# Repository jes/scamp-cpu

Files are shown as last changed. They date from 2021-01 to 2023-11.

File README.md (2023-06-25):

# SCAMP CPU

SCAMP is my homebrew 16-bit CPU. It stands for something like "Simple Computing and Arithmetic Microcoded Processor".

The CPU is very primitive. It doesn't support interrupts, and has no MMU, and no concept of privilege levels. It currently runs
at 1 MHz, above that the CompactFlash interface falls over. It runs a homebrew operating system, with a homebrew
programming language and compiler, and can self-host the kernel and all of the system utilities.
The environment tastes a bit like an early Unix, but works like CP/M. I used the computer to complete
almost all of [Advent of Code 2021](https://adventofcode.com/2021/).

My Advent of Code solutions are here: https://github.com/jes/aoc2021

I have some blog posts here: https://incoherency.co.uk/blog/tags/cpu.html and a web-based emulator available here: https://incoherency.co.uk/scamp/

Here are some pictures:

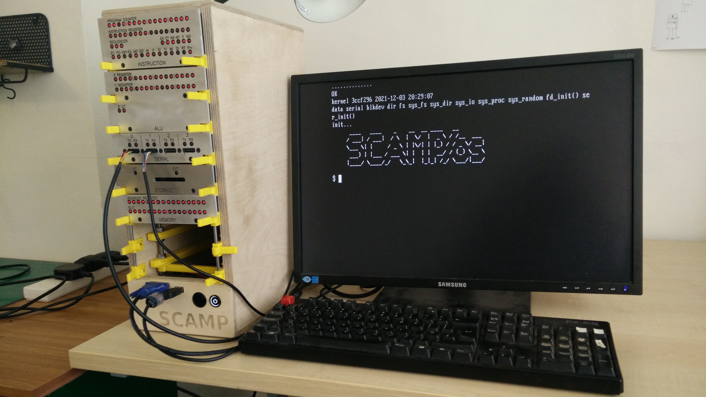
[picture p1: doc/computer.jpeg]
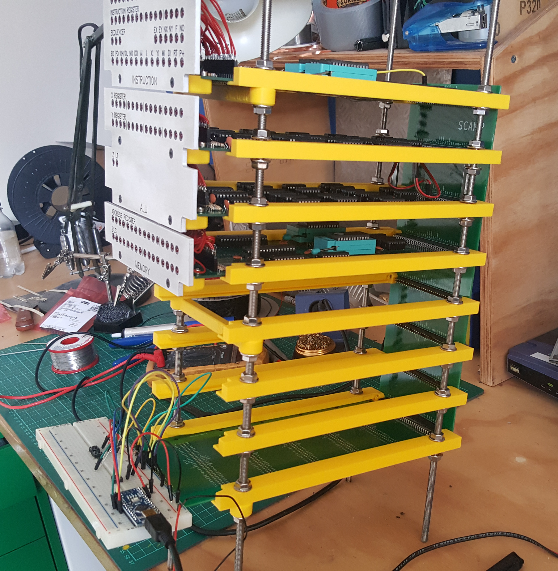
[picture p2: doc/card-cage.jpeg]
 

And here's a video with some explanation and an example session on real hardware:

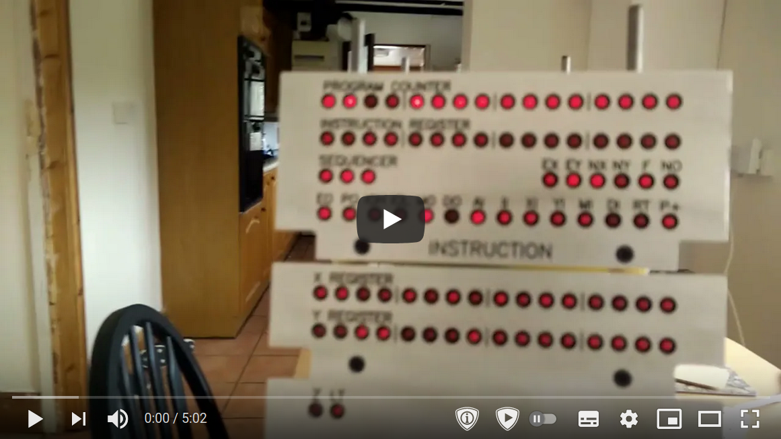
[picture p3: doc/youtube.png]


## Architecture

It is a 16-bit CPU. The bus is 16-bit, registers are 16-bit, addresses are 16-bit, and memory contents are
16-bit. The upper 8 bits of an instruction select the opcode, and the lower 8 bits are available
for small immediate values. There is no support for: cache, interrupts, virtual memory, DMA, privilege rings,
floating point, and ~anything else that is not strictly necessary.

Here is a diagram of the architecture:

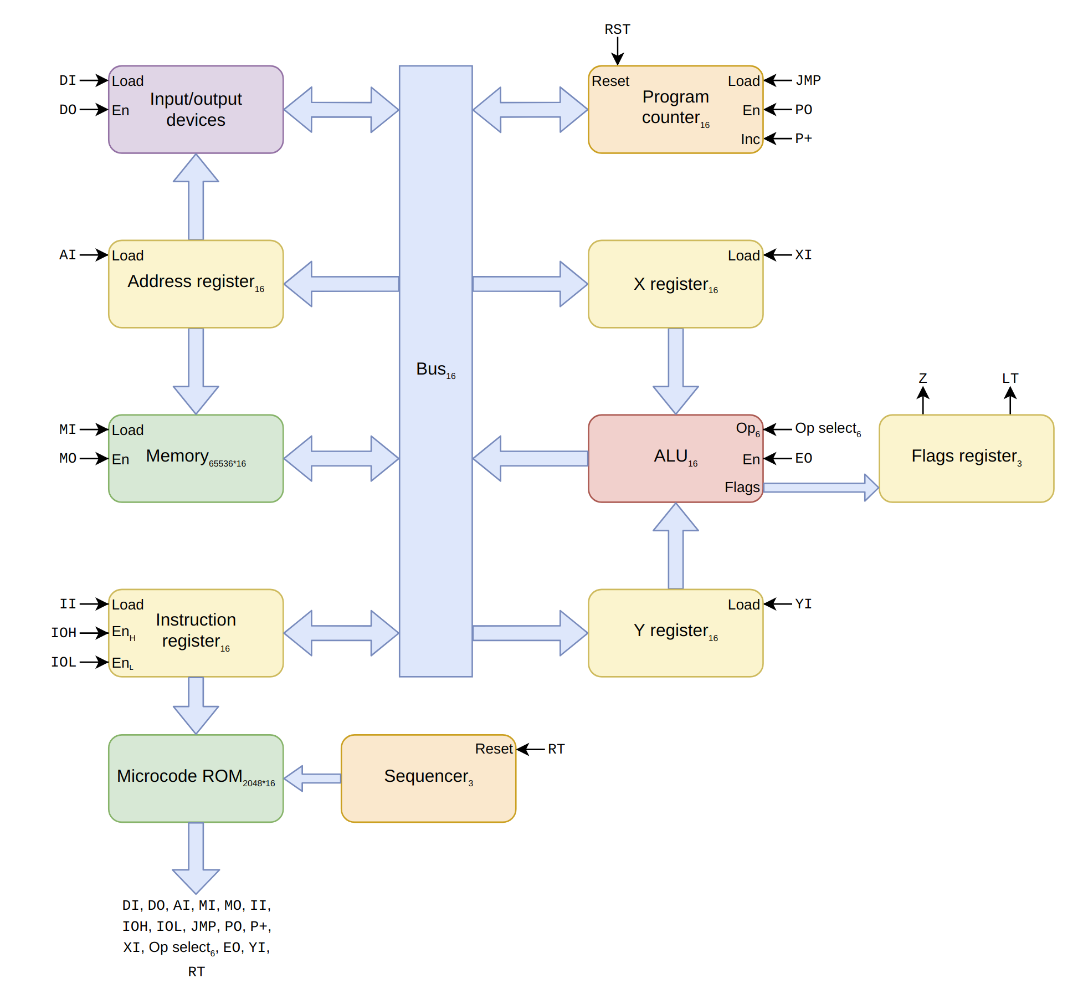
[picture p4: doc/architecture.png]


For more information, see [doc/UCODE.md](doc/UCODE.md) and [doc/ISA.md](doc/ISA.md).

## Try it out

The easiest way to try it out is to use the web-based emulator at https://incoherency.co.uk/scamp/

If you want to run it locally, first you'll need to build everything. Try `make -j` in the root directory of this
repository. It probably won't work on the first attempt because it works with multiple different Makefiles that have
annoying dependencies. Just run `make -j` twice or three times. If that doesn't do the trick, run `make` in `sys/` first, and then run
it in `.`. Once you get to the point that it is only complaining about `emcc`, you're done, unless you also
want to build the web-based emulator.

Having built everything, you can go into `kernel/` and start it in the emulator with `./run`:

    ~/scamp-cpu/kernel $ ./run
    make: 'os.disk' is up to date.
    SCAMP boot...
    .......................................................OK
    starting kernel...
    loading init...
          ____   ____    _    __  __ ____   __
         / ___| / ___|  / \  |  \/  |  _ \ / /__  ___
         \___ \| |     / _ \ | |\/| | |_) / / _ \/ __|
          ___) | |___ / ___ \| |  | |  __/ / (_) \__ \
         |____/ \____/_/   \_\_|  |_|_| /_/ \___/|___/

    $

If you know how to use Unix you'll probably understand how to use it. If you know how to use CP/M you'll probably
understand how it works.

If you want, you can write SLANG programs using `kilo` and compile them with `slc`. You've probably never written
SLANG before. You can learn how to use it by reading programs under `/src` (or `sys/` in the repo). It's mostly
like C but with fewer features and less safety.

## How it's made

I did these tasks, but working on several steps at a time (i.e. I didn't wait until after I had built the entire
computer before thinking about microcode or the operating system):

1. Create the CPU in Verilog, with a testbench for each part.
2. Replace the raw Verilog with Verilog that only uses 74xx-compatible primitives
   (e.g. https://github.com/TimRudy/ice-chips-verilog), but still passes the testbenches.
3. Convert the 74xx-Verilog into KiCad schematics (by hand).
4. Order the PCBs and components, solder up the PCBs, build a card cage, build a wooden case.
5. Settle on the instruction set and write the microcode (see [doc/table.html](doc/table.html), available online at https://incoherency.co.uk/interest/table.html).
5. Write a bootloader, kernel, shell, text editor, compiler, and various system utilities.

## Next steps

I suspect the computer will never be "finished", but some things I still want to work on are:

#### Hardware

 - [ ] build a hardware multiplication card (and maybe division?)
 - [ ] build a hardware RNG

#### Low-level software

 - [ ] make library blob self-hosting (compile within SCAMP/os)
 - [ ] write an strace-like debugging tool
 - [ ] write a DDT-like debugging tool
 - [ ] better facility for memory profiling (mainly to stop kilo and asm from running out of memory on large inputs)
 - [ ] atexit()
 - [ ] static initialisation of globals from constants (e.g. `var x = 5` at global scope should not take any code to initialise)
 - [ ] "const" variables (e.g. `const x = 5` should lead to `x` being replaced with the constant value `5` where possible)

#### Other software

 - [ ] write a big-fixed-point arithmetic library
 - [ ] fixed-point mathematics: pow,tan,asin,acos,atan,atan2
 - [ ] write a FORTH implementation (should it run on bare metal or under SCAMP/os?)
 - [ ] write a Z-machine interpreter and port some text adventures
 - [ ] write some games (pong? breakout? tetris?)

If you happen to want to work on any of the above, I'd be happy to help you!

## Resources

I thoroughly recommend the Nand2Tetris course. https://nand2tetris.org/

If you want to do the exercises from Nand2Tetris without learning what a hardware-description language
is, and without going through all the lectures, you can play https://nandgame.com/

Ben Eater's [videos on 8-bit CPU design](https://www.youtube.com/watch?v=HyznrdDSSGM&list=PLowKtXNTBypGqImE405J2565dvjafglHU) are excellent and heavily influenced
the design of my CPU.

I found the [YouTube playlist](https://www.youtube.com/playlist?list=PLOech0kWpH8-njQpmSNGSiQBPUvl8v3IM) for Nicolas Laurent's [compiler class](https://norswap.com/compilers/) quite helpful
in writing the parser for the compiler.

The [Build Your Own Text Editor](https://viewsourcecode.org/snaptoken/kilo/) is a fantastic tutorial that walks you through implementing
[antirez](https://github.com/antirez)'s [kilo](https://github.com/antirez/kilo) editor.

[Balazs Markus](https://github.com/bazsimarkus)'s [8250 UART example](https://github.com/bazsimarkus/Simple-8250-UART-System-with-Arduino) is helpful.

Daniel Tufvesson has a post that is a good starting point for understanding the [8-bit CompactFlash interface](http://www.waveguide.se/?article=8-bit-compact-flash-interface).

[PickledDog](https://github.com/PickledDog) has a description of an [improvement to the RC2014 CompactFlash card](https://github.com/PickledDog/rc-cfcard) that might be helpful. Also [Bill Shen's comment on the RC2014 mailing list](https://groups.google.com/g/rc2014-z80/c/LmvGa6PZNhQ/m/H8jrbp86AQAJ).

Michał Cierniak has a good blog post about [CompactFlash + 8255 interface card](https://ciernioo.wordpress.com/2015/02/10/compact-flash-8255-interface-card/) with lots
of detail on how his CompactFlash interface works.

[James Sharman](https://www.youtube.com/c/weirdboyjim) is building an interesting 8-bit pipelined CPU, and has good videos with lots of explanation on how it works.

SCAMP is featured on the [Homebrew CPU ring](https://www.homebrewcpuring.org/) which also features many other interesting homebrew CPU designs.

## Contact

You can email me on [james@incoherency.co.uk](mailto:james@incoherency.co.uk)
or read my blog: [https://incoherency.co.uk/].

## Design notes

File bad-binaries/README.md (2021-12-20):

This directory contains samples of bad binaries to try and help me debug
the "bad binary" problem, which is that sometimes the compiler outputs
a binary that behaves incorrectly, and then when recompiled the exact
same source code produces a binary that works fine.

My best guess is that there is a hardware problem, but currently I'm just
collecting samples in case any patterns become clear.

I had a first look at it here: https://www.youtube.com/watch?v=BiFeisFLKhY

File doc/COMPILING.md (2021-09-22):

# Compiling

This document is about compiling software within **SCAMP/os**. For more general
thoughts on the compiler, see COMPILER.md instead.

## Basic usage

    $ kilo foo.sl
    $ slc < foo.sl > foo
    $ ./foo

## Linking

To keep the library blob small, the bigint and fixed-point code is not included
by default. Ideally we'd be able to link against arbitrary combinations of
libraries, but for now the compiler only supports a single library blob, which
means if we want to support different options then we need to have a
pre-compiled blob for each possible combination.

If you need to use either the `fixed` or `bigint` libraries, then you need to
tell `slc` to select the appropriate library blob by passing it a blob name in
`-l`. Example:

    $ slc -lfixed < foo.sl > foo

Available blobs are:

             - normal library
    fixed    - normal library, plus `fixed.sl`
    bigint   - normal library, plus `bigint.sl`
    bigfix   - normal library, plus both of `fixed.sl` and `bigint.sl`

For more explanation of how linking works, see LINKING.md.

## Workings

`slc` is the compiler driver. It delegates to `slangc` to turn source code into
assembly language, and `asm` to turn assembly language into machine code. It also
brings in pre-packaged assembly language source for the "head" and "foot" of
the program, from `/lib/head.s` and `/lib/foot.s`, and library definitions
from `/lib/lib.s` (or `/lib/libfoo.s` in the case of `-lfoo`).

`head.s` is responsible for setting the start address of the program code
to 0x100, initialising the stack pointer, allocating space to store the `TOP`
variable, and defining constants for system call vectors.

`foot.s` is responsible for calling `exit(0)` after the program finishes,
and defining a constant for the initial value of `TOP`.

`lib.s` is responsible for including the library blob from `/lib/lib.o`, and
defining the addresses of the symbols exposed by the library.

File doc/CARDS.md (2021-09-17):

# Cards

## Physical dimensions

Cards are 237.49 mm long, 102.87 mm wide.

The backplane connector is at the back of the card, on the top side, in the centre. The rearmost holes
for the backplane connector pins are set forward 2.54 mm from the rear edge of the card.

Mounting holes for the front panel are set back 5.08 mm from the front edge of the card and set in 7.62 mm
from the side edge of the card. The holes are 3.2 mm in diameter, intended to take an M3 screw.

Leave a good few mm clear of components at each side of the card to slide in the guide rails.

For designing front panels, start with e.g. `front-panels/memory-panel.FCStd` and move the holes to suit
the card, then use e.g. `front-panels/memory-panel.svg` in Inkscape to lay out the text. Then engrave the
text in aluminium plate using the CNC machine (use gcodetools "path to gcode" in Inkscape) and then cut
the part out using a 4mm end mill.

Vertical spacing between cards in the backplane is 40 mm.

## ALU

The ALU is comprised of 2 identical PCBs, populated differently.

The lower card stores the low byte of the X and Y register,
and computes the low byte of the ALU output, and has the bus connection solder-jumpers connected to the low byte of the bus.

The upper card stores the high byte of the X and Y register, stores the flags register, computes the high byte of the ALU output,
and has the bus connection solder-jumpers connected to the high byte of the bus.

All parts not explicitly mentioned below must be populated on both cards (including LED connection headers and the backplane connector).

### Lower card

Do not populate U4 (flags register) or U6 (computes the Z flag). Do not populate the corresponding capacitors, C10 and C23.

Using either a male pin header or a wire, connect "carry" to "GND" on J6 (the "in" jumper). "nz"
on J6 can be left disconnected.

Install a male pin header on J7 (the "out" jumper).

Do not populate J5 (flags register LED header). Do not populate the corresponding resistors, R28 and R29.

### Upper card

Install a male pin header on J6 on the *bottom* of the card.

Do not populate J7.

### Assembly

Use 2 jumper wires to connect "nz" and "carry" from J7 of the lower card to J6 of the upper card.

Use standoffs and M3 screws to connect the two cards together using the mounting holes at the back.

Plug in the LED wires from the aluminium front panel to the appropriate headers.

Use standoffs, M3 screws, and the front panel to connect the two cards together using the
mounting holes at the front.

Hopefully the card can now slide into the chassis and connect to the backplane.

## Instruction

The EO, PO, IOH, IOL, ... header for LEDs has polarity reversed. The last pin has VCC instead of
ground, and the signals are active-low.

Unused microcode decodings can be exposed on the backplane via jumpers. The available decodings are:

| Label | Microcode | Backplane pin | Notes |
| :---- | :--- | :--- | :---- |
| i7 | bus_in==7 | 27 | |
| u8 | bit 8 | 37 | pin used for `DO` |
| o7 | bus_out==7 | 36 | |
| o5 | bus_out==5 | 35 | pin used for serial console |
| o4 | bus_out==4 | 34 | pin used for serial console |
| u1 | bit 1 | 33 | pin used for `RT` |

Microcode bit 0 is exposed on backplane pin 32 without a jumper, and the pin is now used for `DI`.

### Errata

ZIF socket holes are too small. My solution was to solder some clipped-off LED legs onto the ZIF socket
pins and then solder these to the PCB.

U8 and U9 (bus_in/out decode) should have pins 4 and 5 (chip enable) tied to VCC instead of GND.

U9 (bus_in decode) should have pin 6 (chip enable) tied to VCC instead of EO_bar.

U17 should have pin 3 output inverted:

 * pop pin 3 out of socket
 * connect pin 3 of IC to pins 9+10
 * connect pin 8 of IC to pin 3 of socket

`RT` needs to come directly from a microcode bit rather than being decoded, because it acts immediately and can "glitch".
To match current generated microcode:

 * pop pins 4+5 of U5 out of socket
 * connect pins 4+5 of U5 to the "u1" pin of "spare decodings"

We have the same problem with `DO`/`DI`, when device I/O can cause side effects. The solution is:

 * on the bottom of the card, solder a link between backplane connector pins for `DI` and `U0`
 * on the top of the card, stick a jumper on the "spare decodings" pin labelled "u8" and solder it on to the backplane
   connector pin for `DO`

## Memory

### Errata

ZIF socket holes are too small. Initially I just forced them into the holes, but this bent the legs of the
"high byte" ROM socket, and I had to replace it. Better solution is to solder clipped-off LED legs onto the
socket pins and then solder these to the PCB.

## Backplane

### Errata

Spare pin assignments:

 * 27: "spare_i7": **free**
 * 32: "U0": used for `DI`
 * 33: "spare_U1": used for `RT`
 * 34: "spare_o4": serial console
 * 35: "spare_o5": serial console
 * 36: "spare_o7": **free**
 * 37: "spare_U8": used for `DO`
 * 38: "unused": used for `WR` signal generated by serial card

## Serial

Initially, only populate the oscillator circuit on UART 0.

    Crystal: 1.8432 MHz
    Caps: 30 nF
    Resistor: 100 Ohm

Ideally, the 4 solder jumpers in the middle can be bridged, to share the 1.8432 MHz oscillator between
all of the UARTs. If that is not possible, then un-solder them and populate the other oscillators as well.

The 2x5 pin connector is for jumpers to allow easy disconnection of signals from the connector. The 1x6 connector
should go up with wires to the connector on the front panel.

Each UART has 8 addresses, consecutive starting from a base address. A7 (0x80) needs to be high to select the
UARTs, and then there's 1 bit (A3,A4,A5,A6) of address to select each UART.

Addresses:

    UART 0: A3+A7: base address = 136
    UART 1: A4+A7: base address = 144
    UART 2: A5+A7: base address = 160
    UART 3: A6+A7: base address = 192

It would probably work to initialise all of the UARTs by setting all 5 address bits high, which is base address = 248.

I plan to only install UART 0 at first, and then populate the rest of the slots as and when I want to use them.

### Errata

Use bodge wire to connect `WR` pin to backplane pin 38, marked "unused" on backplane.

Use bodge wire to connect `TX` pin of UART 0 to pin 34, marked "spare_o4" on backplane.

Use bodge wire to connect `RX` pin of UART 0 to pin 35, marked "spare_o5" on backplane.

LEDs need to be wired with signal on cathode and VCC on anode.

## Storage

1 card is internal, the other card is removable through the front panel.

Each card has 2 CS pins. A8 (0x100) needs to be high to select the CompactFlash, and then there's 1 bit
(A3,A4,A5,A6) of address to select each CS pin.

Addresses:

    Card 1, CS0: A3+A8: base address = 264
    Card 1, CS1: A4+A8: base address = 272
    Card 2, CS0: A5+A8: base address = 288
    Card 2, CS1: A6+A8: base address = 320

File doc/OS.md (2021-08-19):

# Operating System notes

We have a very short boot ROM permanently mapped into memory at address 0, 256 words long.
When the machine is reset the PC is reset to 0 which causes the boot ROM to execute.
The boot ROM's only job is to liaise with the CompactFlash card and load the kernel
from the first N KBytes from the storage into RAM and then jump to it. See [BOOT.md](BOOT.md).

The kernel contains implementations of the system calls, and space for system buffers, etc.

At startup, the kernel just executes `/bin/init`.

The intention is to support a workflow that is kind of in between CP/M and FUZIX. The filesystem
supports directories instead of CP/M's silly drive letter and user number system. The OS provides a `system()`-like call
by swapping the existing program out to disk, making a note of where to reload it from and what address to jump to, and then loading the called program.
Calling another program works a lot like calling a function, in the sense that you completely lose control until
the callee is done, and then when it's done you get returned to. We have a process *stack* instead of a process *tree*.

## Filesystem

`SCAMP/os` has a pretty Unix-like filesystem, but without annoying features like device nodes, symlinks, permissions, or
reference counting.

Example:

    /bin
        asm
        cat
        cmp
        cp
        grep
        init
        ls
        mkdir
        peepopt
        rm
        sh
        slangc
        slc
        vi
    /etc
        motd
        [other configuration?]
    /home
        [user files]
    /src
        [source code of kernel and all programs]
    /proc
        [contents of swapped-out processes]

## Programs

### init

Probably just system("cat /etc/motd") and exec("sh")

### sh

Since the shell is just a program, and programs can call other programs via the swapping-to-disk system,
the shell could quite easily support pipes and IO redirection. Currently it supports IO redirection but
not "pipes".

For the command:
    $ cat foo.txt | grep bar

The shell would first open a temporary file for writing. It would set stdout to point to that file.
It would system("cat", "foo.txt").

The kernel would then swap the shell out to disk and execute cat, whose stdout goes to the temporary
file. Once cat calls exit(), the kernel
would swap the shell back into memory and jump to the return address for the system() call.
From the shell's perspective, the system() call would return.

At this point the shell would set stdout to point back to whatever it was originally set to, and then
set stdin to point to the temporary file. It would then system("grep", "bar").

The kernel would then swap the shell out once again, and this time execute grep, whose stdin
comes from the temporary file. Once grep calls exit(), the kernel would swap the shell back in
and the second system() call would return.

This method doesn't allow for example `cat foo.txt | head` to bail out of the cat early (i.e. you don't
get a SIGPIPE when `head` is finished reading, because `head` doesn't start until `cat` is finished),
but it still provides a lot of the useful properties of program composition, without needing to support actual multitasking.

### asm/slangc/slc/peepopt

These form a complete self-hosting build environment.

    asm: assembler
    slangc: compiler
    slc: compiler driver (slangc foo.sl | peepopt > foo.s; cat head.s foo.s foot.s | asm > foo)
    peepopt: peephole optimiser (not yet implemented)

### vi

I definitely want a text editor that works like vi. It doesn't need to do everything that vim does, I'll be happy as long
as my "finger macros" mostly function correctly. I read that nobody uses more than 20% of vim's features, but the
problem is everyone uses a different 20%. Well as long as it supports the 20% that I use, I'll be happy.

Currently the editor is `kilo`, which is not very vi-like. It's more nano-like. It's adequate for now. It seems
unlikely that I'll ever make it vi-like, it seems good enough.

## IO

The kinds of places that a program might want to read or write include:

 - files on disk
 - serial devices (I want at least 2, might not be too hard to support more, and the hardware has provision for 4)

Currently serial devices are implemented with fixed file descriptors. Fd 3 is always the
serial console. It might be worth making a new file type for "device files" so that the
console can be found by opening `/dev/console` instead of assuming it's always at fd 3.
The "fixed fd" system is *OK* for now, but would not scale very well, especially given that
the fd table only has 16 slots.

I'm not sure whether interacting with a second CompactFlash card would be done via a userspace
program, or whether it would be "mounted" somewhere in the main filesystem. Currently the hardware
has 2 slots for CompactFlash cards, but there is a serious problem with the second one which means
the computer does not work if the second CF card is installed. Need to debug this.

## Process state

When a process is swapped out, in addition to storing the contents
of the Transient Program Area (0x100 up to `TOP`) in `/proc/$n.user`,
we need to store some state about the process in `/proc/$n.kernel` (see
`kernel/sys_proc.sl`):

 - current stack pointer
 - return address from `system()` call
 - current working directory
 - contents of fd table
 - command line arguments

## Conventions

"Executables" work exactly like COM files in CP/M: just load them into 0x100 and jump to the start.

Command line arguments are stored by the kernel. A pointer to the
array of string pointers is retrieved with the `cmdargs()` syscall.

There is no such thing as environment variables.

Shebangs work.

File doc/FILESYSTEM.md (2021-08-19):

# Filesystem

The filesystem consists of 512-byte blocks.

The first 64 blocks (32K) on the device are ignored. They're used to store the kernel.

The next 16 blocks (8K) are a bitmap saying which of the rest of the blocks are already in use.

The next up-to-65536 blocks (32M) are the filesystem contents.

Where the device is smaller than 32M, the bitmaps should mark the unavailable blocks as "in use".

The first 4 bytes of each block are decoded as follows:

    |    type       |  length       |       next block pointer      |
    |. . . . . . . .|. . . . . . . .|. . . . . . . .|. . . . . . . .|

(Although 8 bits are currently allocated for "type", only types 0 (directory) and
1 (file) are assigned; the upper 7 bits are currently unused).

"length" is 8 bits, indicating how many words of the current block is to be used for
this node, not including the header.

"next block pointer" contains the number of the next block that forms part of this
file or directory, or 0 if this is the last block.

See below for examples.

Block 0 is the root directory of the filesystem.

## Type 0 (directory)

After the 4 byte header, the remaining 508 bytes consist of up to 15 directory entries.

The length field is ignored. The "next" block (if nonzero) contains more files for
the same directory.

Each directory entry has a filename (up to 30 bytes) and a block pointer (2 bytes). Filenames
are nul-terminated strings. The empty filename indicates a directory entry is not in use.

## Type 1 (file)

After the 4 byte header, the remainder of the block (up to the amount set in the "length"
field) are file contents. Where blocks are chained together, the current block's contents
come first, and then the next block.

A block containing a file that just contains the character "A" would look like:

    |    type       |  length       |       next block pointer      | ... data ...  |
    |0 0 0 0 0 0 0 1|0 0 0 0 0 0 0 1|0 0 0 0 0 0 0 0 0 0 0 0 0 0 0 0|0 1 0 0 0 0 0 1|

    type = 1 (file)
    length = 1
    next = 0
    data = 'A'

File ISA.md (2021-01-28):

# Instruction Set Architecture

Each word is 16 bits wide.

The high 8 bits of the opcode select the actual opcode. The low 8 bits are available
for an immediate small-valued constant. XXX: We could change this to 9/7 or 10/6 if
we need more opcode space.

## Addressing modes

There are kind of 2 orthogonal questions here: 1 is where the address comes from, and the other
is how many levels of indirection it takes.

Numbers can come from:
 * the low bits of the instruction word (IOH)
 * the low bits of the instruction word (IOL)
 * an operand word
 * the X register
 * the Y register

Levels of indirection:
 * immediate value
 * 1 trip through RAM
 * 2 trips through RAM
 * 3 trips through RAM
 * 1 trip through RAM with pre-/post- increment/decrement
 * 2 trip through RAM with pre-/post- increment/decrement of pointer
 * 2 trip through RAM with pre-/post- increment/decrement of value

We could consider "hiding" the Y register, so that it can always be clobbered without needing
an excuse. And then the opcode space saved by removing instructions that store to Y can for
example be used for instructions that instead fetch indirect values into Y. It would probably
be worth writing some simple-ish programs in the instruction set as defined here and seeing if
there are any obvious candidates for creating instructions that do the job of 2 at once.

Even if we don't hide "Y", it should be a point of philosophy that instructions will clobber the
Y register in preference to the X register where there is a free choice.

Apart from instructions that do specifically require an imm8h, we should flesh out the instruction
set with all immediate values as imm16, and then add optimised versions later for common
operations.

We could consider the imm8h addresses to be "registers", and make a "r0" .. "r255" syntax for
addressing them. So then instead of "add x, (0xff00)", you'd be able to write "add x, r0" and
it all becomes much easier to read. It also clarifies the difference between the (imm16) and (imm8h)
addressing modes, and we could potentially make the assembler warn if you use a (imm16) that is in
the top page.

## Instruction table

I'd like to produce a table like the one on https://clrhome.org/table/

It's a grid indexed by opcode, with each cell in the grid indicating the instruction
with that opcode. Destinations are the first argument, e.g. "ld a, b" means load the contents
of b into a. Indirection is given with parentheses, e.g. "ld (hl), a" means load the contents
of a into memory at the address stored in hl.

Hovering over an instruction pops up a box with more information. Information I would want to
show includes:

 * opcode in hex
 * instruction length in words
 * clock cycles to execute it (including 2 for fetch)
 * whether it clobbers or not for each of X, Y, flags, and memory (do we
    make a distinction between "writes to" and "clobbers"? e.g. "ld x, *" writes to X, so
    you lose what was already in X, but it's not exactly "clobbered"), and the nature of
    the clobber (e.g. if the new value might be useful)
 * a short description of what it does
 * the microcode implementing it, source and hex

Ideally this would all be auto-generated from information in the microcode source.

It would also be cool if the assembler could use the microcode source to define the available
opcodes, with as little hardcoding as possible.

## Instructions

The registers are called "x" and "y". Immediate values
are called "imm8l" if produced with "IOL" (0 to 255), "imm8h" if produced with "IOH" (0xff00 to
0xffff), or "imm16" if produced with an extra word operand, in which case the operands
should appear in the machine code in the same order as they appear in the mnemonic.
"r" means one of the pseudo-registers r0 to r255, which is equivalent to an "(imm8h)" argument.
"sp" means r255, i.e. "(0xffff)".

The assembly language should be as orthogonal as possible, with the assembler responsible for
deciding which opcode to use, e.g. "ld x, 5" can be accomplished with both "ld x, imm8l" and
"ld x, imm16".

The instructions listed below are currently aspirational. The list might have to be cut down if
the opcode space is not large enough, and some opcodes might not be implementable without
exceeding 6 T-states. We also might be able to add more if there is opcode space left over.

Where instructions clobber an address in memory (e.g. xor), there should probably be a
default that is normally used, and also some syntax to choose an alternative.

We should make sure that where 2 opcodes can perform an equivalent operation (e.g. "ld x, imm8h"
and "ld x, imm16") that the shorter/faster/better one has the lower opcode, so that the assembler
can know to always choose the smallest opcode that can fulfill an instruction.

In total we currently have 165 opcodes.

### Load/store

42 opcodes:

    ld x, y
    ld y, x
    ld x, imm16
    ld y, imm16
    ld x, (imm16)
    ld y, (imm16)
    ld x, ((imm16))
    ld y, ((imm16))
    ld (x), x
    ld (x), y
    ld (y), x
    ld (y), y
    ld (imm16), x
    ld (imm16), y
    ld ((imm16)), x
    ld ((imm16)), y
    ld x, pc
    ld y, pc
    ld x, (imm16+x)
    ld y, (imm16+x)
    ld x, (imm16+y)
    ld y, (imm16+y)
    ld x, ((imm16)+x)
    ld y, ((imm16)+x)
    ld x, ((imm16)+y)
    ld y, ((imm16)+y)
    ld x, (imm16)++
    ld x, (imm16)--
    ld y, (imm16)++
    ld y, (imm16)--
    ld x, r
    ld y, r
    ld r, x
    ld r, y

### Jump

34 opcodes:

    jmp imm16
    jz  imm16
    jnz imm16
    jgt imm16
    jlt imm16
    jge imm16
    jle imm16
    jc  imm16
    jmp (imm16)
    jz  (imm16)
    jnz (imm16)
    jgt (imm16)
    jlt (imm16)
    jge (imm16)
    jle (imm16)
    jc  (imm16)
    jmp (x)
    jz (x)
    jnz (x)
    jgt (x)
    jlt (x)
    jge (x)
    jle (x)
    jc (x)
    jmp (y)
    jz (y)
    jnz (y)
    jgt (y)
    jlt (y)
    jge (y)
    jle (y)
    jc (y)
    jr imm8l # imm8l is a positive offset
    jr imm8l # imm8l is a negative offset

### Arithmetic

20 opcodes:

    inc x
    inc y
    dec x
    dec y
    inc (x)
    inc (y)
    dec (x)
    dec (y)
    inc (imm16)
    dec (imm16)
    add x, x
    add x, y
    add x, imm16
    add x, (imm16)
    add x, (imm16)++
    add x, (imm16)--
    sub x, y
    sub x, (imm16)
    sub x, (imm16)++
    sub x, (imm16)--

So far this mostly includes register and immediate-mode arguments. If opcode space
allows, we could add some memory operands for either source or destination, as well
as opcodes for the more elaborate ALU operations like "X+Y+1", "-X-Y-2".

The assembler could also provide "sub r, imm16" as "add r, -imm16" and
"sub r, r" as "ld x, 0".

### Logic

42 opcodes:

    and x, y
    and y, x
    and x, imm16
    and y, imm16
    or x, y
    or y, x
    or x, imm16
    or y, imm16
    not x
    not y
    nand x, y
    nand y, x
    nand x, imm16
    nand y, imm16
    nor x, y
    nor y, x
    nor x, imm16
    nor y, imm16
    xor x, y
    xor y, x
    xor x, imm16
    xor y, imm16

Again we could add some memory operands if opcode space allows.

### I/O

10 opcodes:

    in x, imm16
    in x, y
    in y, imm16
    in y, x
    out x, y
    out y, x
    out imm16, x
    out imm16, y
    out imm16, imm16
    out imm16, imm16

Device numbers and data are both 16 bits wide.

The first argument refers to the place that receives the data, so "out" takes the device number
first and "in" takes it second. We could look at the kinds of I/O that are likely to be common
and see if adding any memory operands would be helpful. In particular, the large block copy
of the TPA to disk should be optimised.

### Stack

11 opcodes:

    push x
    push y
    push r
    push (x)
    push (y)
    push (r)
    push imm16
    push (imm16)
    pop x
    pop y
    pop r
    pop (x)
    pop (y)
    pop (r)
    pop (imm16)
    ret

The stack pointer is always r255.

"push" post-decrements sp, and "pop" pre-increments it. "ret" is basically just "pop pc".

### Misc

1 opcode:

    nop

## Special instructions

5 opcodes:

    djnz x, imm16
    djnz y, imm16
    djnz (imm16), imm16
    tbsz r, imm16
    sb r254, imm8l

Decrement and jump if not zero. Test bits and skip if zero. Set bits in M[0xfffe].

Also consider making single instructions that do things like:

    ld (imm16), x
    inc (imm16)

or
    ld x, (imm16)
    inc (imm16)

## ALU & Load

We could easily make instructions like:

    ld (imm16), x+y
    ld (imm16), x-y
    ld (imm16), x-1
    ld (imm16), x+1
    ld (imm16), y-1
    ld (imm16), y+1
    ...
    ld x, (imm16)+y
    ld x, (imm16)-y
    ld y, (imm16)+x
    ld y, (imm16)-x
    ld x, (imm16)-1
    ld x, (imm16)+1
    ...

For all of the sensible ALU operations. Just a case of working out which ones are useful

## Calling convention

The microcode is a bit too restricted to make an instruction that would push PC+2 and jump to an
argument, so the general method of calling would be to have the assembler generate the hardcoded
return address, and push it, and then jump to the callee.

In general, calling is:

    0: push (SP), 4 # push (SP), imm16
    2: jmp imm16
    4: ...

In the event that position-independent code is required, use something like:

    0: ld x, pc
    1: add x, 4      # with the "add x, imm8l" opcode (1 word)
    2: push (SP), x
    3: jmp imm16
    5: ...

The "ret" instruction can be used to return to the caller. It pops the return address
from the stack and jumps to it.

    0: ret

### Shift-right

These 2 instructions are kind of a bodge to support shift-right:

tbsz (test bits and skip if zero), sb (set bits)

tbsz takes the address of the value from IOH, and a bitmask as an argument, and skips the program
counter over the next 1-word instruction if none of the bits set in the value are also set in
the bitmask (i.e. if "val & mask == 0").

sb is a 1-word instruction that computes "M[0xfffe] |= IOL", i.e. OR's some of the lower
8 bits set in IOL into the value in M[0xfffe].

Use it by repeatedly tbsz of some value in the upper 8 bits, followed by sb of the
same value in the lower 8 bits:

    tbsz(0xff) 0x8000 # skip next if !(M[0xffff] & 0x8000)
    sb(0x80)          # M[0xfffe] |= 0x80
    tbsz(0xff) 0x4000 # skip next if !(M[0xffff] & 0x4000)
    sb(0x40)          # M[0xfffe] |= 0x40
    ...

so the >>8 operation takes up to 8*(8+6) = 112 cycles, plus setup time

### CISC

The microcode potentially gives us a lot of freedom to do more complicated things:

djnz of X: (Decrement and jump if not zero)

    [opcode] [jump target]

    1. ALU=X-1 EO XI    load X-1 into X
    2. PO AI            load address from PC (jump target)
    3. MO JGT JLZ P+    jump to address from RAM if X-1 != 0, else inc PC

Could we do something like ldir from Z80 (i.e. copy a block of data using 1 instruction that
keeps jumping to itself until the block is done)? My sense is no, because there aren't enough
registers or T-states. But it might be possible. Also might be possible to make a pair of
special-purpose instructions, like tbsz and sb, that make block copies faster than the simple way.

## Assembly language

Each line is 1 instruction or 1 assembler directive. Each line optionally begins
with 1 or more labels. The label will refer to the address at which the assembly code
for that point will be loaded into memory.

A "#" character begins a comment that runs to the end of the line.

## Directives

### .def WORD TEXT

Preprocessor macro. All subsequent occurrences of "WORD", at word boundaries, will be
replaced verbatim with the TEXT, with excess spaces stripped.

Example:

    .def SP 0xff00     # stack pointer at 0xff00
    .def SP_x (SP), x

Would transform:

    push (SP), x
    push SP_x

into:

    push (0xff00), x
    push (0xff00), x

### .org VALUE

Set the address at which the first word of the generated output will be loaded into memory.

Example:

    .org 0x100

### .at VALUE

Set the address at which the next word should be loaded into memory. Use in combination with
.org to make sure everything is where you expect.

Example:

    .org 0x100
    ld x, (ptr)
    out 0x80, (x)
    ...
    ptr: .word 0x200
    .at 0x200
    .str "Hello, world!"

Padding words with value 0x0000 will be generated between the location of "ptr" and the
"Hello, world!" string, such that the string will be located at address 0x200 if the generated
output is loaded at 0x100 (i.e. the string will be 0x100 words into the generated output).

### .gap VALUE

Leave a gap of N unused words

Example:

    .at 0x200
    buffer: .gap 256

Creates a 256-byte buffer at address 0x200, with the label "buffer".

### .str "TEXT"

Generate the given string, with 1 character per word (i.e. the upper 8 bits of each value is
always zeroes).

Example:

    msg: .str "Hello, world!\n"

### .pstr "TEXT"

Generates a "packed string", with 2 characters per word, with the first character of the string in
the upper 8 bits of the first word (i.e. big endian).

Example:

    msg: .pstr "Hello, world!\n";

### .word VALUE

Generate a literal word.

Example:

    value: .word 0x1010

Will generate a word containing 0x1010, whose address will be available in the "value" label.

## Labels

Labels and macro names must match

    /^a-zA-Z_[a-zA-Z_0-9]*$/

i.e. begin with uppercase, lowercase, or underscore, and then contain only uppercase, lowercase, underscore, and numeric.

## Values

Values are decimal by default.

Hex values are written starting with "0x", and binary values starting with "0b".

All numeric values are 16 bits long, but in special cases the assembler may put them in an imm8l
or imm8h where possible.

Inside strings, the following escape sequences are available:

* "\\" - literal backslash
* "\r" - 0x0d value
* "\n" - 0x0a value
* "\t" - 0x09 value
* "\[" - 0x1b value
* "\x.." - literal hexadecimal 8-bit value
* "\w...." - literal hexadecimal 16-bit value (not allowed in packed strings)
* "\0" - literal 0, same as "\x00"

Example values:

    .word 100
    .word 0x123
    .word 0b1010111100000101
    .str "ABC\wffffDEFG\r\n\0"
    .pstr "ABCD\x1b\n\0"

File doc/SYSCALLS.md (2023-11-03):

# System calls reference

System calls are made by pushing arguments onto the stack, in the order specified
in the reference, and calling the function pointed to at the system call address.

Example:

    # write(1, "foo", 3);
    .def sys_write 0xfefb
    push 1
    ld x, foo_s
    push x
    push 3
    call (sys_write)
    # ...
    foo_s: .str "foo\0"

Note that stack contents will be in TPA, so system calls that overwrite the TPA
probably need to copy the arguments first.

System calls must act like normal SLANG functions: `r255` (`sp`) must consume the passed
arguments. `r254` must be left alone. Other pseudoregs can be trashed at will.

## System calls

### 0xfeff: exit(rc)

    Return: n/a
    Implemented: yes
    Errors: n/a

Exit the current process and return `rc` to the parent. Negative values of `rc` are discouraged
as they are indistinguishable from an error value returned by `system()`.

### 0xfefe: exec([cmd, args])

    Return: -ERR on error
    Implemented: yes
    Errors: NOTFOUND

Replace the current process with a new one.

`cmd` should be a filename. `args` should be terminated with a 0.

### 0xfefd: system(TOP, [cmd, args])

    Return: rc of child process, or -ERR on error
    Implemented: yes
    Errors: NOTFOUND

Suspend the current process, start a child. When the child calls `exit(rc)`, resume the
current process and return `rc`.

`cmd` should be a filename. `args` should be terminated with a 0.

### 0xfefc: getcwd(buf, sz)

    Return: 0, or -ERR on error
    Implemented: yes
    Errors: TOOLONG

Work out the current working directory and store it in `buf`. Behaviour is undefined
if the current working directory or one of its parents has been deleted. Return `TOOLONG`
if the path is too long to fit in `buf` with a trailing 0.

### 0xfefb: write(fd, buf, sz)

    Return: 0, or -ERR on error
    Implemented: yes
    Errors: BADFD

Write multiple characters to the given file descriptor.

Avoid writes larger than 2^15-1 because the return value will be indistinguishable
from an error value.

### 0xfefa: setbuf(fd, buf)

    Return: 0, or -ERR on error
    Implemented: yes
    Errors: BADFD

Set the buffer to use for the given `fd`. If `buf` is 0, the `fd` will be unbuffered, and all
writes and reads will go directly to disk. If `buf` is nonzero, it should point to a buffer of
at least **257** words.

### 0xfef9: read(fd, buf, sz)

    Return: number of characters read, or -ERR on error
    Implemented: yes, but serial needs cooked mode
    Errors: BADFD

Read multiple characters from the given file descriptor.

If `sz` is 0, returns a number of characters that can be read immediately. For a serial port,
this means you can read this many characters without blocking. For a file, it means there are at
least this many characters left in the file.

Avoid reads larger than 2^15-1 because the return value will be indistinguishable
from an error value.

### 0xfef8: open(name, mode)

    Return: new file descriptor, or -ERR on error
    Implemented: mostly
    Errors: NOTFOUND

Open the file at the given path with the given mode.

Mode flags are:

    0x01: O_READ    - support read()
    0x02: O_WRITE   - support write()
    0x04: O_CREAT   - create the file if it doesn't exist
    0x08: O_NOTRUNC - with O_WRITE: don't truncate the file if it already exists

### 0xfef7: close(fd)

    Return: 0, or -ERR on error
    Implemented: yes
    Errors: BADFD

Close the given file descriptor.

### 0xfef6: sync(fd)

    Return: 0, or -ERR on error
    Implemented: yes
    Errors: BADFD

Sync the buffer for the given `fd`. If `fd` is -1, sync all `fd`s.

### 0xfef5: rename(oldname, newname)

    Return: 0, or -ERR on error
    Implemented: yes
    Errors: BADFD, NOTFOUND, NOTDIR, EXISTS

Rename the file from `oldname` to `newname`, moving it to a different directory
if required. In the event that we ever support mounting filesystems from multiple
devices, this call will not permit moving the file across devices.

### 0xfef4: chdir(path)

    Return: 0, or -ERR on error
    Implemented: yes
    Errors: NOTFOUND, NOTDIR

Change the current working directory.

### 0xfef3: mkdir(path)

    Return: 0, or -ERR on error
    Implemented: yes
    Errors: NOTFOUND, NOTDIR, EXISTS

Create a directory at the given path.

### 0xfef2: opendir(path)

    Return: new file descriptor, or -ERR on error
    Implemented: yes
    Errors: NOTFOUND, NOTDIR

Open the directory at the given path for reading.

### 0xfef1: readdir(fd, buf, sz)

    Return: number of entries read, or -ERR on error
    Implemented: yes
    Errors: BADFD

Read entries from the given directory fd into buf. Each directory entry is a nul-terminated
string containing the filename. `buf` will contain N concatenated nul-terminated strings.

To read the entire directory, call `readdir()` repeatedly until 0 directory entries are returned.

It is not sound to add or remove files to the directory while the directory is open.

### 0xfef0: stat(path, buf)

    Return: 0, or -ERR on error
    Implemented: yes
    Errors: NOTFOUND

Fill in `buf` with information about the file at the given path.

Fields are:

    0: file type (0 = dir, 1 = file)
    1: length of file in words
    2: length of file in blocks
    3: block number of start of file

### 0xfeef: unlink(path)

    Return: 0, or -ERR on error
    Implemented: yes
    Errors: NOTFOUND, EXISTS

Remove the file at the given path. Return `EXISTS` if the path is a non-empty directory.

### 0xfeee: copyfd(destfd, srcfd)

    Return: the new fd, or -ERR on error
    Implemented: yes, but dubious
    Errors: BADFD

Make `destfd` go to/from the same place as `srcfd`. If the passed `destfd` is negative, then
a new fd will be allocated.

By convention programs should take input from fd *0*, output to fd *1*, and send error messages
to fd *2*. Fds *3..n* should be permanently mapped to serial ports, with fd *3* being the
console.

Example: To make stdin and stderr go to the console, but stdout go to a file, and then
restore it later

    var logfd = open("log", O_WRITE|O_CREAT);
    var old_stdin  = copyfd(0, 3);
    var old_stdout = copyfd(1, logfd);
    var old_stderr = copyfd(2, 3);
    # ...
    # now stdin/err are console, and stdout is the file 
    # ...
    copyfd(0, old_stdin);
    copyfd(1, old_stdout);
    copyfd(2, old_stderr);
    close(logfd);
    # now the original configuration is restored

### 0xfeed: osbase()

    Return: the first address above the TPA
    Implemented: yes
    Errors: n/a

Return the first address of the OS, i.e. the lowest address that the user heap is not allowed
to grow into.

### 0xfeec: cmdargs()

    Return: pointer to argument list
    Implemented: yes
    Errors: n/a

Return a pointer to the argument list, including the command name, exactly as passed to `exec()`/`system()`.

Example:

    system(["/bin/ls", "-l", "/home", 0]);

    cmdargs() returns ["/bin/ls", "-l", "/home", 0]

### 0xfeeb: serflags(fd, flags)

    Return: previous `flags`, or -ERR on error
    Implemented: yes
    Errors: BADFD

If `fd` refers to a serial port, set the flags to `flags`. `flags` is a bitmask of:

    SER_COOKED  = 1; # enable cooked mode
    SER_DISABLE = 2; # disable serial device in kernel (e.g. for direct I/O)
    SER_LONGREAD = 4; # make read() calls block and fill the buffer before returning

To find out what `flags` is set to without changing it, just set it to 0 and then back
to the previous value:

    var flags = serflags(fd, 0);
    serflags(fd, flags);

### 0xfeea: random()

    Return: random integer in range 0 .. 0xffff
    Implemented: yes
    Errors: n/a

Return a random integer. Input on serial ports permutes the state of the RNG, so if
you try to use the RNG before any input is observed, it won't be very random.

### 0xfee9: blkread(blknum)

    Return: pointer to block content
    Implemented: yes
    Errors: n/a

Read a block (256 words) from disk and return a pointer to its contents.
Blocks 0-63 are reserved for storing the kernel.
Blocks 64-79 are the free space bitmap.
Blocks 80+ are disk contents.

### 0xfee8: blkwrite(blknum, data)

    Return: 0
    Implemented: yes
    Errors: n/a

Write a block (256 words) to disk. Use carefully.
Blocks 0-63 are reserved for storing the kernel.
Blocks 64-79 are the free space bitmap.
Blocks 80+ are disk contents.

### 0xfee7: trap(func)

    Return: 0
    Implemented: yes
    Errors: n/a

Set the trap function. This is a function that will be called, with no
arguments, when ^C is typed at the console. Set `func` to 0 to revert
to the default behaviour of exiting. The trap function need not return,
but should make sure to set the stack pointer to something sensible if
it doesn't.

### 0xfee6: savetpa(filename, TOP)

    Return: 0, or ERR on error
    Implemented: yes
    Errors: NOTFOUND? NOTDIR? TOOLONG?

Save the TPA to the given filename.

### 0xfee5: getpid()

    Return: pid
    Implemented: yes
    Errors: n/a

Return the PID of the current process.

## Errors

Errors are generally returned from system calls as `-ERR`, with the following meanings:

### -1: EOF

Reached end-of-file.

### -2: NOTFOUND

File with given name does not exist.

### -3: NOTFILE

The given path exists but is not a file (e.g. it's a directory).

### -4: NOTDIR

The given path exists but is not a directory (e.g. it's a file).

### -5: BADFD

File descriptor not allocated, or requested operation not available on this fd.

### -6: TOOLONG

A path component was too long.

### -7: EXISTS

Path already exists.

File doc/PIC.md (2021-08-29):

# Position-independent code

I think I want to implement `strace`, by having it rewrite all the system call
vectors so that they point to `strace`'s shims that output the arguments
to the console and then call the real system call.

So `strace ls` would:

1. copy the shims into the top of memory so that they don't get overwritten by
the child process
2. overwrite system call vectors so that they point to the shims
3. `system("ls")`
4. when `ls` makes any system calls, the shims will output them to the console
5. when `ls` exits, undo the shims and set `osbase()` back to what it was before

Step 1 is the tricky one: if we copy the shims right below the start
of the kernel, then all the addresses in the code depend on where the kernel starts.
One solution is to hardcode the start address of the shims, but this means they
need to be recompiled every time the kernel gets larger.

Another solution is to make the shims position-independent. I think that's totally
feasible so I want to do it.

## Working out where you are

Just call any system call and look in `r254` after it returns:

    call (0xfeed) # call osbase()
    # r254 now contains the address of the next instruction

Even in the absence of the kernel, you can work out where your code is by creating a
`ret` instruction, calling it, and then looking in `r254` after control is returned:

    ld (0xff00), 0xf400 # create a "ret" instruction into r0
    call 0xff00         # call the "ret" instruction
    # r254 now contains the address of the next instruction

This is mildly unpleasant because it requires hard-coding the opcode for `ret`,
and that occasionally changes if I rearrange the instruction table, but it'll
do for now. Maybe we could have some support in the assembler so we can refer to it
as `RET_OPCODE` or something.

## Relative address accesses

Working out where you are in memory is one thing, but after that all memory accesses
need to be relative to this base address, which we don't have any CPU support for.

Options include:

1. Keep a list of all addresses and patch them one-by-one so that they now point
to the correct place. This sounds hairy but I think isn't *too* bad, other than
that the assembler doesn't have any way to make it easy for us. Probably we'd
have some other program generate the code, which would take care of remembering all
the addresses that need patching.

2. Store the offset at some fixed address and make all access relative to that.
The obvious candidates for fixed addresses are the pseudoregisters, but these
can be clobbered by function calls. So maybe you'd designate (say) `r1` to hold
the base address, and push `r1` before every function call and pop it after?
This seems strictly worse than patching the addresses because it comes with a
performance hit on every access & every function call, and makes the code more
annoying to write.

## Patching addresses

I think we'd assemble the code with the assumption that it starts at 0xfffe, so
that when the (2-word) `call` instruction returns, the base address is relative to 0.
Something like:

    .at 0xfffe
    .def osbase (0xfeed)
    call osbase
    # we now have the base address offset in r254 and osbase() address in r0

    # find the address of the list of addresses to patch
    ld r2, patch_addrs
    add r2, r254

    # add r254 to each word that needs patching
    patch_loop:
        add (r2), r254
        inc r2
        test (r2)
        jnz patch_loop

    [... rest of code goes here, without regard for position-independence ...]

    patch_addrs:
        # this is a zero-terminated list of addresses that need to have the
        # base address added - it should be generated by the "assembler" rather
        # than hand-maintained
        .word 0x000a
        .word 0x000f
        .word 0x0013
        .word 0x0016
        [...]
        .word 0

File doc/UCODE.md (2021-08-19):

# Microcode

Microcode is stored in a ROM.

The immediate small-valued constant, from the low 8 bits of the instruction, can
be placed on the bus either as 00xx or FFxx using the IOL and IOH control bits respectively.

The top 256 words of RAM are available to act as "pseudo-registers", which can be
conveniently accessed with a single-word instruction, e.g.:

    1. IOH AI (put FFxx into MAR)
    2. MO  YI (put RAM contents into Y register)

The T-state counter (or "sequencer") counts from 0 to 7 and then wraps. The first 2 states of every instruction
are required to be:

    1. PO AI
    2. MO II P+

In order to fetch the next instruction. These are provided implicitly by the microassembler (see
[ucode/uasm](ucode/uasm)).

## Addressing

The upper 8 bits of the microcode address indicate the opcode, lower 3 bits indicate the T-state.

11 bits of address space = 2048 words. Each address contains 16 bits of microcode (spread
over 2x 8-bit ROM chips).

Each microinstruction just switches on/off the CPU's control bits. Not all bits
can be on at the same time, because this would be nonsensical at best, and cause
bus fighting at worst.

## Microassembler syntax

Comments begin with "#" and run to the end of the line.
All excess whitespace is ignored.

Each instruction begins with a name for the instruction. This name sets the syntax needed to use
this instruction via the assembler, and is shown in the cheatsheet.
The name is followed by a colon, optionally followed by the number for the opcode. These
are represented in hex and, where present, are required to count up sequentially starting from 0. Example:

    clc: 0a    # The 'clc' instruction has opcode 0x0a

A comment on the same line as the instruction name turns into the text
that eventually appears at the bottom of the "hover" box on the instruction set cheatsheet.

A line in the microcde that says " # clobbers: ..." turns into an indication in the cheatsheet
that that instruction clobbers the given register. This is only required where it can't be
worked out automatically by `mk-table-html`, e.g. for r254.

Each microinstruction consists of several control bits, e.g.

    PO AI

Turns on the "PO" (program counter output to bus) and "AI" (address register input from bus)
bits, with the result that the address register takes the value from the program counter.

The "xO" and "xI" bits are encoded into the microinstruction, see the "Decoding" section,
so only one "xO" and one "xI" may be present at a time. The microassembler enforces this.

When not specifying any "xO", ALU operations become available. Specify ALU operations in
relatively-natural syntax, e.g.:

    X+Y     # compute X+Y
    X       # pass X straight through the ALU
    ~(X|Y)  # compute X nor Y

This syntactic sugar automatically enables "EO" and the relevant function selection flags, although
this can be done manually. The above examples are equivalent to:

    EO EX EY F      # compute X+Y
    EO EX F         # pass X straight through the ALU
    EO EX NX EY NY  # compute X nor Y

There is also syntactic sugar for "JNZ" which is equivalent to "JLT JGT", and for "JMP"
which is equivalent to "JZ JLT JGT".

Other than that, the microinstruction flags available should exactly match the control bits
documented below. The microassembler should give a warning or error message if you do
something wrong.

## Control bits

| Name | Meaning |
| :--- | :--- |
| PO | Program counter output to bus |
| IOH  | Immediate small value from instruction register output to bus with high bits set to 1 |
| IOL  | Immediate small value from instrugtion register output to bus with high bits set to 0 |
| MO | Memory output to bus |
| DO | I/O device output to bus |
| EO | ALU output to bus |
| :--- | :------ |
| AI | Address register input from bus |
| MI | Memory input from bus |
| II | Instruction register input from bus |
| XI | X register input from bus |
| YI | Y register input from bus |
| DI | I/O device input from bus |
| :--- | :------ |
| P+ | increment program counter |
| RT | reset T-state counter |
| JZ | jump if zero |
| JGT  | jump if greater than zero |
| JLT  | jump if less than zero |
| :--- | :------ |
| EX | ALU flag: enable X (don't set X to 0) |
| NX | ALU flag: invert bits of X |
| EY | ALU flag: enable Y (don't set Y to 0) |
| NY | ALU flag: invert bits of Y |
| F | ALU flag: function select (0 for '&', 1 for '+') |
| NO | ALU Flag: invert bits of output |

## Decoding

Every instruction implicitly starts with microcode of:

    PO AI     load address from program counter
    MO II P+  load RAM into instruction register, increment PC

So I don't think we need to include that in the microcode. We could just do that for 2 cycles,
and then start the "real" T-state counter. Maybe it's easier to waste decode ROM space on it
than to make hardware logic to decide?

In general each step of microcode assumes the form:
    - choose a module to write to the bus (xO)
    - choose a module to read from the bus (xI)
    - choose ALU flags
    - choose whether to increment the PC (P+)
    - choose jump flags
    - choose whether to reset the T-state counter (RT)

The microcode instruction word encodes the control bits as follows:

| Bit | Meaning |
| :---- | :--- |
| 15 | !EO |
| 14 | EO ? EX : bus_out[2] |
| 13 | EO ? NX : bus_out[1] |
| 12 | EO ? EY : bus_out[0] |
| 11 | EO ? NY : (unused) |
| 10 | EO ? F  : P+ |
| 9 | EO ? NO : (unused) |
| 8 | DO |
| 7 | bus_in[2] |
| 6 | bus_in[1] |
| 5 | bus_in[0] |
| 4 | JZ |
| 3 | JGT |
| 2 | JLT |
| 1 | RT |
| 0 | DI |

We still have 2 bits spare that we can toggle when !EO.

Originally RT was in one of the "(unused)" slots conditional on !EO, and DO/DI were decoded
from bus_out/bus_in. The problem is that these signals can cause side effects without
a clock edge required, so they are moved out so that they can't "glitch" during the gate delay
of the decoding logic.

## Extensibility

In addition to the 2 unused bits, and the spare bit when !EO,
bus_out/bus_in have some decodings which are currently unused. In principle, as long as these unused signals are routed
alongside everything else on the backplane, it would be possible to extend the CPU with an extra register (e.g. a
dedicated stack pointer) or other modules, at a later date, by just plugging the new module into the backplane
and writing microcode to make use of it.

## Tricks

### Conditionally skip the next instruction

The obvious way to conditionally skip the next instruction is to generate the address to jump
to, stash it somewhere, perform the operation that will set the condition flags, and then
ask for a conditional jump.

With the restriction that the instruction to skip is only 1 word, we can instead perform
the comparison operation, and then:

    PO JNZ P+

In this case using JNZ for the conditional jump. PO means the current value of the program
counter will be on the bus, which currently points to the next instruction. If the result
of the comparison was not zero, then JNZ makes the PC load its value from the bus, meaning
it doesn't change. Otherwise, P+ means the PC is incremented, which skips it past the next
instruction.

If the next instruction is going to be 2 words, then:

    PO JNZ P+
    PO JNZ P+

will achieve the same goal.

I can't think of a general way to skip the next instruction without knowing its length.

### Microcode RAM

It would be interesting if some of the opcode space were dedicated to a "decode RAM" instead
of a "decode ROM", so that extra microcoded instructions can be created at runtime. I'm not
going to do it for this machine, because although it would be easy to implement, it sounds like
it makes for hard-to-debug programs, which I'll have enough of already.

### Microjump

The microcode doesn't provide a mechanism to jump to a different microinstruction, but we could
do it anyway. Something like:

    XO II

Will put the X register into the instruction register, and will proceed from the next T state from
the instruction indexed by the high byte of the X register.

#### Longer instructions

If we have up to 2 instructions that need more than 6 cycles, then we can make their T7 microcode
say "-1 II" or "0 II". This will then proceed from T0 of instruction 255 or 0, respectively. If we
make sure that T0 of these instructions does *not* fetch the next instruction from memory, then we
get 8 extra cycles for our useful instruction.

One problem is that we would get stuck in the 0 or 255 instruction since the first 2 T-states are not
the standard fetch cycle.

I wonder if it would work to make the 0 instruction do something like:

    [ 6 useful cycles ]
    PO AI
    MO II

It would then load the next instruction. With the next instruction loaded, we'd then run that instruction's
T0 and T1 microcode, which would repeat "PO AI" and "MO II", but now with P+, and carry on as normal, at
the cost of 2 "wasted" cycles.

In total we'd get 5 extra cycles to use for up to 2 long instructions: we lose 1 cycle on the "-1 II"
step, gain 8 for the second opcode, and lose 2 more for getting back out of our instruction.

Long instructions that we might want to implement include:

 * xor x, ... - we could implement "xor x, y" in opcode 0 or 255, and the "ld x, ..." in the first 4 cycles at different opcodes, followed by "0 II" to get to the actual xor step?
 * push r
 * push i16
 * tbsz but skips 2 words instead of just 1
 * shl3 r

Although note that since we need to waste 2 cycles at the end anyway, the only obvious advantage this scheme has
over 2 separate instructions that work together is you get to keep the address register intact across the 2
different opcodes. And none of the obvious candidates look like they would make effective use of that property.

Possibly it is better to just keep instructions small enough to fit into 6 T-states.

But being able to implement "xor x, r" etc. would mean we could finally stop exposing the Y register.

#### Conditional microjump

There isn't an obvious general-case way to do a useful conditional microjump, but in special cases (e.g.
tbsz comes to mind), we could arrange for the X register to contain 0 in the "want the jump" case, and
some other value otherwise, for example:

    7. X&Y II

In the event that "X&Y" is 0, we'll next execute instruction 0 at T0, which could do some useful work. In other
cases we'll jump to some non-0 instruction, which will have the normal "fetch" microcode at T0, and we have effectively
microjumped to address 0, conditional on the result of some expression.

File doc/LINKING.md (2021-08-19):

# Linking

To reduce compile times within **SCAMP/os**, the library files are pre-compiled
into an object file stored at `/lib/lib.o`. There isn't a proper linker, there are
just a series of small bodges that make this work.

It helps if you understand how SLANG programs are "meant" to be compiled:

1. `slangc` turns the SLANG source into assembly code.
2. `include` statements just include the referenced files directly in the program.
3. the generated assembly code is combined with `head.s` at the start (mainly to initialise
   the stack pointer) and `foot.s` at the end (mainly to `exit(0)`), and turned into
   an executable by `asm`.

This is not acceptable because the vast majority of the compilation (and assembly)
time is spent re-compiling the exact same code from the libraries each time. The
solution is to create a blob that contains the generated executable code for the
library functions, and just include this blob instead of re-compiling the libraries
every time.

Turning library code into a static pre-compiled blob was the biggest contributor to
reducing compilation time of "Hello, world" from 27 minutes to 2 minutes at 1 MHz.

## Creating `lib.o`

See `sys/make-lib` for the script that creates `lib.o`. In short:

1. Create a SLANG source file that includes every library you want in the blob, something like:

   ```
    include "malloc.sl";
    include "stdio.sl";
    include "stdlib.sl";
    # ...
   ```

2. Turn this source into assembly code with `slangc`.

3. Using a hacked `head.s` (see `sys/lib/libhead.s` - we need it to skip the code
   that initialises the stack pointer, but still retain definitions of system call
   vectors), turn the assembly code into machine code. This output is `lib.o`.

4. At the same time, get `asm` to generate a `lib.s` assembly source file that defines
   all of the symbols. This is the `--asm-header` option. (It actually only writes
   symbols that begin with an underscore, as these are the only ones accessible from
   SLANG). This looks like:

   ```
    # ...
    .def _printf 0x209f
    .def _putchar 0x2098
    .def _puts 0x209c
    .def _read 0x2080
    .def _readdir 0x2078
    # ...
   ```

    This has `.blob /lib/lib.o` prepended to it by `make-lib` so that when it is assembled,
    the library blob is included.

5. At the same time, get `asm` to generate a `lib.h` SLANG source file that *names*
   the same symbols, so that `slangc` knows they're available. This looks like:

   ```
    # ...
    extern printf;
    extern putchar;
    extern puts;
    extern read;
    extern readdir;
    # ...
   ```

6. Now when we compile a SLANG program, if we include `lib.h` instead of the SLANG source for
   each library, and we make sure `lib.s` is included in the assembly code, then we'll get
   access to all of the library functions without having to recompile them. Great success.

## Tricky bits

To make sure that unmodified programs can use either the pre-compiled library (such as within SCAMP/os),
or directly use the source code of the libraries (such as when cross-compiling), we say that
the convention is that the program should always include the libraries it wants (i.e.
`include "stdio.sl"`, *not* `include "lib.h"`), but the contents of `/lib/stdio.sl`
in SCAMP/os is just `include "lib.h"`.

Some parts of the library (namely `malloc()` and `system()`) need to know the highest address used
by the program (called `TOP`). Previously, this was provided by `foot.s`. The initial value of `TOP` can
not be known at the time the library is compiled, because it depends on how large the eventual
program is. For this reason, `libhead.s` contains a `.def` directive that points at the address of
the `_TOP` symbol, which is now defined in `head.s` so that it has a fixed address.

There is some code in `head.s` that needs to run before the start of the library. It needs to initialise the
stack pointer and the value of `_TOP`. Both of these need to know where the program code ends, which
means they can't be pre-compiled. For this reason, `libhead.s` starts with `.at 0x10a` instead of `.at
0x100`, to leave room for the instructions generated by `head.s`. This is kind of confusing and error-prone,
but it works.

This "pre-compiled blob" strategy works for as many libraries as you want, but you need all libraries to
be compiled into a single blob. I can't think of a way to mix and match multiple blobs, because all of
the addresses are static. To mix-and-match different blobs, we'd need to defer the `resolve_unbounds()`
step of `asm` to the final compilation step, which would basically be what a proper linker would
do. Maybe one day I'll do a proper linker.

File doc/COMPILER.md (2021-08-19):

# Compiler

The language is called SLANG but I haven't quite worked out what it stands for yet, other
than "SCAMP Language".

`compiler/slangc` contains a Perl implementation of a SLANG compiler.
The code it generates is not great, but `peepopt` cleans it up quite a lot.

## Design goals

It should either be self-hosting or implemented in assembly language, so that the compiler can (at least
in principle) be developed completely inside SCAMP.

I'm not really picky about the syntax, but I definitely want pointers, pointer arithmetic, function pointers, and
inline assembly code.

Sources of inspiration include:

 - [Small-C](https://en.wikipedia.org/wiki/Small-C)
 - [Cowgol](http://cowlark.com/cowgol/)
 - [PL/0](https://en.wikipedia.org/wiki/PL/0)
 - [KenCC](http://gsoc.cat-v.org/projects/kencc/) - although this might be too big
 - [Nicolas Laurent's compiler class](https://norswap.com/compilers/)

## Purposes

There are really 3 types of program I want to write with the compiler:

 - the compiler itself (potentially)
 - system utilities (shell, text editor, grep, ls, ...)
 - Advent of Code problems

Advent of Code problems often benefit from bignums and recursion. So recursive function calls are definitely
something I'd want the language to support. Bignum functions should probably go in the standard library, but (eventually)
with optimised assembly language implementations.

## Types

SCAMP only has native support for 16-bit values (both values and addresses are 16-bit). We could
make a language that only has one actual data type, and make pointers be a matter of syntax rather than
a type. That gets us pointer arithmetic for free. We could imagine something like:

    var x = 100;
    var y = &x;
    var z;

    x = 5;
    z = *y + 10; // z == 15, because *y==x

### Strings

A string literal will evaluate to the address of the first character. I'm not sure if we'd want to support "packed strings" as well,
which use memory a bit more efficiently? Probably best to keep it simple and just waste the upper byte.

### Functions

Since we only support one type, we don't *really* need to know function signatures. Passing arguments to a function
just means pushing them onto the stack in the correct order. It might be helpful to have compile-time checking that
the number of arguments is correct (not least because the calling convention involves the caller popping the arguments off,
which will likely cause confusing and hard-to-understand bugs if the wrong number is pushed). Maybe we could have the "non-optimised"
compilation mode always append a known sentinel value to the stack, and have each function check for the presence of the
sentinel (and then overwrite it), as a runtime check that the function has been passed the correct number of arguments.

So *if* we accept calling functions without knowing the signature, then this leads very easily to function pointers: just put
function names in the main symbol table, and when you assign a function name to something you get the address of the function:

    func double(x) {
        return x+x;
    }

    var f = double;
    f(10); // == 20

We could abolish normal function definitions and *only* support anonymous functions:

    var double = func(x) {
        return x+x;
    };

And then passing function pointers around becomes much more intuitive, even though it's actually equivalent. Not sure which is better.
The "anonymous functions" version comes with an extra level of indirection on every single function call, which is potentially not
worth it.

### Arrays

There are really 2 parts to arrays: declaration and usage. In C there is a distinction between a pointer (which stores an address) and an array (which
stores values, but evaluates to the address of the first value). I think we could abolish this distinction, and essentially make all arrays anonymous,
so the only way to use them is with pointers. So declaration might be something like:

    var arr = array[20];

In fact, this almost looks like `malloc()`. We could just not have *any* special syntax for array declaration, and use something like `malloc()`/`alloca()`
to allocate arrays. The downside is we don't get to initialise the contents at compile time. Hmm.

We would support pointer-arithmetic-style usage of arrays for free:

    *(arr + 15) = 6;

But could probably easily add "array-like" syntactic sugar for the same:

    arr[15] = 6;

Update: I added some syntax for defining a statically-allocated array at compile time:

    var arr = [1, 2, 3, 4, 5];

The memory allocation works the same as string literals, but the contents are filled in dynamically at runtime, which
allows things like this to do what you expect:

    var x = foo();
    var y = bar();
    var arr = [1, 2, 3, x, y];

## Operators

I don't know if we want/need to support anything that the CPU doesn't natively support. In particular multiplication
and division come to mind here. Is it better to implement them as special-cased operators that compile to a function call,
or to not provide them at all and make the function call explicit? Or should we just add special syntax for defining
custom operators, and use the standard library to provide defaults for multiplication and division?

## Compiler output

I envisage the compiler outputting assembly language code, which is then assembled by a separate assembler program. I
don't think I'd bother with writing a linker, at least not at first. I maybe don't mind if the standard library is compiled
and assembled separately every time. We might be able to short-circuit compilation of unused functions, which would save
a lot of time. Or at least split the standard library across multiple files and only include the relevant ones in each
program.

## Calling convention

I really like `printf()` and want something like it. That means we need to support a variable number of arguments. For `printf()` to
know how many arguments to pop, it needs to be able to grab the format string before it grabs any of the other arguments, which
probably means we need the *first* argument to the function to be the *last* value pushed to the stack. Otherwise, for `printf()` to
get the format string first, we'd need to use it like:

    printf(1, "hello", "%d. %s\n"); // "1. hello\n"

which is annoying and unintuitive.

Update: the solution I went with was to use the statically-allocated array syntax to pass an array of arguments to `printf()`:

    printf("Hello, %s. Number is %d.\n", ["world", 42]);

## Grammar

The implemented grammar is something like:

    program           ::= statements
    statements        ::= '' | (statement (';' statement)* ';'?)
    statement         ::= block | extern | declaration | conditional | loop | 'break' | 'continue' | return | assignment | expression
    block             ::= '{' statements '}'
    extern            ::= 'extern' identifier
    declaration       ::= ('var' identifier) | ('var' identifier '=' expression)
    conditional       ::= 'if' '(' expression ')' statement ('else' statement)?
    loop              ::= 'while' expression statement
    return            ::= 'return' expression
    assignment        ::= lvalue '=' expression
    lvalue            ::= identifier | ('*' term)
    expression        ::= expr0
    expr0             ::= expr2 ([&|^] expr2)*
    expr1             ::= term (('&&'|'||') term)*
    expr2             ::= expr3 (('=='|'!='|'>='|'<='|'>'|'<') expr3)*
    expr3             ::= expr1 ([+-] expr1)*
    term              ::= constant | func_call | address_of | preop | postop | unary_expr | paren_expr | identifier
    constant          ::= num_literal | str_literal | func_decl
    num_literal       ::= hex_literal | char_literal | dec_literal
    hex_literal       ::= '0x' [0-9a-fA-F]+
    dec_literal       ::= [-+]? [0-9]+
    char_literal      ::= ("'" '\' <char> "'") | ("'" <char> "'")
    str_literal       ::= '"' <string> '"'
    func_decl         ::= 'func' '(' paramaters ')' statement
    parameters        ::= '' | (identifier (',' identifier)* ','?)
    func_call         ::= identifier '(' arguments ')'
    arguments         ::= '' | (expression (',' expression)* ','?)
    address_of        ::= '&' identifier
    preop             ::= ('++' identifier) | ('--' identifier)
    postop            ::= (identifier '++') | (identifier '--')
    unary_expr        ::= [!~*+-] term
    paren_expr        ::= '(' expression ')'
    identifier        ::= [a-zA-Z_] [a-zA-Z0-9_]*

But with the understanding that there can be optional whitespace between any pair of tokens, and comments that start with a '#'
and run to the end of the line.

Intended to allow programs like:

    # Example program
    var x = 0;
    var y = 5;
    var z;
    var welcome = "Hello, world!\n";
    
    printf("%s", welcome);
    
    var i = 0;
    while (i < 5) {
        i = inc(i); # Increment i
        printf("Loop number %d\n", i);
    };
    
    var inc = func(x) {
        return x + 1;
    };

## Optimisation

### Peephole

There is a peephole optimiser in `compiler/peepopt`. It works by reading in assembly code and passing it through
several "levels" of optimisation, which each pass through code unchanged if they don't recognise it, and optimise
the bits they are responsible for if they do.

Here are some benchmarks for `test.sl`, the compiler test program, showing how the code size
and runtime are improved by `peepopt`.

| Optimisation | Time (cycles) | Size (words) |
| :--- | :--- | :--- |
| None | 49,687,474 | 7,495 |
| 1 pass peepopt | 33,806,242 (-32%) | 5,555 (-26%) |
| 2 pass peepopt | 31,414,357 (-37%) | 5,503 (-27%) |

After the first pass of `peepopt` there are some new `push x; pop x;` instances that can be
optimised out, hence the second pass is slightly better.

Applying more than 2 passes doesn't yield any further improvement on this particular
program, but I haven't proven that it can't do on other programs.

### Function locations

Instead of generating functions inline and jumping over them, we should stick them at the end with the other globals.

### Function calls

Is there a more efficient way to go about the whole business of backing up r254 (return address) before function calls?

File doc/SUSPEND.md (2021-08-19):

# Suspend to disk

We could suspend a running session by dumping the contents of memory to a file on disk and then
restoring it at next boot. We could add a special key shortcut for this (along the lines of Ctrl-C
to exit a program and Ctrl-L to clear the screen), but since we already have Ctrl-Z to spawn a subshell,
it might be better to have a `suspend` command.

Rather than automatically restoring the previous session at the next boot, we could have the boot process
completely unaware of suspended sessions, and a `resume` command to resume the suspended one. The only
change required here is that we need to move the contents of `/proc/` to `/proc/suspend/` or something
so that they aren't trampled by the new session's processes.

And by the time we have accepted that we need to copy the contents of `/proc/` somewhere else for
safe-keeping, there's no reason to limit ourselves to only 1 suspended session: we could make `suspend`
and `resume` take an argument specifying the session name (kind of like GNU screen session names), and then
we could have multiple separate sessions available.

If we have multiple sessions available, then there's no reason we can't switch between them, automatically
saving the current session and resuming the new one. This could even be the standard mode of operating
the computer.

Of course, a session doesn't currently store a huge amount of useful state. In fact the only thing I
can think of that you might want to resume is your place in a file in the `kilo` editor, or
a half-completed game of `hamurabi`. Perhaps if there's a long-running process it might be useful to
suspend it and then go about doing something else before resuming it, but the Ctrl-Z workflow can handle
most of what you'd want from that, as long as you're pretty sure you won't crash the system and have to
reset it. If the state of the long-running process is very important it might be worth saving before
you go off doing something risky.

Perhaps rather than `suspend` and `resume`, the nomenclature could be `save` and `load`? The difference
being that after a `suspend` you are done for the day, but after `save` you have just saved a checkpoint
and intend to carry on.

Perhaps `save("name")` could just be a system call and our hypothetically important long-running process
could call it of its own accord at sensible intervals so that it can be resumed even if the power goes off
or similar.

## Implementation

I think upon a `save()` we'd want to flush all write buffers and then dump the entire memory contents to
disk, along with the return address of the `save()` call and the stack pointer (roughly like we currently
do with `system()` - in fact perhaps that part could be factored out and used for both). Upon `load()`
we'd restore all of the memory contents - including the kernel. This might prove complicated because it
would overwrite the stack and pseudoregisters of the `load()` function that is trying to do the
restoring, so perhaps we'd cordon off a section of memory for `load()`'s stack, and not restore
anything over the top of it, and also not restore all (any?) of the pseudoregisters - we currently risk
trashing pseudoregisters on every system call anyway, so I don't think that should be a problem.

I think that should do the job. If that is enough to implement `save()` and `load()` then the rest of it
is just userspace programs to provide a sensible interface.

Probably `save` and `load` are bad names because they collide with too many other things. Maybe
`savesession` and `loadsession` or something?

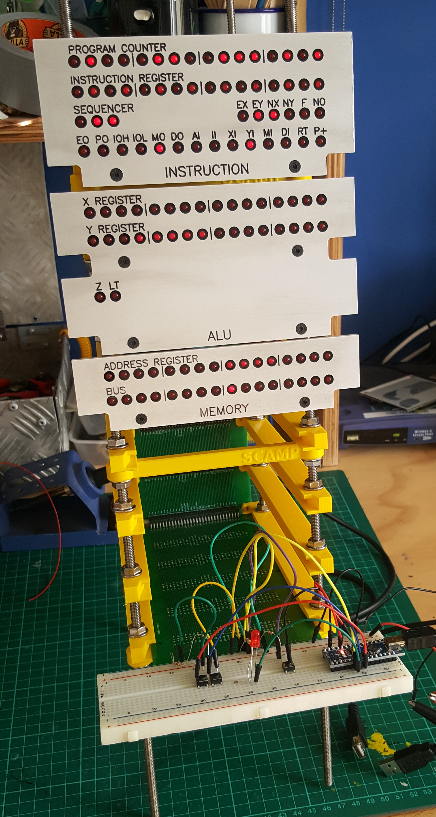
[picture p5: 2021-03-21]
doc/front-panels.jpeg

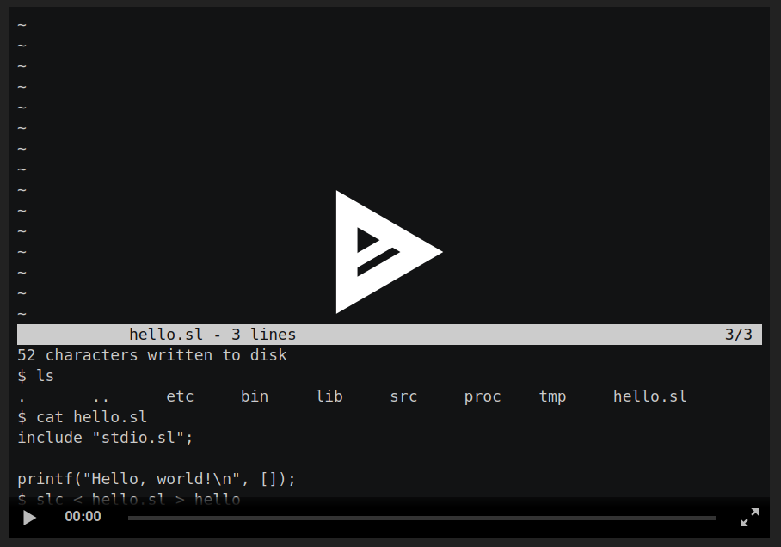
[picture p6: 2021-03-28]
doc/asciinema.png

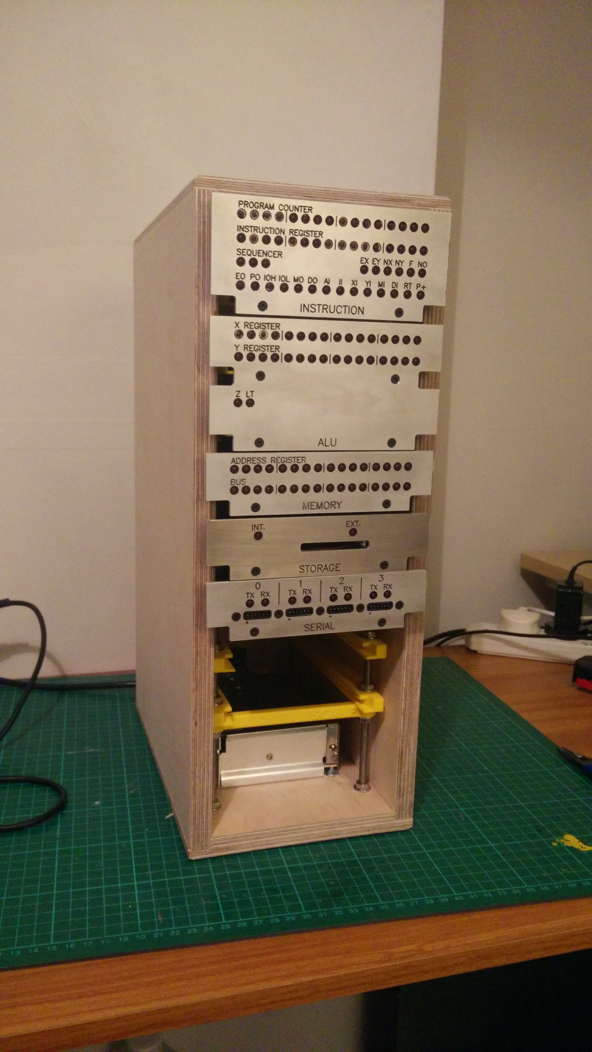
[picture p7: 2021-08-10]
doc/case.jpeg

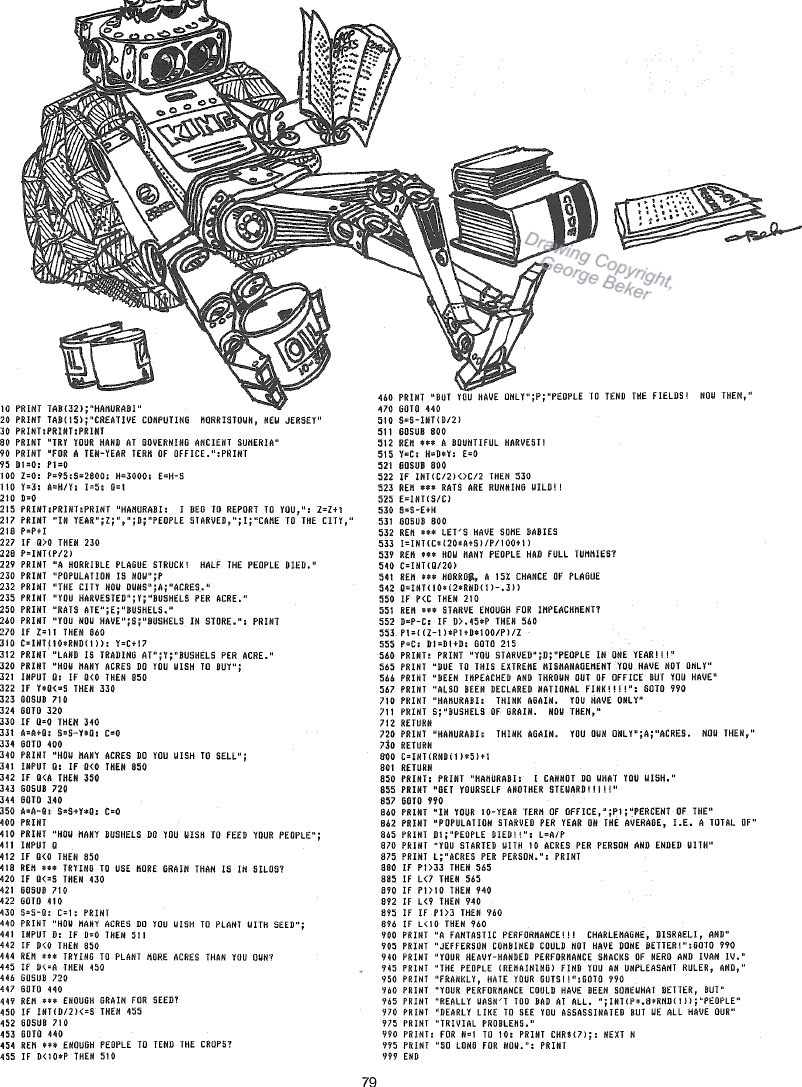
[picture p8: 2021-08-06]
doc/hamurabi.png

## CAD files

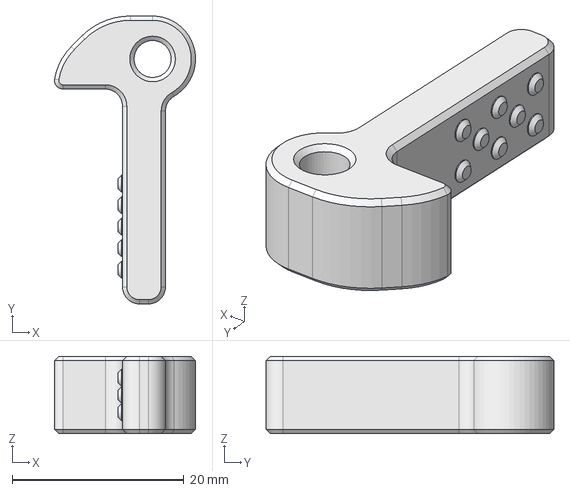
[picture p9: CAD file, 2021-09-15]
case/card-lever.FCStd
16.4 x 33.5 x 9.00 mm

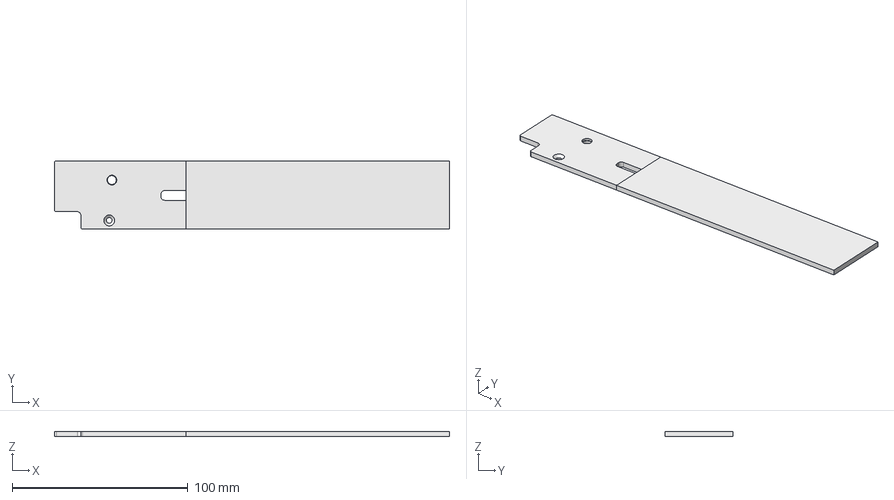
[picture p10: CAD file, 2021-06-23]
front-panels/storage-panel.FCStd
225.0 x 39.0 x 3.00 mm
Model-Body
Stock

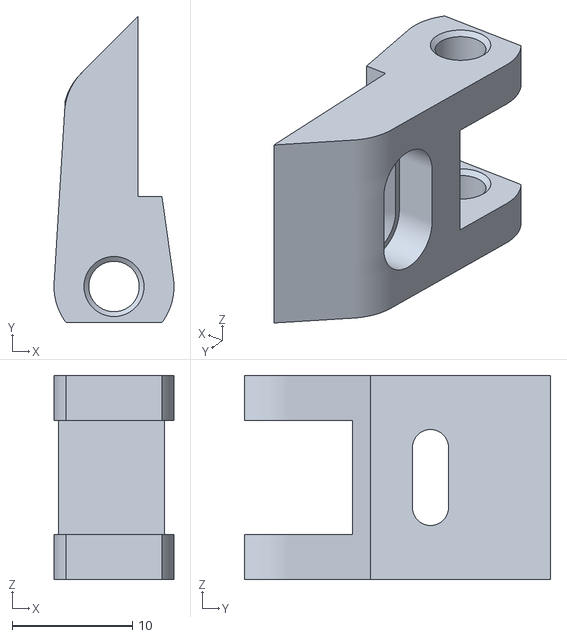
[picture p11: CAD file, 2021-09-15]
case/rod-holder.stl
10.00 x 25.5 x 17.0

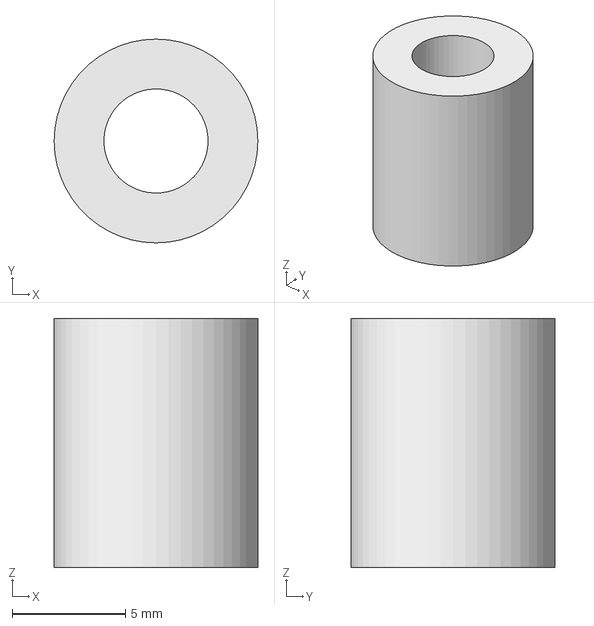
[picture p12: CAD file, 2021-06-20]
front-panels/cf-spacer.FCStd
9.00 x 9.00 x 11.0 mm

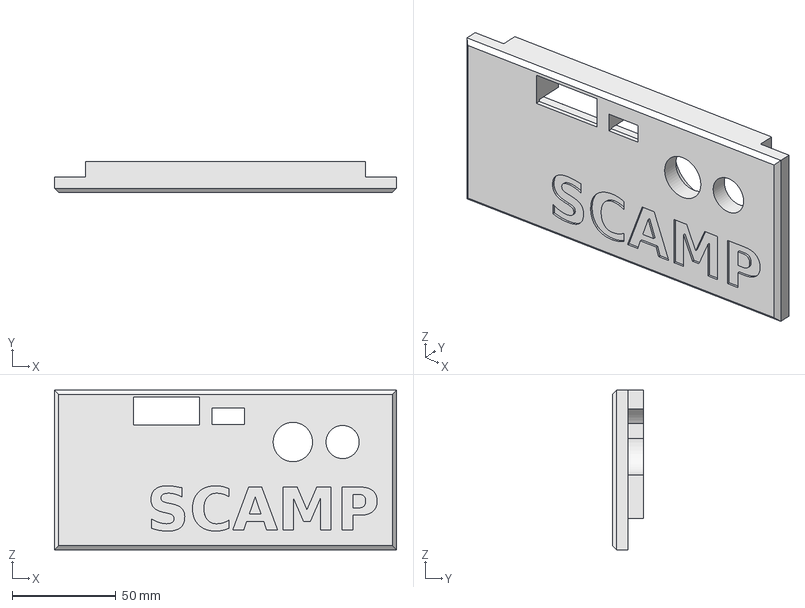
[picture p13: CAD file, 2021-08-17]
case/case.FCStd
165.0 x 15.0 x 77.0 mm

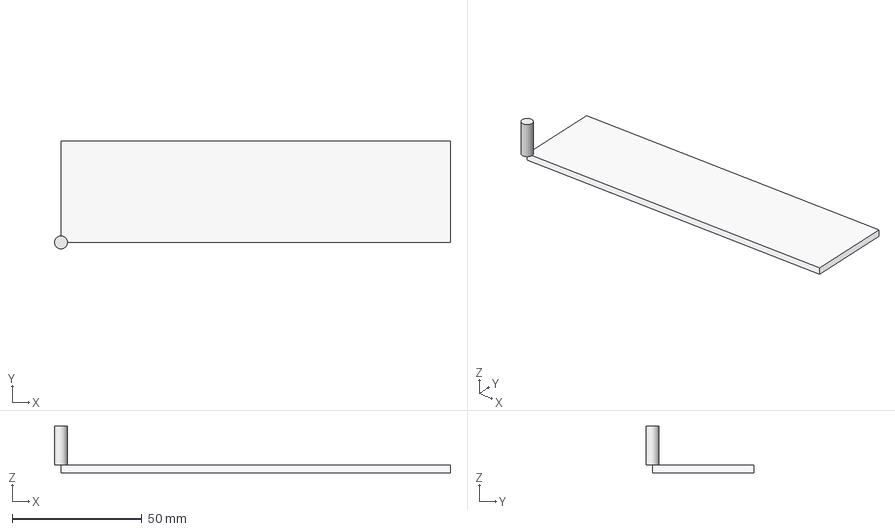
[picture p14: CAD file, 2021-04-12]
front-panels/serial-panel.FCStd
152.5 x 41.5 x 18.0 mm
Model-Body
tool
Stock

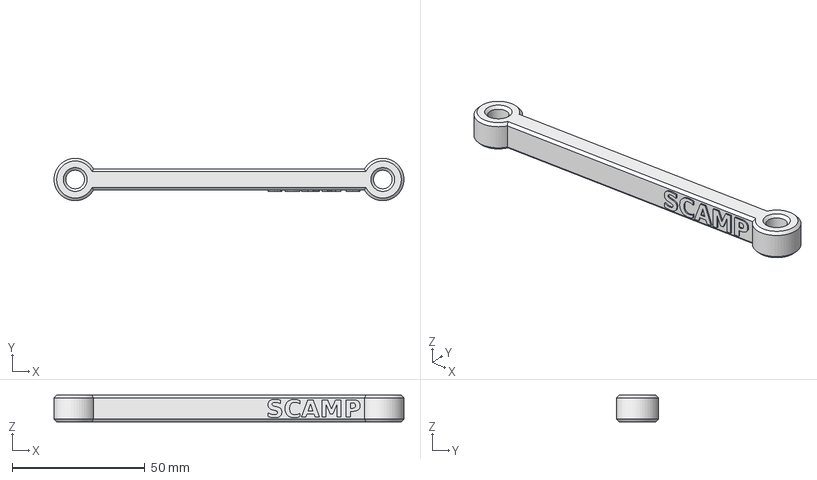
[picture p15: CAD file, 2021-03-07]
case/horizontal-brace.FCStd
132.0 x 16.0 x 10.0 mm

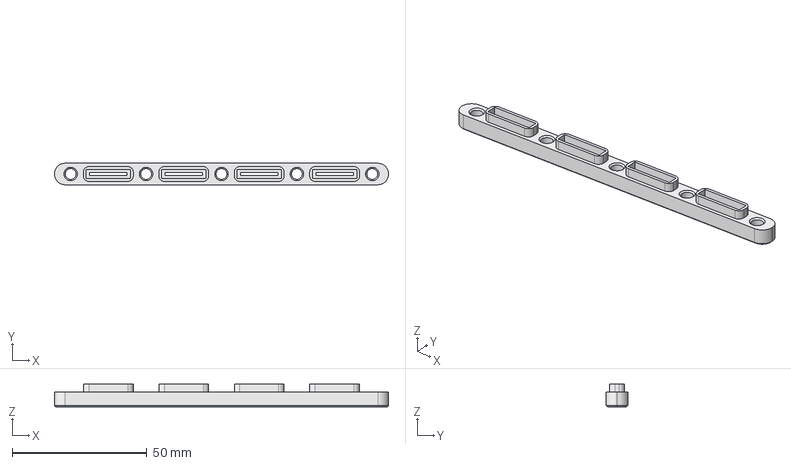
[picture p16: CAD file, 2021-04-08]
front-panels/serial-connector.FCStd
124.0 x 8.00 x 8.50 mm

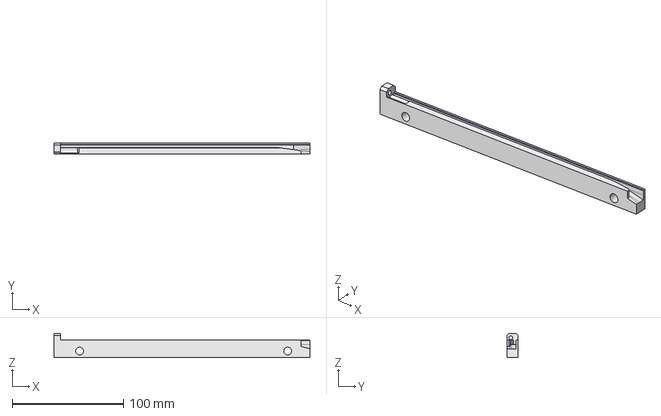
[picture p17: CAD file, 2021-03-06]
case/card-rail.FCStd
230.0 x 10.0 x 22.0 mm

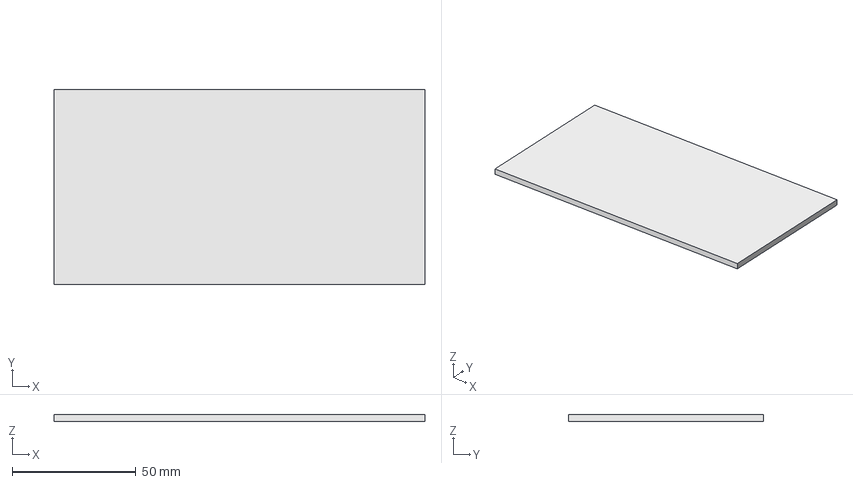
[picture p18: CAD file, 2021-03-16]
front-panels/alu-panel.FCStd
150.0 x 79.0 x 3.00 mm
Model-Body
Stock

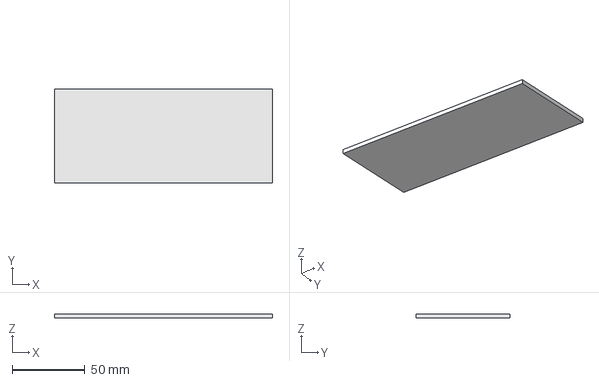
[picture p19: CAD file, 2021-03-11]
front-panels/instruction-panel.FCStd
150.0 x 65.0 x 3.00 mm
Model-Body
Stock

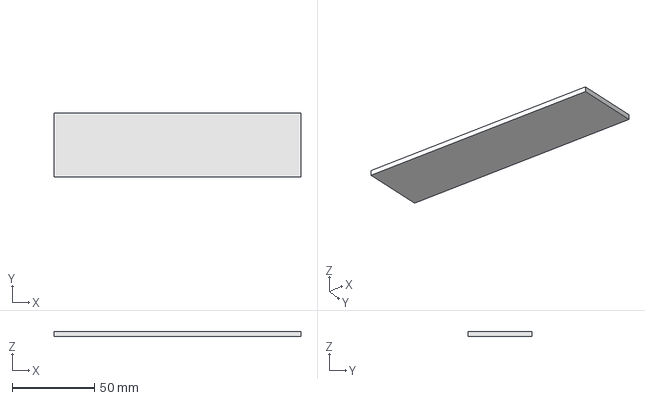
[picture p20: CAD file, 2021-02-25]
front-panels/memory-panel.FCStd
150.0 x 39.0 x 3.00 mm
Model-Body
Stock

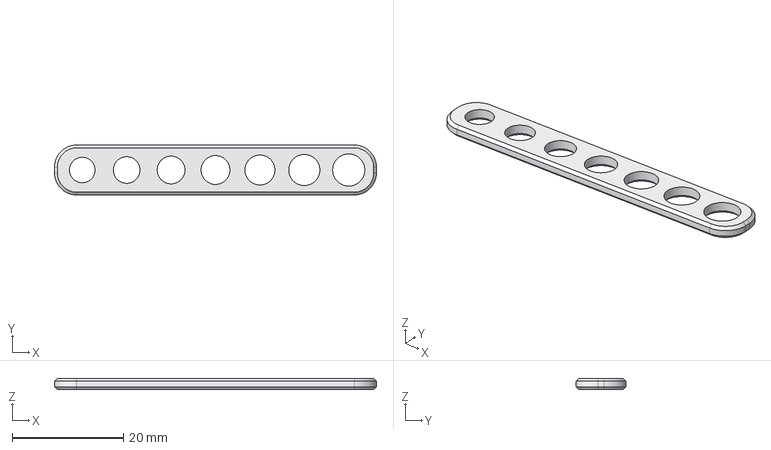
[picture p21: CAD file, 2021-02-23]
front-panels/test-holes.FCStd
58.0 x 9.00 x 2.00 mm

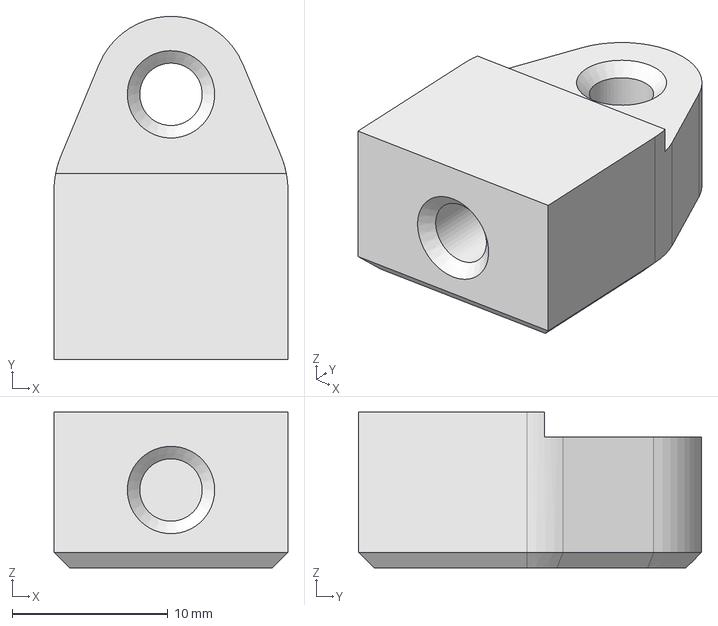
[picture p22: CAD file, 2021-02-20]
front-panels/bracket.FCStd
15.0 x 22.0 x 10.0 mm

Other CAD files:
case/card-lever.stl
case/card-rail.stl
case/horizontal-brace.stl
front-panels/bracket.stl
front-panels/cf-spacer.stl
front-panels/memory-panel.stl
front-panels/serial-connector.stl
front-panels/storage-panel.stl
front-panels/test-holes.stl

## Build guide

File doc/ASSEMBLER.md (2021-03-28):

# Assembler

(This is about the assembler written in SLANG, not the one written in Perl).

The assembler writes code into a file, and writes unresolved symbol addresses to
a different file. Once the first pass is finished, the generated code is re-processed,
with unresolved symbols now resolved on the second pass.

The parser uses the recursive descent parsing framework. The code to turn
instructions into code is generated from `instructions.json` on a "modern"
computer using `mk-asm-parser`.

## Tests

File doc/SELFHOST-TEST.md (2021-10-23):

# Self-hosting test

With the compiler-specific test no longer working properly, I think a good
end-to-end self-hosting test is in order.

It should load up the OS in the kernel, and run something like:

    cd /src
    ./build.sh
    cd /src/kernel
    ./build.sh
    kwr kernel.bin c400
    reboot
    echo "Great success"

The test harness should make some effort to ensure:

 * a new line of the input is given every time the shell prompts for one
 * the VM actually reboots when instructed
 * the new kernel is running instead of the old one (maybe check the `kernel-name.sl`
   output?)
 * any text output containing "error:" counts as an output
 * (bonus) we should have `install.sh` under `/src` to install the system utilities,
   and check that they still work when self-hosted
 * (bonus) rebuild the system again, using the toolchain that was built from under
   SCAMP/os

Probably just want a Perl script to fire up the emulator and manage input/output.
Input maybe needs to be "drip-fed" because of the slowness of the serial port?

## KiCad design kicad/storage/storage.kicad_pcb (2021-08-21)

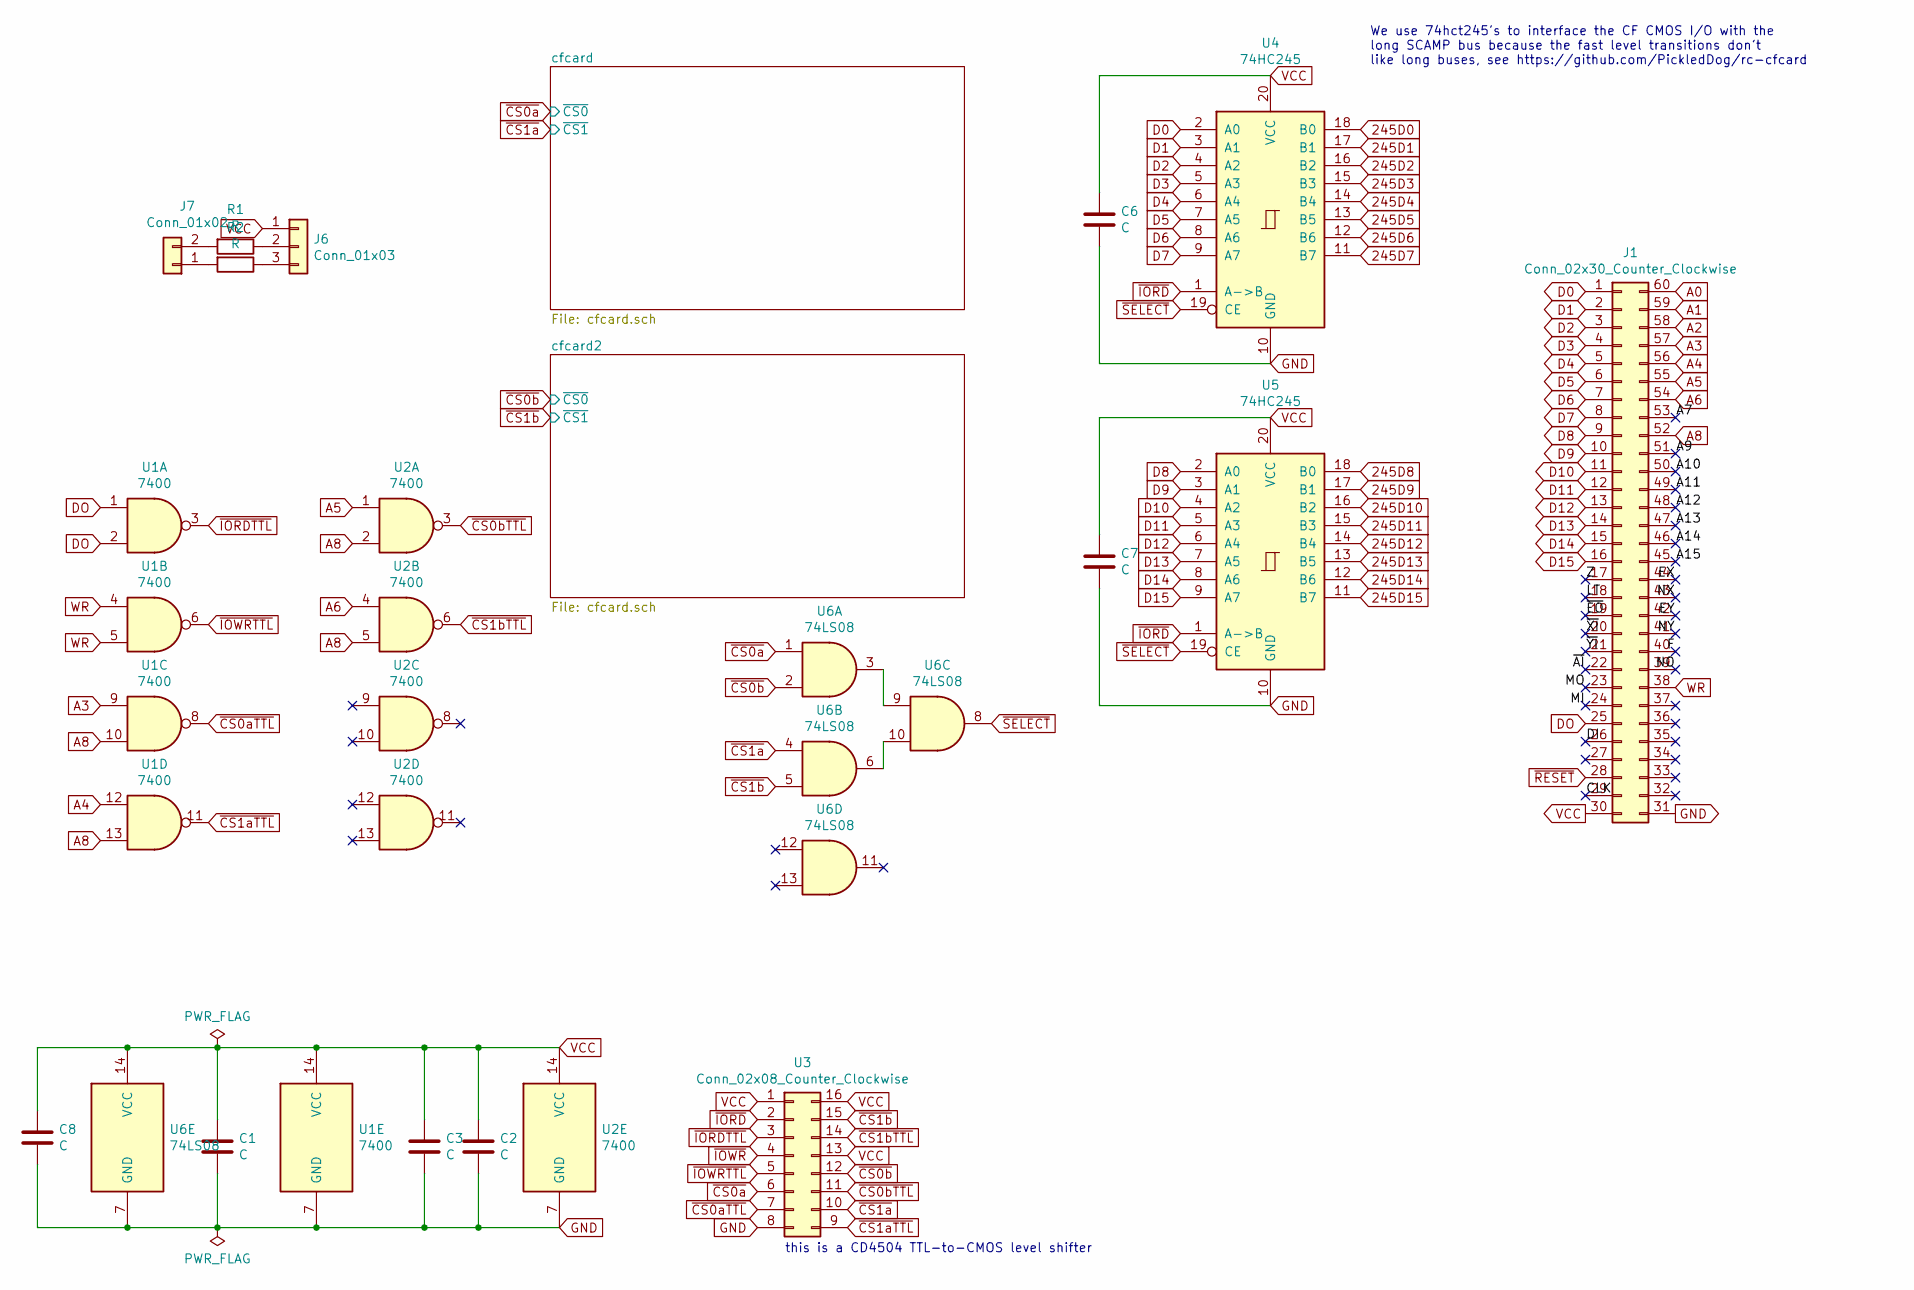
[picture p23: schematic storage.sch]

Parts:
C1, C2, C3, C6, C7, C8: C; C_Disc_D6.0mm_W2.5mm_P5.00mm
J1: Conn_02x30_Counter_Clockwise; PinSocket_2x30_P2.54mm_Horizontal
J6: Conn_01x03; PinHeader_1x03_P2.54mm_Vertical
J7: Conn_01x02; PinHeader_1x02_P2.54mm_Vertical
R1, R2: R; R_Axial_DIN0207_L6.3mm_D2.5mm_P10.16mm_Horizontal
U1, U2: 7400; DIP-14_W7.62mm_Socket
U3: Conn_02x08_Counter_Clockwise; DIP-16_W7.62mm_Socket
U4, U5: 74HC245; DIP-20_W7.62mm_Socket
U6: 74LS08; DIP-14_W7.62mm_Socket

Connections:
245D0: U4.18 (B0); also elsewhere on the board
245D1: U4.17 (B1); also elsewhere on the board
245D2: U4.16 (B2); also elsewhere on the board
245D3: U4.15 (B3); also elsewhere on the board
245D4: U4.14 (B4); also elsewhere on the board
245D5: U4.13 (B5); also elsewhere on the board
245D6: U4.12 (B6); also elsewhere on the board
245D7: U4.11 (B7); also elsewhere on the board
245D8: U5.18 (B0); also elsewhere on the board
245D9: U5.17 (B1); also elsewhere on the board
245D10: U5.16 (B2); also elsewhere on the board
245D11: U5.15 (B3); also elsewhere on the board
245D12: U5.14 (B4); also elsewhere on the board
245D13: U5.13 (B5); also elsewhere on the board
245D14: U5.12 (B6); also elsewhere on the board
245D15: U5.11 (B7); also elsewhere on the board
/A7: J1.53
/A9: J1.51
/A10: J1.50
/A11: J1.49
/A12: J1.48
/A13: J1.47
/A14: J1.46
/A15: J1.45
/CLK: J1.29
/DI: J1.26
/EX: J1.44
/EY: J1.42
/F: J1.40
/LT: J1.18
/MI: J1.24
/MO: J1.23
/NO: J1.39
/NX: J1.43
/NY: J1.41
/Z: J1.17
/~AI~: J1.22
/~EO~: J1.19
/~XI~: J1.20
/~YI~: J1.21
A0: J1.60; also elsewhere on the board
A1: J1.59; also elsewhere on the board
A2: J1.58; also elsewhere on the board
A3: J1.57, U1.9
A4: J1.56, U1.12
A5: J1.55, U2.1
A6: J1.54, U2.4
A8: J1.52, U1.10, U1.13, U2.2, U2.5
D0: J1.1, U4.2 (A0)
D1: J1.2, U4.3 (A1)
D2: J1.3, U4.4 (A2)
D3: J1.4, U4.5 (A3)
D4: J1.5, U4.6 (A4)
D5: J1.6, U4.7 (A5)
D6: J1.7, U4.8 (A6)
D7: J1.8, U4.9 (A7)
D8: J1.9, U5.2 (A0)
D9: J1.10, U5.3 (A1)
D10: J1.11, U5.4 (A2)
D11: J1.12, U5.5 (A3)
D12: J1.13, U5.6 (A4)
D13: J1.14, U5.7 (A5)
D14: J1.15, U5.8 (A6)
D15: J1.16, U5.9 (A7)
DO: J1.25, U1.1, U1.2
GND: C1.2, C2.2, C3.2, C6.2, C7.2, C8.2, J1.31, U1.7 (GND), U2.7 (GND), U3.8, U4.10 (GND), U5.10 (GND), U6.7 (GND); also elsewhere on the board
unnamed: J6.2, R1.1
unnamed: J6.3, R2.1
unnamed: J7.1, R2.2
unnamed: J7.2, R1.2
unnamed: U6.3, U6.9
unnamed: U6.6, U6.10
VCC: C1.1, C2.1, C3.1, C6.1, C7.1, C8.1, J1.30, J6.1, U1.14 (VCC), U2.14 (VCC), U3.1, U3.13, U3.16, U4.20 (VCC), U5.20 (VCC), U6.14 (VCC); also elsewhere on the board
WR: J1.38, U1.4, U1.5
~CS0aTTL~: U1.8, U3.7
~CS0a~: U3.6, U6.1; also elsewhere on the board
~CS0bTTL~: U2.3, U3.11
~CS0b~: U3.12, U6.2; also elsewhere on the board
~CS1aTTL~: U1.11, U3.9
~CS1a~: U3.10, U6.4; also elsewhere on the board
~CS1bTTL~: U2.6, U3.14
~CS1b~: U3.15, U6.5; also elsewhere on the board
~IORDTTL~: U1.3, U3.3
~IORD~: U3.2, U4.1 (A->B), U5.1 (A->B); also elsewhere on the board
~IOWRTTL~: U1.6, U3.5
~IOWR~: U3.4; also elsewhere on the board
~RESET~: J1.28; also elsewhere on the board
~SELECT~: U4.19 (CE), U5.19 (CE), U6.8

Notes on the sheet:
this is a CD4504 TTL-to-CMOS level shifter
We use 74hct245's to interface the CF CMOS I/O with the long SCAMP bus because the fast level transitions don't like long buses, see https://github.com/PickledDog/rc-cfcard

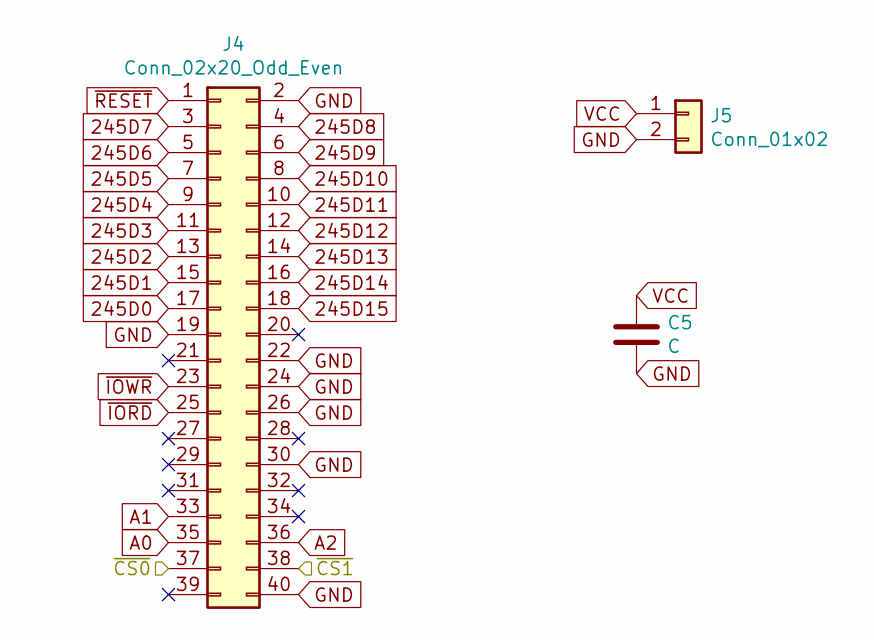
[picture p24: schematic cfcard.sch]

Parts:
C4: C; C_Disc_D6.0mm_W2.5mm_P5.00mm
J2: Conn_02x20_Odd_Even; cfcard
J3: Conn_01x02; PinHeader_1x02_P2.54mm_Vertical

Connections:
245D0: J2.17; also elsewhere on the board
245D1: J2.15; also elsewhere on the board
245D2: J2.13; also elsewhere on the board
245D3: J2.11; also elsewhere on the board
245D4: J2.9; also elsewhere on the board
245D5: J2.7; also elsewhere on the board
245D6: J2.5; also elsewhere on the board
245D7: J2.3; also elsewhere on the board
245D8: J2.4; also elsewhere on the board
245D9: J2.6; also elsewhere on the board
245D10: J2.8; also elsewhere on the board
245D11: J2.10; also elsewhere on the board
245D12: J2.12; also elsewhere on the board
245D13: J2.14; also elsewhere on the board
245D14: J2.16; also elsewhere on the board
245D15: J2.18; also elsewhere on the board
A0: J2.35; also elsewhere on the board
A1: J2.33; also elsewhere on the board
A2: J2.36; also elsewhere on the board
GND: C4.2, J2.2, J2.19, J2.22, J2.24, J2.26, J2.30, J2.40, J3.2; also elsewhere on the board
VCC: C4.1, J3.1; also elsewhere on the board
~CS0a~: J2.37; also elsewhere on the board
~CS1a~: J2.38; also elsewhere on the board
~IORD~: J2.25; also elsewhere on the board
~IOWR~: J2.23; also elsewhere on the board
~RESET~: J2.1; also elsewhere on the board

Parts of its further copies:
C5: C; C_Disc_D6.0mm_W2.5mm_P5.00mm
J4: Conn_02x20_Odd_Even; cfcard
J5: Conn_01x02; PinHeader_1x02_P2.54mm_Vertical

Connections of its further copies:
245D0: J4.17; also elsewhere on the board
245D1: J4.15; also elsewhere on the board
245D2: J4.13; also elsewhere on the board
245D3: J4.11; also elsewhere on the board
245D4: J4.9; also elsewhere on the board
245D5: J4.7; also elsewhere on the board
245D6: J4.5; also elsewhere on the board
245D7: J4.3; also elsewhere on the board
245D8: J4.4; also elsewhere on the board
245D9: J4.6; also elsewhere on the board
245D10: J4.8; also elsewhere on the board
245D11: J4.10; also elsewhere on the board
245D12: J4.12; also elsewhere on the board
245D13: J4.14; also elsewhere on the board
245D14: J4.16; also elsewhere on the board
245D15: J4.18; also elsewhere on the board
A0: J4.35; also elsewhere on the board
A1: J4.33; also elsewhere on the board
A2: J4.36; also elsewhere on the board
GND: C5.2, J4.2, J4.19, J4.22, J4.24, J4.26, J4.30, J4.40, J5.2; also elsewhere on the board
VCC: C5.1, J5.1; also elsewhere on the board
~CS0b~: J4.37; also elsewhere on the board
~CS1b~: J4.38; also elsewhere on the board
~IORD~: J4.25; also elsewhere on the board
~IOWR~: J4.23; also elsewhere on the board
~RESET~: J4.1; also elsewhere on the board

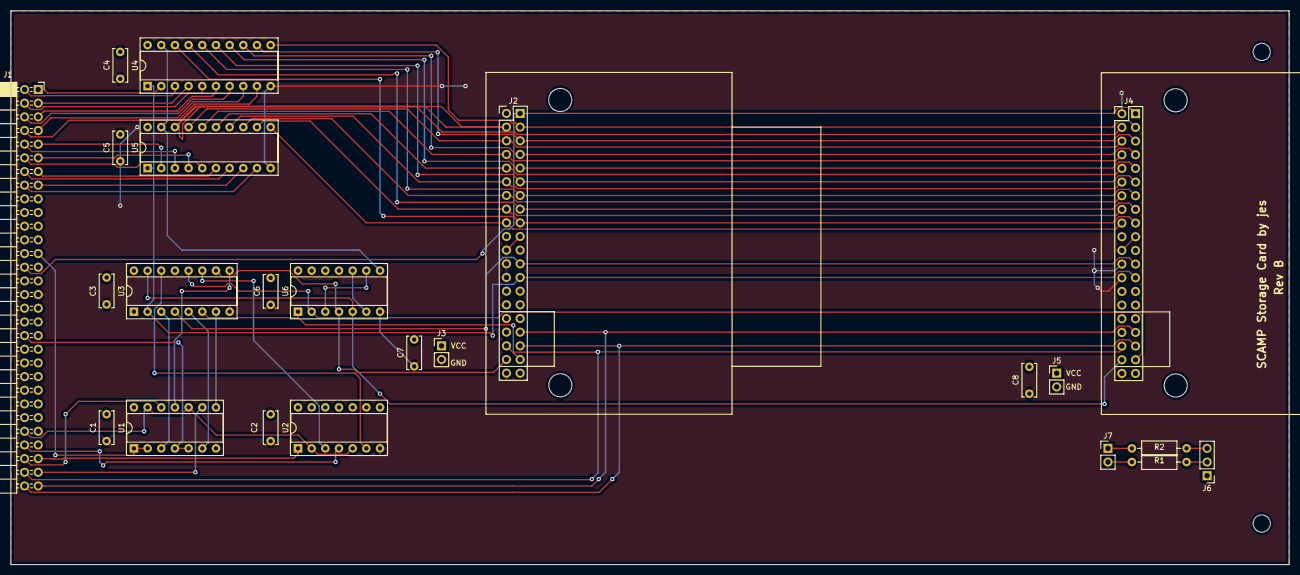
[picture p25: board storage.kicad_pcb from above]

Board: 2 copper layers, 237.5 x 102.9 mm, 23 parts (0 on the bottom side), 64 nets.

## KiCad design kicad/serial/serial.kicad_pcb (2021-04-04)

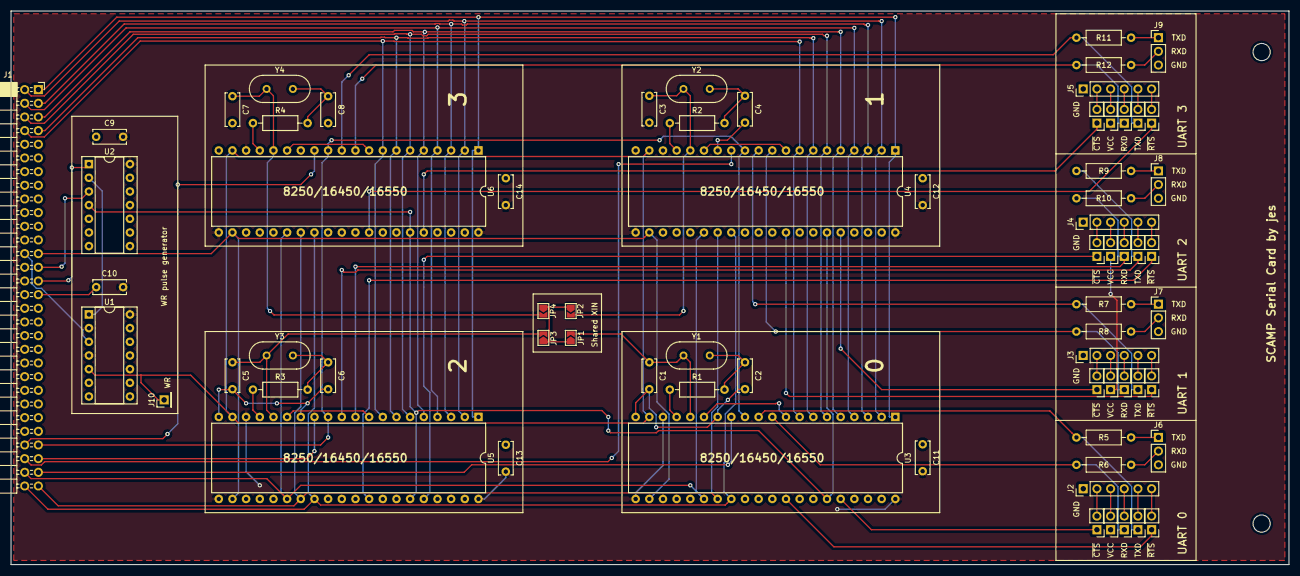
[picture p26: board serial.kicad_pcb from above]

Board: 2 copper layers, 237.5 x 102.9 mm, 62 parts (0 on the bottom side), 70 nets.

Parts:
C1, C2, C3, C4, C5, C6, C7, C8, C9, C10, C11, C12, C13, C14: C; C_Disc_D6.0mm_W2.5mm_P5.00mm
J1: Conn_02x30_Counter_Clockwise; PinSocket_2x30_P2.54mm_Horizontal
J2, J3, J4, J5: Conn_01x06_Male; PinHeader_1x06_P2.54mm_Vertical
J6, J7, J8, J9: Conn_01x03_Male; PinHeader_1x03_P2.54mm_Vertical
J10: Conn_01x01_Male; PinHeader_1x01_P2.54mm_Vertical
JP1, JP2, JP3, JP4: SolderJumper_2_Open; SolderJumper-2_P1.3mm_Open_TrianglePad1.0x1.5mm
R1, R2, R3, R4, R5, R6, R7, R8, R9, R10, R11, R12: R; R_Axial_DIN0207_L6.3mm_D2.5mm_P10.16mm_Horizontal
RXD: Jumper_NO_Small; PinHeader_1x02_P2.54mm_Vertical
RXD#2, RXD#3, RXD#4: Jumper_NO_Small; PinHeader_1x02_P2.54mm_Vertical
TXD: Jumper_NO_Small; PinHeader_1x02_P2.54mm_Vertical
TXD#2, TXD#3, TXD#4: Jumper_NO_Small; PinHeader_1x02_P2.54mm_Vertical
U1: 74LS74; DIP-14_W7.62mm_Socket
U2: 74LS04; DIP-14_W7.62mm_Socket
U3, U4, U5, U6: 8250; DIP-40_W15.24mm
VCC: Jumper_NO_Small; PinHeader_1x02_P2.54mm_Vertical
VCC#2, VCC#3, VCC#4: Jumper_NO_Small; PinHeader_1x02_P2.54mm_Vertical
Y1, Y2, Y3, Y4: Crystal; Crystal_HC49-U_Vertical

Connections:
/uart8250a/RXD: R6.2, RXD.1, U3.10
/uart8250a/TXD: R5.2, TXD.1, U3.11
/uart8250b/RXD: R8.2, RXD#2.1, U4.10
/uart8250b/TXD: R7.2, TXD#2.1, U4.11
/uart8250c/RXD: R10.2, RXD#3.1, U5.10
/uart8250c/TXD: R9.2, TXD#3.1, U5.11
/uart8250d/RXD: R12.2, RXD#4.1, U6.10
/uart8250d/TXD: R11.2, TXD#4.1, U6.11
A0: J1.60, U3.28, U4.28, U5.28, U6.28
A1: J1.59, U3.27, U4.27, U5.27, U6.27
A2: J1.58, U3.26, U4.26, U5.26, U6.26
A3: J1.57, U3.13
A4: J1.56, U4.13
A5: J1.55, U5.13
A6: J1.54, U6.13
A7: J1.53, U3.12, U4.12, U5.12, U6.12
CLK: J1.29, U2.1
D0: J1.1, U3.1, U4.1, U5.1, U6.1
D1: J1.2, U3.2, U4.2, U5.2, U6.2
D2: J1.3, U3.3, U4.3, U5.3, U6.3
D3: J1.4, U3.4, U4.4, U5.4, U6.4
D4: J1.5, U3.5, U4.5, U5.5, U6.5
D5: J1.6, U3.6, U4.6, U5.6, U6.6
D6: J1.7, U3.7, U4.7, U5.7, U6.7
D7: J1.8, U3.8, U4.8, U5.8, U6.8
DI: J1.26, U1.3
DO: J1.25, U3.22, U4.22, U5.22, U6.22
GND: C1.2, C2.2, C3.2, C4.2, C5.2, C6.2, C7.2, C8.2, C9.2, C10.2, C11.2, C12.2, C13.2, C14.2, J1.31, J2.1, J3.1, J4.1, J5.1, J6.3, J7.3, J8.3, J9.3, U1.7, U2.7, U3.14, U3.20, U3.25, U4.14, U4.20, U4.25, U5.14, U5.20, U5.25, U6.14, U6.20, U6.25
unnamed: C1.1, JP1.2, U3.16, Y1.1
unnamed: C2.1, R1.2, Y1.2
unnamed: C3.1, JP2.2, U4.16, Y2.1
unnamed: C4.1, R2.2, Y2.2
unnamed: C5.1, JP3.2, U5.16, Y3.1
unnamed: C6.1, R3.2, Y3.2
unnamed: C7.1, JP4.2, U6.16, Y4.1
unnamed: C8.1, R4.2, Y4.2
unnamed: J2.3, VCC.2
unnamed: J2.4, RXD.2
unnamed: J2.5, TXD.2
unnamed: J3.3, VCC#2.2
unnamed: J3.4, RXD#2.2
unnamed: J3.5, TXD#2.2
unnamed: J4.3, VCC#3.2
unnamed: J4.4, RXD#3.2
unnamed: J4.5, TXD#3.2
unnamed: J5.3, VCC#4.2
unnamed: J5.4, RXD#4.2
unnamed: J5.5, TXD#4.2
unnamed: J6.1, R5.1
unnamed: J6.2, R6.1
unnamed: J7.1, R7.1
unnamed: J7.2, R8.1
unnamed: J8.1, R9.1
unnamed: J8.2, R10.1
unnamed: J9.1, R11.1
unnamed: J9.2, R12.1
unnamed: R1.1, U3.17
unnamed: R2.1, U4.17
unnamed: R3.1, U5.17
unnamed: R4.1, U6.17
unnamed: U3.9, U3.15
unnamed: U4.9, U4.15
unnamed: U5.9, U5.15
unnamed: U6.9, U6.15
SHAREDXIN: JP1.1, JP2.1, JP3.1, JP4.1
VCC: C9.1, C10.1, C11.1, C12.1, C13.1, C14.1, J1.30, U1.2, U1.4, U1.14, U2.14, U3.18, U3.21, U3.40, U4.18, U4.21, U4.40, U5.18, U5.21, U5.40, U6.18, U6.21, U6.40, VCC.1, VCC#2.1, VCC#3.1, VCC#4.1
WR: J10.1, U1.5, U3.19, U4.19, U5.19, U6.19
inv_CLK: U1.1, U2.2
inv_~RESET: U2.4, U3.35, U4.35, U5.35, U6.35
~RESET: J1.27, U2.3

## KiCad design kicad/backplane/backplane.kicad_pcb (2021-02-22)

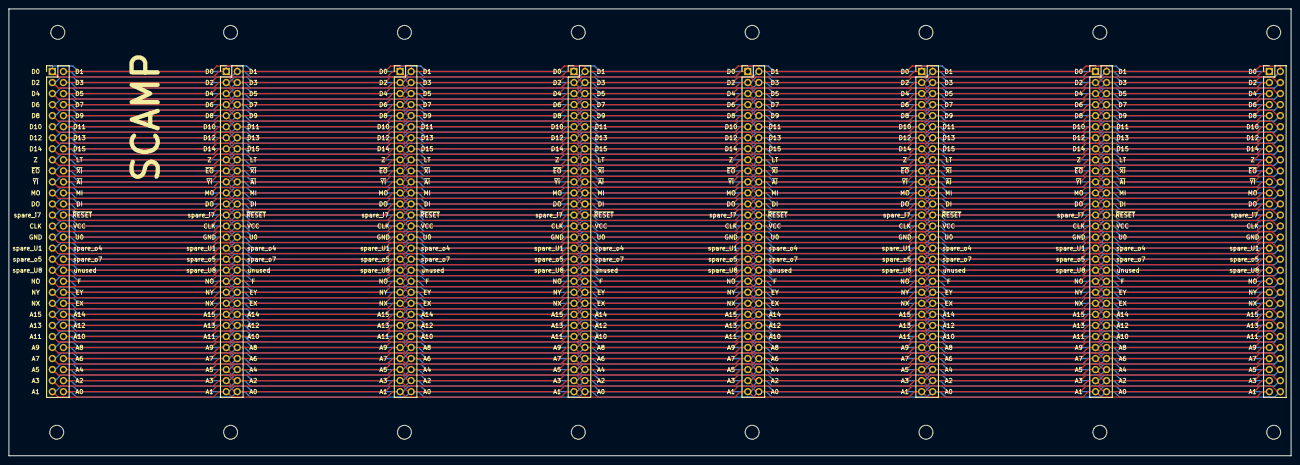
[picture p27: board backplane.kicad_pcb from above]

Board: 2 copper layers, 295.0 x 102.8 mm, 8 parts (0 on the bottom side), 60 nets.

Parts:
J1, J2, J3, J4, J5, J6, J7, J8: Conn_02x30_Counter_Clockwise; PinHeader_2x30_P2.54mm_Vertical

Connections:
A0: J1.60, J2.60, J3.60, J4.60, J5.60, J6.60, J7.60, J8.60
A1: J1.59, J2.59, J3.59, J4.59, J5.59, J6.59, J7.59, J8.59
A2: J1.58, J2.58, J3.58, J4.58, J5.58, J6.58, J7.58, J8.58
A3: J1.57, J2.57, J3.57, J4.57, J5.57, J6.57, J7.57, J8.57
A4: J1.56, J2.56, J3.56, J4.56, J5.56, J6.56, J7.56, J8.56
A5: J1.55, J2.55, J3.55, J4.55, J5.55, J6.55, J7.55, J8.55
A6: J1.54, J2.54, J3.54, J4.54, J5.54, J6.54, J7.54, J8.54
A7: J1.53, J2.53, J3.53, J4.53, J5.53, J6.53, J7.53, J8.53
A8: J1.52, J2.52, J3.52, J4.52, J5.52, J6.52, J7.52, J8.52
A9: J1.51, J2.51, J3.51, J4.51, J5.51, J6.51, J7.51, J8.51
A10: J1.50, J2.50, J3.50, J4.50, J5.50, J6.50, J7.50, J8.50
A11: J1.49, J2.49, J3.49, J4.49, J5.49, J6.49, J7.49, J8.49
A12: J1.48, J2.48, J3.48, J4.48, J5.48, J6.48, J7.48, J8.48
A13: J1.47, J2.47, J3.47, J4.47, J5.47, J6.47, J7.47, J8.47
A14: J1.46, J2.46, J3.46, J4.46, J5.46, J6.46, J7.46, J8.46
A15: J1.45, J2.45, J3.45, J4.45, J5.45, J6.45, J7.45, J8.45
CLK: J1.29, J2.29, J3.29, J4.29, J5.29, J6.29, J7.29, J8.29
D0: J1.1, J2.1, J3.1, J4.1, J5.1, J6.1, J7.1, J8.1
D1: J1.2, J2.2, J3.2, J4.2, J5.2, J6.2, J7.2, J8.2
D2: J1.3, J2.3, J3.3, J4.3, J5.3, J6.3, J7.3, J8.3
D3: J1.4, J2.4, J3.4, J4.4, J5.4, J6.4, J7.4, J8.4
D4: J1.5, J2.5, J3.5, J4.5, J5.5, J6.5, J7.5, J8.5
D5: J1.6, J2.6, J3.6, J4.6, J5.6, J6.6, J7.6, J8.6
D6: J1.7, J2.7, J3.7, J4.7, J5.7, J6.7, J7.7, J8.7
D7: J1.8, J2.8, J3.8, J4.8, J5.8, J6.8, J7.8, J8.8
D8: J1.9, J2.9, J3.9, J4.9, J5.9, J6.9, J7.9, J8.9
D9: J1.10, J2.10, J3.10, J4.10, J5.10, J6.10, J7.10, J8.10
D10: J1.11, J2.11, J3.11, J4.11, J5.11, J6.11, J7.11, J8.11
D11: J1.12, J2.12, J3.12, J4.12, J5.12, J6.12, J7.12, J8.12
D12: J1.13, J2.13, J3.13, J4.13, J5.13, J6.13, J7.13, J8.13
D13: J1.14, J2.14, J3.14, J4.14, J5.14, J6.14, J7.14, J8.14
D14: J1.15, J2.15, J3.15, J4.15, J5.15, J6.15, J7.15, J8.15
D15: J1.16, J2.16, J3.16, J4.16, J5.16, J6.16, J7.16, J8.16
DI: J1.26, J2.26, J3.26, J4.26, J5.26, J6.26, J7.26, J8.26
DO: J1.25, J2.25, J3.25, J4.25, J5.25, J6.25, J7.25, J8.25
EX: J1.44, J2.44, J3.44, J4.44, J5.44, J6.44, J7.44, J8.44
EY: J1.42, J2.42, J3.42, J4.42, J5.42, J6.42, J7.42, J8.42
F: J1.40, J2.40, J3.40, J4.40, J5.40, J6.40, J7.40, J8.40
GND: J1.31, J2.31, J3.31, J4.31, J5.31, J6.31, J7.31, J8.31
LT: J1.18, J2.18, J3.18, J4.18, J5.18, J6.18, J7.18, J8.18
MI: J1.24, J2.24, J3.24, J4.24, J5.24, J6.24, J7.24, J8.24
MO: J1.23, J2.23, J3.23, J4.23, J5.23, J6.23, J7.23, J8.23
NO: J1.39, J2.39, J3.39, J4.39, J5.39, J6.39, J7.39, J8.39
NX: J1.43, J2.43, J3.43, J4.43, J5.43, J6.43, J7.43, J8.43
NY: J1.41, J2.41, J3.41, J4.41, J5.41, J6.41, J7.41, J8.41
U0: J1.32, J2.32, J3.32, J4.32, J5.32, J6.32, J7.32, J8.32
VCC: J1.30, J2.30, J3.30, J4.30, J5.30, J6.30, J7.30, J8.30
Z: J1.17, J2.17, J3.17, J4.17, J5.17, J6.17, J7.17, J8.17
spare_U1: J1.33, J2.33, J3.33, J4.33, J5.33, J6.33, J7.33, J8.33
spare_U8: J1.37, J2.37, J3.37, J4.37, J5.37, J6.37, J7.37, J8.37
spare_i7: J1.27, J2.27, J3.27, J4.27, J5.27, J6.27, J7.27, J8.27
spare_o4: J1.34, J2.34, J3.34, J4.34, J5.34, J6.34, J7.34, J8.34
spare_o5: J1.35, J2.35, J3.35, J4.35, J5.35, J6.35, J7.35, J8.35
spare_o7: J1.36, J2.36, J3.36, J4.36, J5.36, J6.36, J7.36, J8.36
unused: J1.38, J2.38, J3.38, J4.38, J5.38, J6.38, J7.38, J8.38
~AI~: J1.22, J2.22, J3.22, J4.22, J5.22, J6.22, J7.22, J8.22
~EO~: J1.19, J2.19, J3.19, J4.19, J5.19, J6.19, J7.19, J8.19
~RESET~: J1.28, J2.28, J3.28, J4.28, J5.28, J6.28, J7.28, J8.28
~XI~: J1.20, J2.20, J3.20, J4.20, J5.20, J6.20, J7.20, J8.20
~YI~: J1.21, J2.21, J3.21, J4.21, J5.21, J6.21, J7.21, J8.21

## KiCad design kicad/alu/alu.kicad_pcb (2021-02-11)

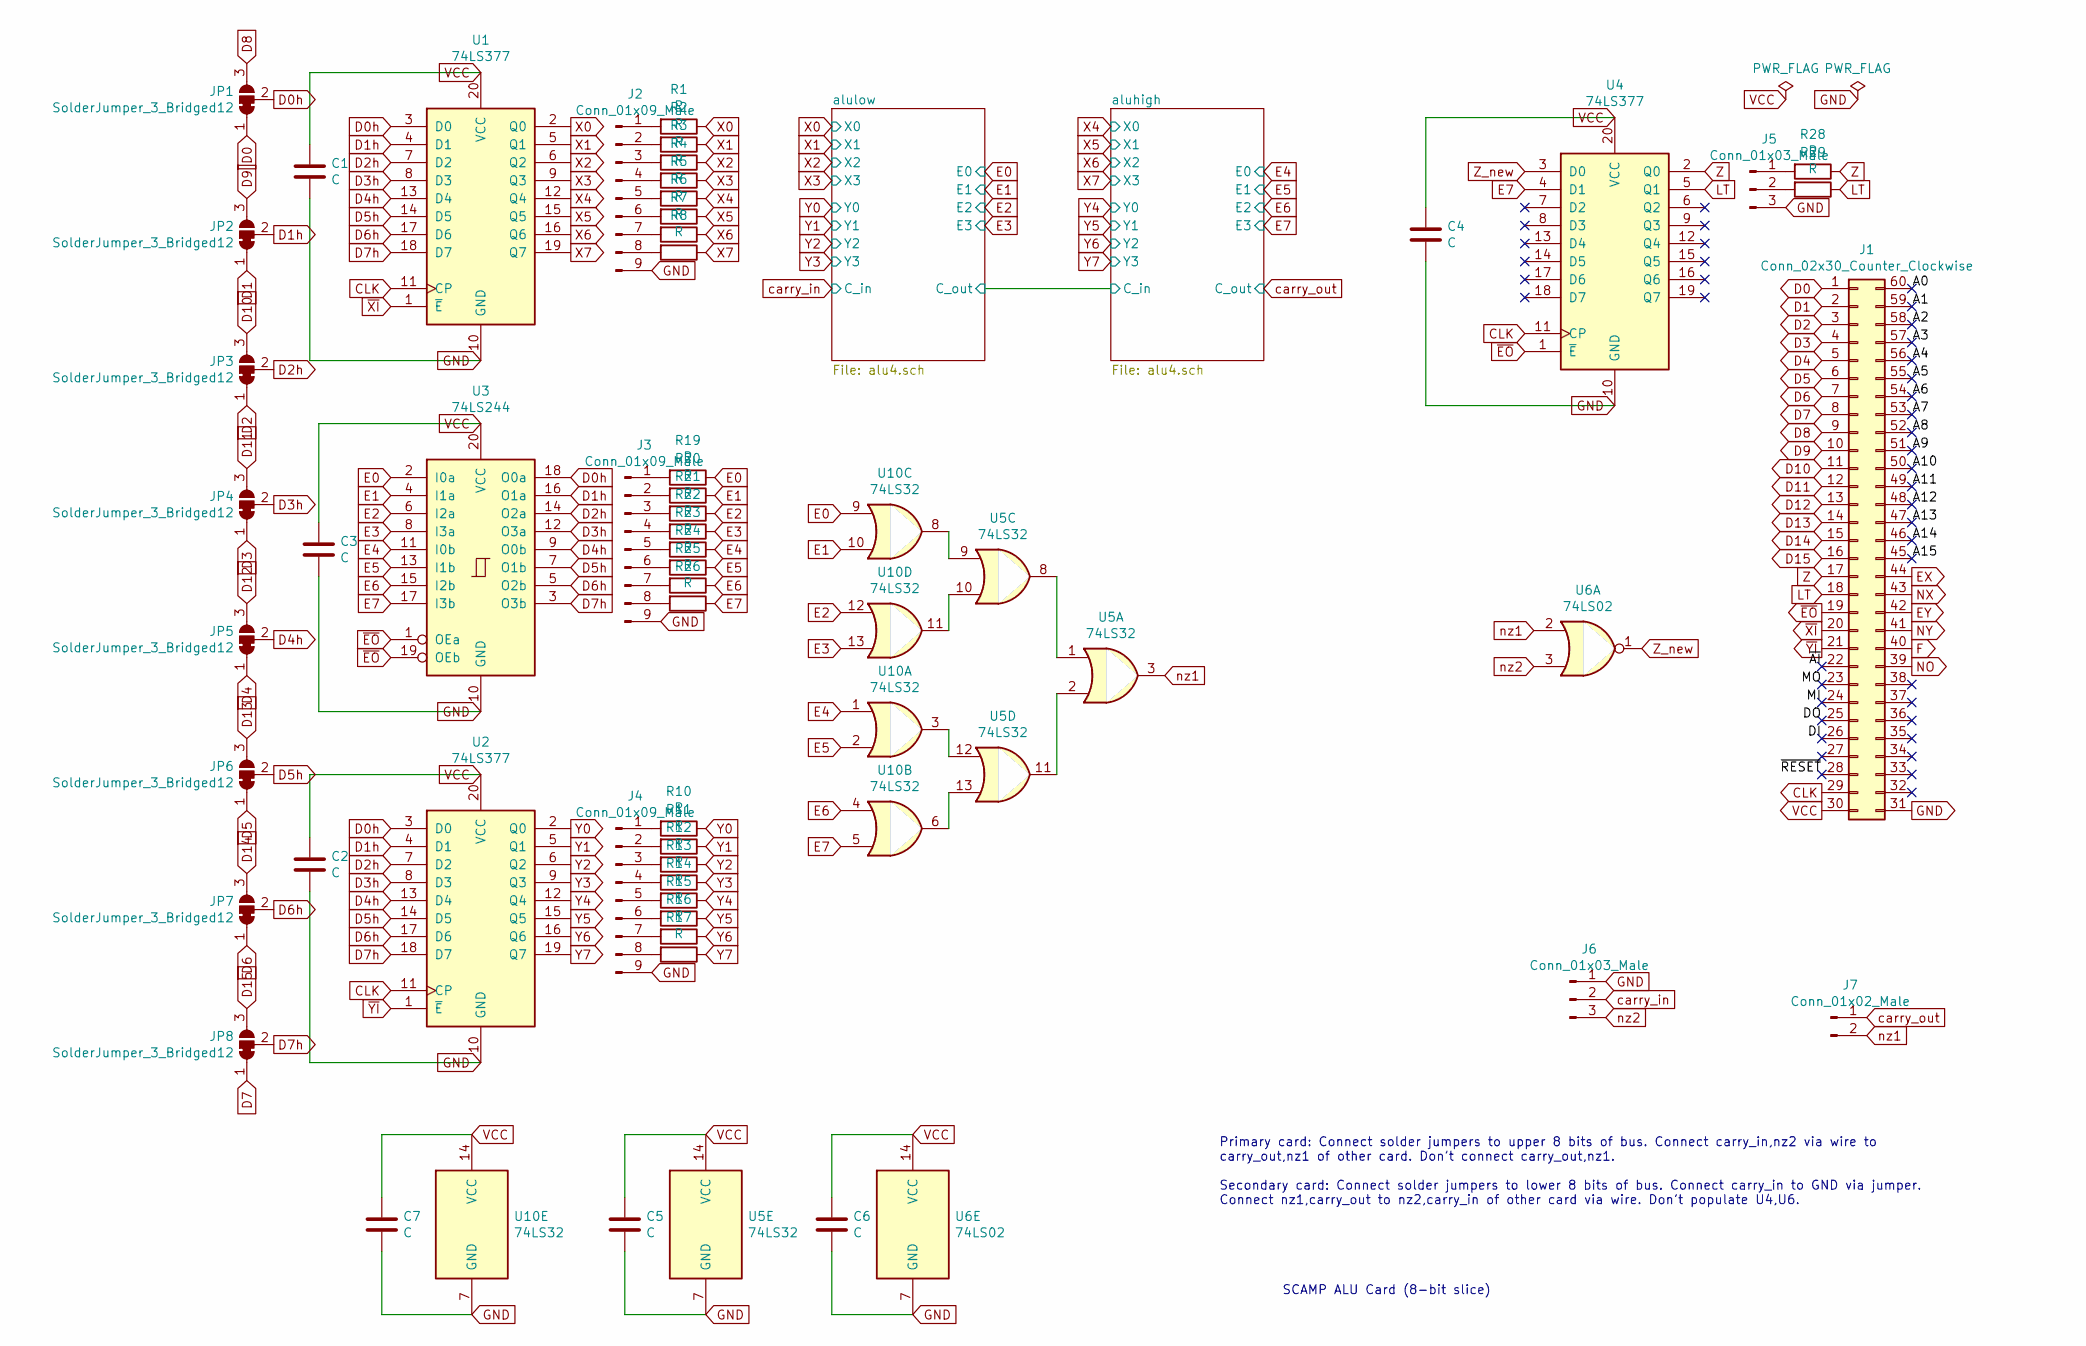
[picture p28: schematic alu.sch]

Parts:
C1, C2, C3, C4, C5, C6, C7: C; C_Disc_D5.0mm_W2.5mm_P2.50mm
J1: Conn_02x30_Counter_Clockwise; PinSocket_2x30_P2.54mm_Horizontal
J2, J3, J4: Conn_01x09_Male; PinHeader_1x09_P2.54mm_Vertical
J5, J6: Conn_01x03_Male; PinHeader_1x03_P2.54mm_Vertical
J7: Conn_01x02_Male; PinHeader_1x02_P2.54mm_Vertical
JP1, JP2, JP3, JP4, JP5, JP6, JP7, JP8: SolderJumper_3_Bridged12; SolderJumper-3_P1.3mm_Open_Pad1.0x1.5mm
R1, R2, R3, R4, R5, R6, R7, R8, R10, R11, R12, R13, R14, R15, R16, R17, R19, R20, R21, R22, R23, R24, R25, R26, R28, R29: R; R_Axial_DIN0207_L6.3mm_D2.5mm_P7.62mm_Horizontal
U1, U2, U4: 74LS377; DIP-20_W7.62mm_Socket
U3: 74LS244; DIP-20_W7.62mm_Socket
U5, U10: 74LS32; DIP-14_W7.62mm_Socket
U6: 74LS02; DIP-14_W7.62mm_Socket

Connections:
/A0: J1.60
/A1: J1.59
/A2: J1.58
/A3: J1.57
/A4: J1.56
/A5: J1.55
/A6: J1.54
/A7: J1.53
/A8: J1.52
/A9: J1.51
/A10: J1.50
/A11: J1.49
/A12: J1.48
/A13: J1.47
/A14: J1.46
/A15: J1.45
/DI: J1.26
/DO: J1.25
/MI: J1.24
/MO: J1.23
/~AI~: J1.22
/~RESET~: J1.28
CLK: J1.29, U1.11 (CP), U2.11 (CP), U4.11 (CP)
D0: J1.1, JP1.1 (A)
D0h: JP1.2 (C), U1.3 (D0), U2.3 (D0), U3.18 (O0a)
D1: J1.2, JP2.1 (A)
D1h: JP2.2 (C), U1.4 (D1), U2.4 (D1), U3.16 (O1a)
D2: J1.3, JP3.1 (A)
D2h: JP3.2 (C), U1.7 (D2), U2.7 (D2), U3.14 (O2a)
D3: J1.4, JP4.1 (A)
D3h: JP4.2 (C), U1.8 (D3), U2.8 (D3), U3.12 (O3a)
D4: J1.5, JP5.1 (A)
D4h: JP5.2 (C), U1.13 (D4), U2.13 (D4), U3.9 (O0b)
D5: J1.6, JP6.1 (A)
D5h: JP6.2 (C), U1.14 (D5), U2.14 (D5), U3.7 (O1b)
D6: J1.7, JP7.1 (A)
D6h: JP7.2 (C), U1.17 (D6), U2.17 (D6), U3.5 (O2b)
D7: J1.8, JP8.1 (A)
D7h: JP8.2 (C), U1.18 (D7), U2.18 (D7), U3.3 (O3b)
D8: J1.9, JP1.3 (B)
D9: J1.10, JP2.3 (B)
D10: J1.11, JP3.3 (B)
D11: J1.12, JP4.3 (B)
D12: J1.13, JP5.3 (B)
D13: J1.14, JP6.3 (B)
D14: J1.15, JP7.3 (B)
D15: J1.16, JP8.3 (B)
E0: R19.1, U3.2 (I0a), U10.9; also elsewhere on the board
E1: R20.1, U3.4 (I1a), U10.10; also elsewhere on the board
E2: R21.1, U3.6 (I2a), U10.12; also elsewhere on the board
E3: R22.1, U3.8 (I3a), U10.13; also elsewhere on the board
E4: R23.1, U3.11 (I0b), U10.1; also elsewhere on the board
E5: R24.1, U3.13 (I1b), U10.2; also elsewhere on the board
E6: R25.1, U3.15 (I2b), U10.4; also elsewhere on the board
E7: R26.1, U3.17 (I3b), U4.4 (D1), U10.5; also elsewhere on the board
EX: J1.44; also elsewhere on the board
EY: J1.42; also elsewhere on the board
F: J1.40; also elsewhere on the board
GND: C1.2, C2.2, C3.2, C4.2, C5.2, C6.2, C7.2, J1.31, J2.9, J3.9, J4.9, J5.3, J6.1, U1.10 (GND), U2.10 (GND), U3.10 (GND), U4.10 (GND), U5.7 (GND), U6.7 (GND), U10.7 (GND); also elsewhere on the board
LT: J1.18, R29.1, U4.5 (Q1)
NO: J1.39; also elsewhere on the board
NX: J1.43; also elsewhere on the board
NY: J1.41; also elsewhere on the board
unnamed: J2.1, R1.2
unnamed: J2.2, R2.2
unnamed: J2.3, R3.2
unnamed: J2.4, R4.2
unnamed: J2.5, R5.2
unnamed: J2.6, R6.2
unnamed: J2.7, R7.2
unnamed: J2.8, R8.2
unnamed: J3.1, R19.2
unnamed: J3.2, R20.2
unnamed: J3.3, R21.2
unnamed: J3.4, R22.2
unnamed: J3.5, R23.2
unnamed: J3.6, R24.2
unnamed: J3.7, R25.2
unnamed: J3.8, R26.2
unnamed: J4.1, R10.2
unnamed: J4.2, R11.2
unnamed: J4.3, R12.2
unnamed: J4.4, R13.2
unnamed: J4.5, R14.2
unnamed: J4.6, R15.2
unnamed: J4.7, R16.2
unnamed: J4.8, R17.2
unnamed: J5.1, R28.2
unnamed: J5.2, R29.2
unnamed: U5.1, U5.8
unnamed: U5.2, U5.11
unnamed: U5.12, U10.3
unnamed: U5.13, U10.6
unnamed: U5.9, U10.8
unnamed: U5.10, U10.11
VCC: C1.1, C2.1, C3.1, C4.1, C5.1, C6.1, C7.1, J1.30, U1.20 (VCC), U2.20 (VCC), U3.20 (VCC), U4.20 (VCC), U5.14 (VCC), U6.14 (VCC), U10.14 (VCC); also elsewhere on the board
X0: R1.1, U1.2 (Q0); also elsewhere on the board
X1: R2.1, U1.5 (Q1); also elsewhere on the board
X2: R3.1, U1.6 (Q2); also elsewhere on the board
X3: R4.1, U1.9 (Q3); also elsewhere on the board
X4: R5.1, U1.12 (Q4); also elsewhere on the board
X5: R6.1, U1.15 (Q5); also elsewhere on the board
X6: R7.1, U1.16 (Q6); also elsewhere on the board
X7: R8.1, U1.19 (Q7); also elsewhere on the board
Y0: R10.1, U2.2 (Q0); also elsewhere on the board
Y1: R11.1, U2.5 (Q1); also elsewhere on the board
Y2: R12.1, U2.6 (Q2); also elsewhere on the board
Y3: R13.1, U2.9 (Q3); also elsewhere on the board
Y4: R14.1, U2.12 (Q4); also elsewhere on the board
Y5: R15.1, U2.15 (Q5); also elsewhere on the board
Y6: R16.1, U2.16 (Q6); also elsewhere on the board
Y7: R17.1, U2.19 (Q7); also elsewhere on the board
Z: J1.17, R28.1, U4.2 (Q0)
Z_new: U4.3 (D0), U6.1
carry_in: J6.2; also elsewhere on the board
carry_out: J7.1; also elsewhere on the board
nz1: J7.2, U5.3, U6.2
nz2: J6.3, U6.3
~EO~: J1.19, U3.1 (OEa), U3.19 (OEb), U4.1 (~E)
~XI~: J1.20, U1.1 (~E)
~YI~: J1.21, U2.1 (~E)

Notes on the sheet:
SCAMP ALU Card (8-bit slice)
Primary card: Connect solder jumpers to upper 8 bits of bus. Connect carry_in,nz2 via wire to carry_out,nz1 of other card. Don't connect carry_out,nz1. Secondary card: Connect solder jumpers to lower 8 bits of bus. Connect carry_in to GND via jumper. Connect nz1,carry_out to nz2,carry_in of other c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

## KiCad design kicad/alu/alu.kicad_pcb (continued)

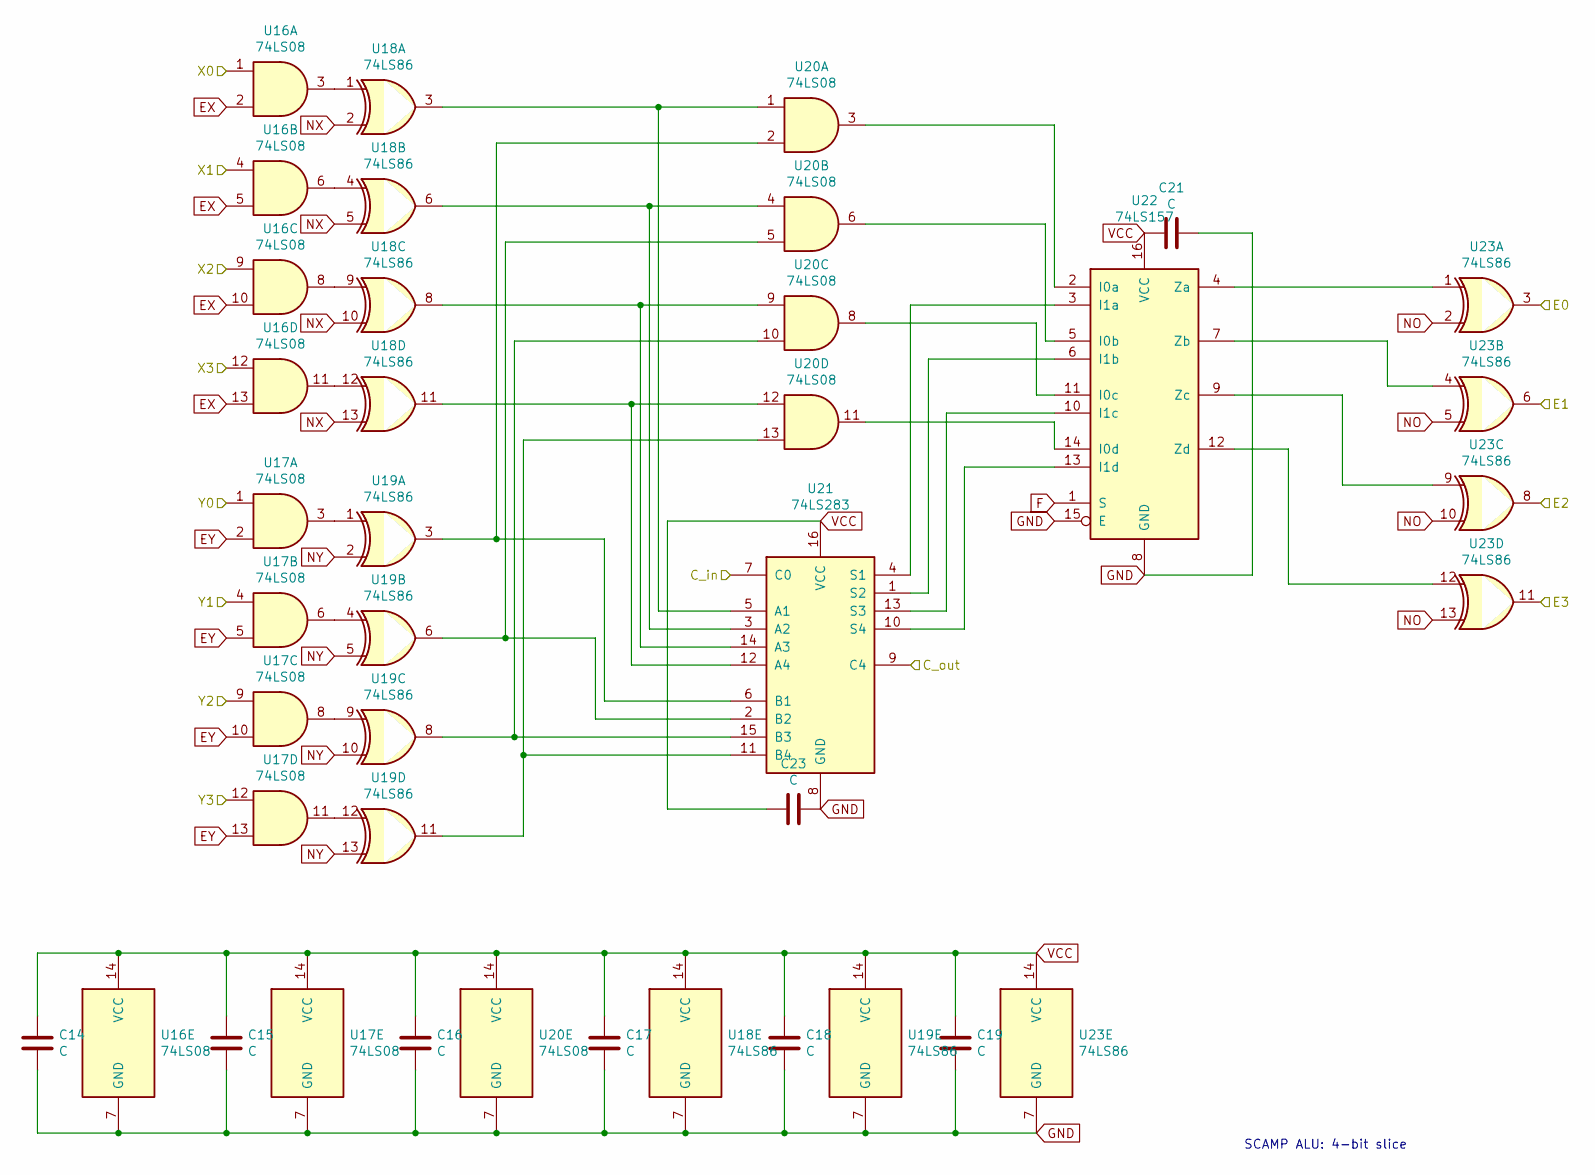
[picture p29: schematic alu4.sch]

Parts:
C14, C15, C16, C17, C18, C19, C20, C22: C; C_Disc_D5.0mm_W2.5mm_P2.50mm
U7, U8, U9: 74LS08; DIP-14_W7.62mm_Socket
U11: 74LS283; DIP-16_W7.62mm_Socket
U12: 74LS157; DIP-16_W7.62mm_Socket
U13, U14, U15: 74LS86; DIP-14_W7.62mm_Socket

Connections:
/aluhigh/C_in: U11.9 (C4); also elsewhere on the board
E0: U15.3; also elsewhere on the board
E1: U15.6; also elsewhere on the board
E2: U15.8; also elsewhere on the board
E3: U15.11; also elsewhere on the board
EX: U7.2, U7.5, U7.10, U7.13; also elsewhere on the board
EY: U8.2, U8.5, U8.10, U8.13; also elsewhere on the board
F: U12.1 (S); also elsewhere on the board
GND: C14.2, C15.2, C16.2, C17.2, C18.2, C19.2, C20.1, C22.1, U7.7 (GND), U8.7 (GND), U9.7 (GND), U11.8 (GND), U12.8 (GND), U12.15 (E), U13.7 (GND), U14.7 (GND), U15.7 (GND); also elsewhere on the board
NO: U15.2, U15.5, U15.10, U15.13; also elsewhere on the board
NX: U13.2, U13.5, U13.10, U13.13; also elsewhere on the board
NY: U14.2, U14.5, U14.10, U14.13; also elsewhere on the board
unnamed: U11.1 (S2), U12.6 (I1b)
unnamed: U9.5, U11.2 (B2), U14.6
unnamed: U9.4, U11.3 (A2), U13.6
unnamed: U11.4 (S1), U12.3 (I1a)
unnamed: U9.1, U11.5 (A1), U13.3
unnamed: U9.2, U11.6 (B1), U14.3
unnamed: U11.10 (S4), U12.13 (I1d)
unnamed: U9.13, U11.11 (B4), U14.11
unnamed: U9.12, U11.12 (A4), U13.11
unnamed: U11.13 (S3), U12.10 (I1c)
unnamed: U9.9, U11.14 (A3), U13.8
unnamed: U9.10, U11.15 (B3), U14.8
unnamed: U9.3, U12.2 (I0a)
unnamed: U12.4 (Za), U15.1
unnamed: U9.6, U12.5 (I0b)
unnamed: U12.7 (Zb), U15.4
unnamed: U12.9 (Zc), U15.9
unnamed: U9.8, U12.11 (I0c)
unnamed: U12.12 (Zd), U15.12
unnamed: U9.11, U12.14 (I0d)
unnamed: U7.3, U13.1
unnamed: U7.6, U13.4
unnamed: U7.8, U13.9
unnamed: U7.11, U13.12
unnamed: U8.3, U14.1
unnamed: U8.6, U14.4
unnamed: U8.8, U14.9
unnamed: U8.11, U14.12
VCC: C14.1, C15.1, C16.1, C17.1, C18.1, C19.1, C20.2, C22.2, U7.14 (VCC), U8.14 (VCC), U9.14 (VCC), U11.16 (VCC), U12.16 (VCC), U13.14 (VCC), U14.14 (VCC), U15.14 (VCC); also elsewhere on the board
X0: U7.1; also elsewhere on the board
X1: U7.4; also elsewhere on the board
X2: U7.9; also elsewhere on the board
X3: U7.12; also elsewhere on the board
Y0: U8.1; also elsewhere on the board
Y1: U8.4; also elsewhere on the board
Y2: U8.9; also elsewhere on the board
Y3: U8.12; also elsewhere on the board
carry_in: U11.7 (C0); also elsewhere on the board

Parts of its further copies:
C8, C9, C10, C11, C12, C13, C21, C23: C; C_Disc_D5.0mm_W2.5mm_P2.50mm
U18, U19, U23: 74LS86; DIP-14_W7.62mm_Socket
U20: 74LS08; DIP-14_W7.62mm_Socket
U21: 74LS283; DIP-16_W7.62mm_Socket
U22: 74LS157; DIP-16_W7.62mm_Socket

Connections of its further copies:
/aluhigh/C_in: U21.7 (C0); also elsewhere on the board
E4: U23.3; also elsewhere on the board
E5: U23.6; also elsewhere on the board
E6: U23.8; also elsewhere on the board
E7: U23.11; also elsewhere on the board
F: U22.1 (S); also elsewhere on the board
GND: C8.2, C9.2, C10.2, C11.2, C12.2, C13.2, C21.1, C23.1, U18.7 (GND), U19.7 (GND), U20.7 (GND), U21.8 (GND), U22.8 (GND), U22.15 (E), U23.7 (GND); also elsewhere on the board
NO: U23.2, U23.5, U23.10, U23.13; also elsewhere on the board
NX: U18.2, U18.5, U18.10, U18.13; also elsewhere on the board
NY: U19.2, U19.5, U19.10, U19.13; also elsewhere on the board
unnamed 144: U18.1; also elsewhere on the board
unnamed 145: U18.4; also elsewhere on the board
unnamed 146: U18.9; also elsewhere on the board
unnamed 147: U18.12; also elsewhere on the board
unnamed 148: U19.1; also elsewhere on the board
unnamed 149: U19.4; also elsewhere on the board
unnamed 150: U19.9; also elsewhere on the board
unnamed 151: U19.12; also elsewhere on the board
unnamed: U18.3, U20.1, U21.5 (A1)
unnamed: U18.6, U20.4, U21.3 (A2)
unnamed: U18.8, U20.9, U21.14 (A3)
unnamed: U18.11, U20.12, U21.12 (A4)
unnamed: U19.3, U20.2, U21.6 (B1)
unnamed: U19.6, U20.5, U21.2 (B2)
unnamed: U19.8, U20.10, U21.15 (B3)
unnamed: U19.11, U20.13, U21.11 (B4)
unnamed: U20.3, U22.2 (I0a)
unnamed: U20.6, U22.5 (I0b)
unnamed: U20.8, U22.11 (I0c)
unnamed: U20.11, U22.14 (I0d)
unnamed: U21.1 (S2), U22.6 (I1b)
unnamed: U21.4 (S1), U22.3 (I1a)
unnamed: U21.10 (S4), U22.13 (I1d)
unnamed: U21.13 (S3), U22.10 (I1c)
unnamed: U22.4 (Za), U23.1
unnamed: U22.7 (Zb), U23.4
unnamed: U22.9 (Zc), U23.9
unnamed: U22.12 (Zd), U23.12
VCC: C8.1, C9.1, C10.1, C11.1, C12.1, C13.1, C21.2, C23.2, U18.14 (VCC), U19.14 (VCC), U20.14 (VCC), U21.16 (VCC), U22.16 (VCC), U23.14 (VCC); also elsewhere on the board
carry_out: U21.9 (C4); also elsewhere on the board

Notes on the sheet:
SCAMP ALU: 4-bit slice

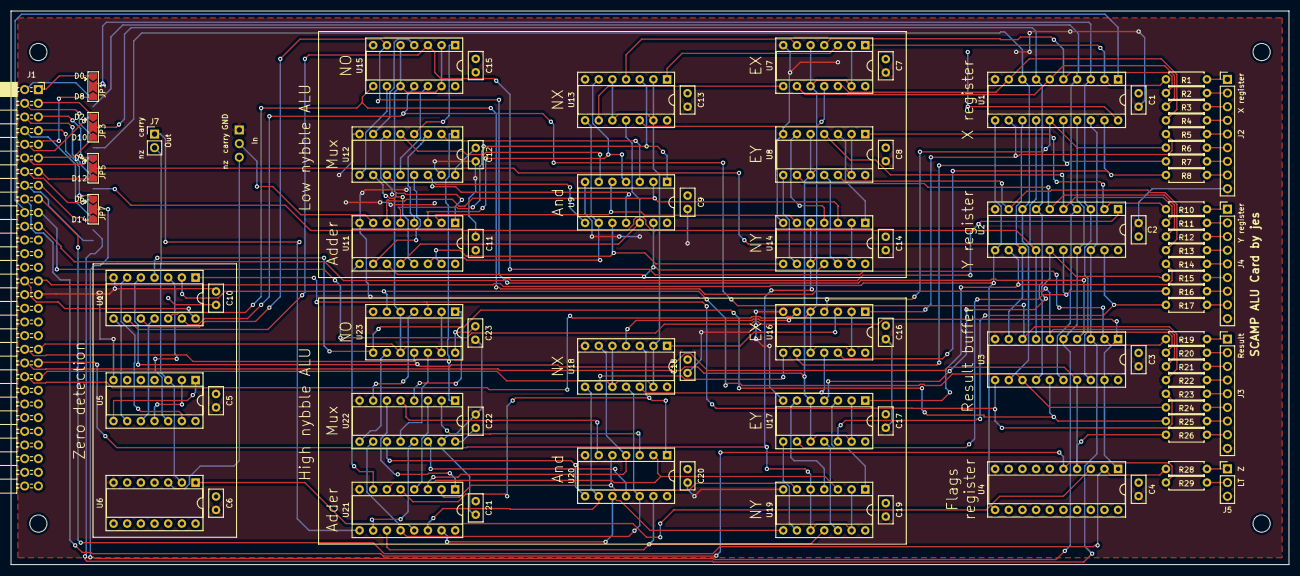
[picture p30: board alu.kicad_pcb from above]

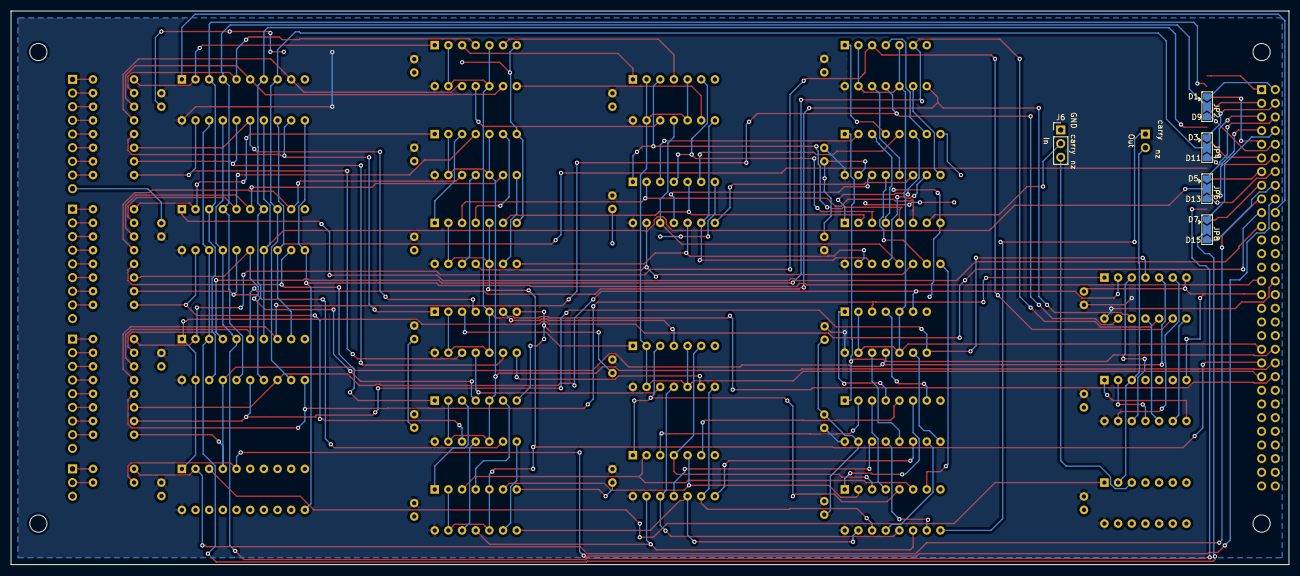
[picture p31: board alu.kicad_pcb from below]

Board: 2 copper layers, 237.5 x 102.9 mm, 87 parts (5 on the bottom side), 156 nets.

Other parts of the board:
U16, U17: 74LS08; DIP-14_W7.62mm_Socket

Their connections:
EX: U16.2, U16.5, U16.10, U16.13; also elsewhere on the board
EY: U17.2, U17.5, U17.10, U17.13; also elsewhere on the board
GND: U16.7, U17.7; also elsewhere on the board
unnamed 144: U16.3; also elsewhere on the board
unnamed 145: U16.6; also elsewhere on the board
unnamed 146: U16.8; also elsewhere on the board
unnamed 147: U16.11; also elsewhere on the board
unnamed 148: U17.3; also elsewhere on the board
unnamed 149: U17.6; also elsewhere on the board
unnamed 150: U17.8; also elsewhere on the board
unnamed 151: U17.11; also elsewhere on the board
VCC: U16.14, U17.14; also elsewhere on the board
X4: U16.1; also elsewhere on the board
X5: U16.4; also elsewhere on the board
X6: U16.9; also elsewhere on the board
X7: U16.12; also elsewhere on the board
Y4: U17.1; also elsewhere on the board
Y5: U17.4; also elsewhere on the board
Y6: U17.9; also elsewhere on the board
Y7: U17.12; also elsewhere on the board

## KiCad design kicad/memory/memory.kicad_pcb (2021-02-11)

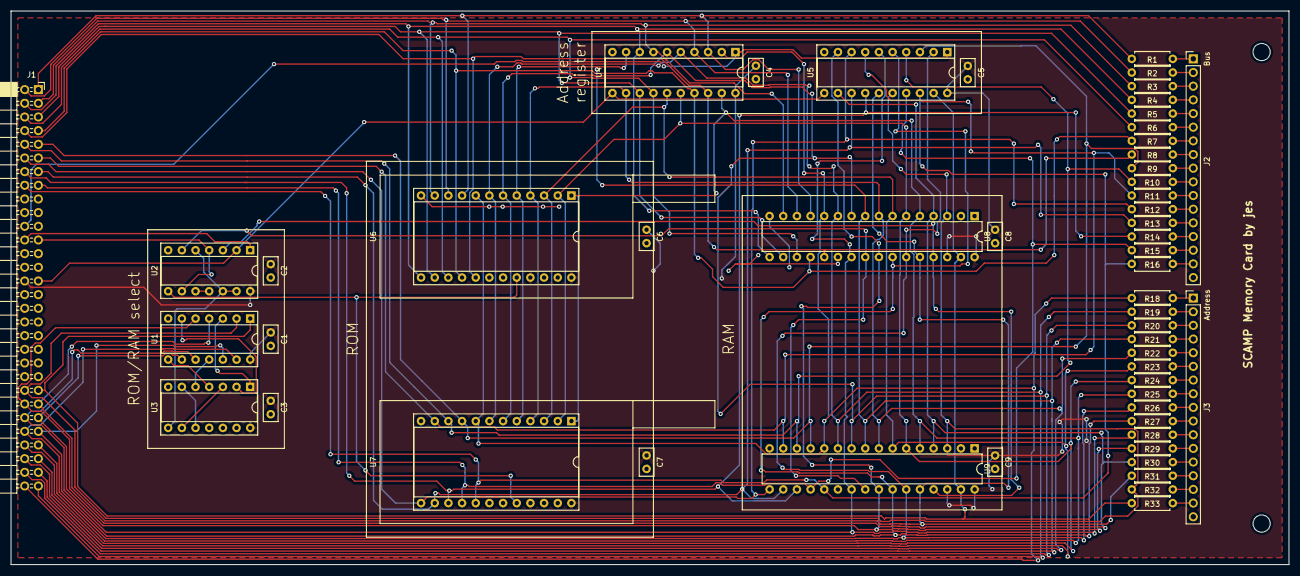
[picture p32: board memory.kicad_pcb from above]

Board: 2 copper layers, 237.5 x 102.9 mm, 53 parts (0 on the bottom side), 81 nets.

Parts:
C1, C2, C3, C4, C5, C6, C7, C8, C9: C; C_Disc_D5.0mm_W2.5mm_P2.50mm
J1: Conn_02x30_Counter_Clockwise; PinSocket_2x30_P2.54mm_Horizontal
J2, J3: Conn_01x17_Male; PinHeader_1x17_P2.54mm_Vertical
R1, R2, R3, R4, R5, R6, R7, R8, R9, R10, R11, R12, R13, R14, R15, R16, R18, R19, R20, R21, R22, R23, R24, R25, R26, R27, R28, R29, R30, R31, R32, R33: R; R_Axial_DIN0207_L6.3mm_D2.5mm_P7.62mm_Horizontal
U1, U3: 74LS32; DIP-14_W7.62mm_Socket
U2: 74LS00; DIP-14_W7.62mm_Socket
U4, U5: 74LS377; DIP-20_W7.62mm_Socket
U6, U7: 28C16; DIP-24_W15.24mm_Socket
U8, U9: W24512A; DIP-32_W7.62mm

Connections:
A0: J1.60, R18.1, U4.2, U6.8, U7.8, U8.12, U9.12
A1: J1.59, R19.1, U4.5, U6.7, U7.7, U8.11, U9.11
A2: J1.58, R20.1, U4.6, U6.6, U7.6, U8.10, U9.10
A3: J1.57, R21.1, U4.9, U6.5, U7.5, U8.9, U9.9
A4: J1.56, R22.1, U4.12, U6.4, U7.4, U8.8, U9.8
A5: J1.55, R23.1, U4.15, U6.3, U7.3, U8.7, U9.7
A6: J1.54, R24.1, U4.16, U6.2, U7.2, U8.6, U9.6
A7: J1.53, R25.1, U4.19, U6.1, U7.1, U8.5, U9.5
A8: J1.52, R26.1, U1.13, U5.2, U8.27, U9.27
A9: J1.51, R27.1, U1.12, U5.5, U8.26, U9.26
A10: J1.50, R28.1, U1.10, U5.6, U8.23, U9.23
A11: J1.49, R29.1, U1.9, U5.9, U8.25, U9.25
A12: J1.48, R30.1, U1.5, U5.12, U8.4, U9.4
A13: J1.47, R31.1, U1.4, U5.15, U8.28, U9.28
A14: J1.46, R32.1, U1.2, U5.16, U8.3, U9.3
A15: J1.45, R33.1, U1.1, U5.19, U8.31, U9.31
CLK: J1.29, U2.2, U4.11, U5.11
D0: J1.1, R1.1, U4.3, U6.9, U8.13
D1: J1.2, R2.1, U4.4, U6.10, U8.14
D2: J1.3, R3.1, U4.7, U6.11, U8.15
D3: J1.4, R4.1, U4.8, U6.13, U8.17
D4: J1.5, R5.1, U4.13, U6.14, U8.18
D5: J1.6, R6.1, U4.14, U6.15, U8.19
D6: J1.7, R7.1, U4.17, U6.16, U8.20
D7: J1.8, R8.1, U4.18, U6.17, U8.21
D8: J1.9, R9.1, U5.3, U7.9, U9.13
D9: J1.10, R10.1, U5.4, U7.10, U9.14
D10: J1.11, R11.1, U5.7, U7.11, U9.15
D11: J1.12, R12.1, U5.8, U7.13, U9.17
D12: J1.13, R13.1, U5.13, U7.14, U9.18
D13: J1.14, R14.1, U5.14, U7.15, U9.19
D14: J1.15, R15.1, U5.17, U7.16, U9.20
D15: J1.16, R16.1, U5.18, U7.17, U9.21
GND: C1.2, C2.2, C3.2, C4.2, C5.2, C6.2, C7.2, C8.2, C9.2, J1.31, J2.17, J3.17, U1.7, U2.7, U3.7, U4.10, U5.10, U6.12, U6.18, U6.19, U6.22, U6.23, U7.12, U7.18, U7.19, U7.22, U7.23, U8.16, U8.22, U9.16, U9.22
MI: J1.24, U2.1
MO: J1.23, U2.4, U2.9
unnamed: J2.1, R1.2
unnamed: J2.2, R2.2
unnamed: J2.3, R3.2
unnamed: J2.4, R4.2
unnamed: J2.5, R5.2
unnamed: J2.6, R6.2
unnamed: J2.7, R7.2
unnamed: J2.8, R8.2
unnamed: J2.9, R9.2
unnamed: J2.10, R10.2
unnamed: J2.11, R11.2
unnamed: J2.12, R12.2
unnamed: J2.13, R13.2
unnamed: J2.14, R14.2
unnamed: J2.15, R15.2
unnamed: J2.16, R16.2
unnamed: J3.1, R18.2
unnamed: J3.2, R19.2
unnamed: J3.3, R20.2
unnamed: J3.4, R21.2
unnamed: J3.5, R22.2
unnamed: J3.6, R23.2
unnamed: J3.7, R24.2
unnamed: J3.8, R25.2
unnamed: J3.9, R26.2
unnamed: J3.10, R27.2
unnamed: J3.11, R28.2
unnamed: J3.12, R29.2
unnamed: J3.13, R30.2
unnamed: J3.14, R31.2
unnamed: J3.15, R32.2
unnamed: J3.16, R33.2
unnamed: U1.3, U3.1
unnamed: U1.6, U3.2
unnamed: U1.8, U3.4
unnamed: U1.11, U3.5
unnamed: U2.10, U2.11
unnamed: U3.3, U3.9
unnamed: U3.6, U3.10
VCC: C1.1, C2.1, C3.1, C4.1, C5.1, C6.1, C7.1, C8.1, C9.1, J1.30, U1.14, U2.14, U3.14, U4.20, U5.20, U6.21, U6.24, U7.21, U7.24, U8.30, U8.32, U9.30, U9.32
want_ram: U2.5, U2.12, U2.13, U3.8
~AI~: J1.22, U4.1, U5.1
~LOAD_CLK~: U2.3, U8.29, U9.29
~RAM_EN~: U2.6, U8.24, U9.24
~ROM_EN~: U2.8, U6.20, U7.20

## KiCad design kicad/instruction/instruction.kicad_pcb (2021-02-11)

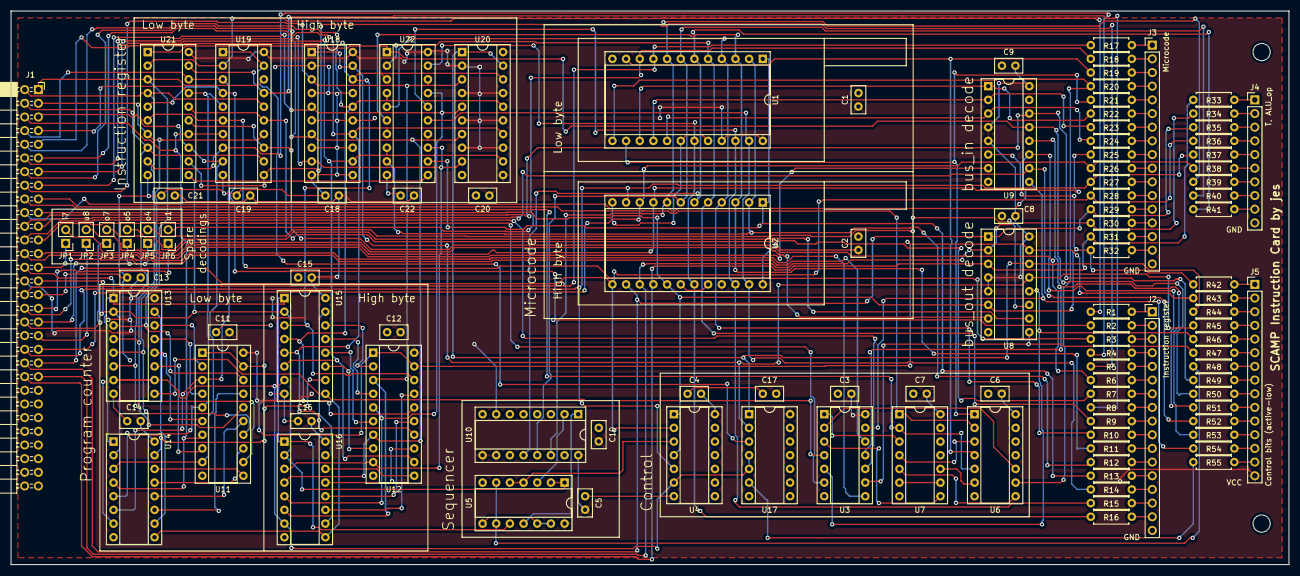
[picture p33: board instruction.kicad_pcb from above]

Board: 2 copper layers, 237.5 x 102.9 mm, 110 parts (0 on the bottom side), 172 nets.

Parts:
C1, C2, C3, C4, C5, C6, C7, C8, C9, C10, C11, C12, C13, C14, C15, C16, C17, C18, C19, C20, C21, C22: C; C_Disc_D5.0mm_W2.5mm_P2.50mm
J1: Conn_02x30_Counter_Clockwise; PinSocket_2x30_P2.54mm_Horizontal
J2, J3: Conn_01x17_Male; PinHeader_1x17_P2.54mm_Vertical
J4: Conn_01x10_Male; PinHeader_1x10_P2.54mm_Vertical
J5: Conn_01x15_Male; PinHeader_1x15_P2.54mm_Vertical
JP1, JP2, JP3, JP4, JP5, JP6: Jumper_NO_Small; PinHeader_1x02_P2.54mm_Vertical
R1, R2, R3, R4, R5, R6, R7, R8, R9, R10, R11, R12, R13, R14, R15, R16, R17, R18, R19, R20, R21, R22, R23, R24, R25, R26, R27, R28, R29, R30, R31, R32, R33, R34, R35, R36, R37, R38, R39, R40, R41, R42, R43, R44, R45, R46, R47, R48, R49, R50, R51, R52, R53, R54, R55: R; R_Axial_DIN0207_L6.3mm_D2.5mm_P7.62mm_Horizontal
U1, U2: 28C16; DIP-24_W15.24mm_Socket
U3: 74LS04; DIP-14_W7.62mm_Socket
U4, U6: 74LS08; DIP-14_W7.62mm_Socket
U5, U17: 74LS00; DIP-14_W7.62mm_Socket
U7: 74LS32; DIP-14_W7.62mm_Socket
U8, U9: 74LS138; DIP-16_W7.62mm_Socket
U10, U13, U14, U15, U16: 74LS161; DIP-16_W7.62mm_Socket
U11, U12, U18, U19, U20: 74LS244; DIP-20_W7.62mm_Socket
U21, U22: 74LS377; DIP-20_W7.62mm_Socket

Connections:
CLK: J1.29, U5.1, U5.2, U13.2, U14.2, U15.2, U16.2, U21.11, U22.11
D0: J1.1, U11.18, U13.3, U19.18, U21.3
D1: J1.2, U11.16, U13.4, U19.16, U21.4
D2: J1.3, U11.14, U13.5, U19.14, U21.7
D3: J1.4, U11.12, U13.6, U19.12, U21.8
D4: J1.5, U11.9, U14.3, U19.9, U21.13
D5: J1.6, U11.7, U14.4, U19.7, U21.14
D6: J1.7, U11.5, U14.5, U19.5, U21.17
D7: J1.8, U11.3, U14.6, U19.3, U21.18
D8: J1.9, U12.18, U15.3, U18.18, U20.18, U22.3
D9: J1.10, U12.16, U15.4, U18.16, U20.16, U22.4
D10: J1.11, U12.14, U15.5, U18.14, U20.14, U22.7
D11: J1.12, U12.12, U15.6, U18.12, U20.12, U22.8
D12: J1.13, U12.9, U16.3, U18.9, U20.9, U22.13
D13: J1.14, U12.7, U16.4, U18.7, U20.7, U22.14
D14: J1.15, U12.5, U16.5, U18.5, U20.5, U22.17
D15: J1.16, U12.3, U16.6, U18.3, U20.3, U22.18
DI: J1.26, U3.12
DO: J1.25, U3.8
EX: J1.44, R31.1, R33.1, U2.16, U8.3
EY: J1.42, R29.1, R35.1, U2.14, U8.1
F: J1.40, R27.1, R37.1, U2.11, U4.5
GND: C1.2, C2.2, C3.2, C4.2, C5.2, C6.2, C7.2, C8.2, C9.2, C10.2, C11.2, C12.2, C13.2, C14.2, C15.2, C16.2, C17.2, C18.2, C19.2, C20.2, C21.2, C22.2, J1.31, J2.17, J3.17, J4.10, U1.12, U1.18, U1.20, U2.12, U2.18, U2.20, U3.7, U4.7, U5.7, U6.7, U7.7, U8.8, U9.8, U10.8, U11.10, U12.10, U13.8, U14.8, U15.8, U16.8, U17.7, U18.2, U18.4, U18.6, U18.8, U18.10, U18.11, U18.13, U18.15, U18.17, U19.10, U20.10, U21.10, U22.10
GT: U3.2, U6.10
I0: R1.1, U19.2, U21.2
I1: R2.1, U19.4, U21.5
I2: R3.1, U19.6, U21.6
I3: R4.1, U19.8, U21.9
I4: R5.1, U19.11, U21.12
I5: R6.1, U19.13, U21.15
I6: R7.1, U19.15, U21.16
I7: R8.1, U19.17, U21.19
I8: R9.1, U1.5, U2.5, U22.2
I9: R10.1, U1.4, U2.4, U22.5
I10: R11.1, U1.3, U2.3, U22.6
I11: R12.1, U1.2, U2.2, U22.9
I12: R13.1, U1.1, U2.1, U22.12
I13: R14.1, U1.23, U2.23, U22.15
I14: R15.1, U1.22, U2.22, U22.16
I15: R16.1, U1.19, U2.19, U22.19
JGT: R20.1, U1.13, U6.9
JGT_GT: U6.8, U7.5
JLT: R19.1, U1.11, U6.4
JLT_LT: U6.6, U7.10
JMP: U3.3, U7.8
JZ: R21.1, U1.14, U6.1
JZ_Z: U6.3, U7.4
LT: J1.18, U6.5, U7.2
MI: J1.24, U3.10
MO: J1.23, U3.6
NO: J1.39, R26.1, R38.1, U2.10
NX: J1.43, R30.1, R34.1, U2.15, U8.2
NY: J1.41, R28.1, R36.1, U2.13, U4.2
unnamed: J1.27, JP1.1
unnamed: J1.33, JP6.1
unnamed: J1.34, JP5.1
unnamed: J1.35, JP4.1
unnamed: J1.36, JP3.1
unnamed: J1.37, JP2.1
unnamed: J2.1, R1.2
unnamed: J2.2, R2.2
unnamed: J2.3, R3.2
unnamed: J2.4, R4.2
unnamed: J2.5, R5.2
unnamed: J2.6, R6.2
unnamed: J2.7, R7.2
unnamed: J2.8, R8.2
unnamed: J2.9, R9.2
unnamed: J2.10, R10.2
unnamed: J2.11, R11.2
unnamed: J2.12, R12.2
unnamed: J2.13, R13.2
unnamed: J2.14, R14.2
unnamed: J2.15, R15.2
unnamed: J2.16, R16.2
unnamed: J3.1, R17.2
unnamed: J3.2, R18.2
unnamed: J3.3, R19.2
unnamed: J3.4, R20.2
unnamed: J3.5, R21.2
unnamed: J3.6, R22.2
unnamed: J3.7, R23.2
unnamed: J3.8, R24.2
unnamed: J3.9, R25.2
unnamed: J3.10, R26.2
unnamed: J3.11, R27.2
unnamed: J3.12, R28.2
unnamed: J3.13, R29.2
unnamed: J3.14, R30.2
unnamed: J3.15, R31.2
unnamed: J3.16, R32.2
unnamed: J4.1, R33.2
unnamed: J4.2, R34.2
unnamed: J4.3, R35.2
unnamed: J4.4, R36.2
unnamed: J4.5, R37.2
unnamed: J4.6, R38.2
unnamed: J4.7, R39.2
unnamed: J4.8, R40.2
unnamed: J4.9, R41.2
unnamed: J5.1, R42.2
unnamed: J5.2, R43.2
unnamed: J5.3, R44.2
unnamed: J5.4, R45.2
unnamed: J5.5, R46.2
unnamed: J5.6, R47.2
unnamed: J5.7, R48.2
unnamed: J5.8, R49.2
unnamed: J5.9, R50.2
unnamed: J5.10, R51.2
unnamed: J5.11, R52.2
unnamed: J5.12, R53.2
unnamed: J5.13, R54.2
unnamed: J5.14, R55.2
unnamed: U5.8, U5.12, U5.13
unnamed: U7.6, U7.9
unnamed: U13.15, U14.10
unnamed: U14.15, U15.10
unnamed: U15.15, U16.10
P0: U11.2, U13.14
P1: U11.4, U13.13
P2: U11.6, U13.12
P3: U11.8, U13.11
P4: U11.11, U14.14
P5: U11.13, U14.13
P6: U11.15, U14.12
P7: U11.17, U14.11
P8: U12.2, U15.14
P9: U12.4, U15.13
P10: U12.6, U15.12
P11: U12.8, U15.11
P12: U12.11, U16.14
P13: U12.13, U16.13
P14: U12.15, U16.12
P15: U12.17, U16.11
PP: U4.6, U13.7, U13.10, U14.7, U15.7, U16.7, U17.4, U17.5
RT: U4.3, U5.4, U5.5
T0: R39.1, U1.8, U2.8, U10.14
T1: R40.1, U1.7, U2.7, U10.13
T2: R41.1, U1.6, U2.6, U10.12
U0: J1.32, R17.1, U1.9
U1: JP6.2, R18.1, U1.10
U5: R22.1, U1.15, U9.1
U6: R23.1, U1.16, U9.2
U7: R24.1, U1.17, U9.3
U8: JP2.2, R25.1, U2.9
U15: J1.19, R32.1, R42.1, U2.17, U4.1, U4.4, U8.6, U9.6
VCC: C1.1, C2.1, C3.1, C4.1, C5.1, C6.1, C7.1, C8.1, C9.1, C10.1, C11.1, C12.1, C13.1, C14.1, C15.1, C16.1, C17.1, C18.1, C19.1, C20.1, C21.1, C22.1, J1.30, J5.15, U1.21, U1.24, U2.21, U2.24, U3.14, U4.14, U5.14, U6.14, U7.14, U8.4, U8.5, U8.16, U9.4, U9.5, U9.16, U10.7, U10.9, U10.10, U10.16, U11.20, U12.20, U13.16, U14.16, U15.16, U16.16, U17.14, U18.20, U19.20, U20.2, U20.4, U20.6, U20.8, U20.11, U20.13, U20.15, U20.17, U20.20, U21.20, U22.20
Z: J1.17, U6.2, U7.1
Z_LT: U3.1, U7.3
inv_CLK: U5.3, U10.2
inv_DI: R54.1, U3.13, U9.9
inv_DO: R47.1, U3.9, U8.9
inv_MI: R53.1, U3.11, U9.12
inv_MO: R46.1, U3.5, U8.12
inv_PP: R55.1, U17.6
inv_RT: R48.1, U5.6, U5.9
spare_I7: JP1.2, U9.7
spare_O4: JP5.2, U8.11
spare_O5: JP4.2, U8.10
spare_O7: JP3.2, U8.7
~AI~: J1.22, R49.1, U9.14
~II~: R50.1, U9.13, U21.1, U22.1
~IOH~: R44.1, U8.14, U17.1, U20.1, U20.19
~IOLH~: U17.3, U19.1, U19.19
~IOL~: R45.1, U8.13, U17.2, U18.1, U18.19
~JMP~: U3.4, U13.9, U14.9, U15.9, U16.9
~PO~: R43.1, U8.15, U11.1, U11.19, U12.1, U12.19
~RESET~: J1.28, U5.10, U13.1, U14.1, U15.1, U16.1
~XI~: J1.20, R51.1, U9.11
~YI~: J1.21, R52.1, U9.10
~reset_T~: U5.11, U10.1

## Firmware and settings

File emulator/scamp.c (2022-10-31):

/* SCAMP emulator

   James Stanley 2021
*/

#include <errno.h>
#include <fcntl.h>
#include <getopt.h>
#include <poll.h>
#include <stdint.h>
#include <stdio.h>
#include <stdlib.h>
#include <signal.h>
#include <string.h>
#include <sys/mman.h>
#include <sys/time.h>
#include <sys/types.h>
#include <sys/stat.h>
#include <termios.h>
#include <time.h>
#include <unistd.h>

#ifdef EMSCRIPTEN
#include <emscripten/emscripten.h>
#endif

/* this is a pretty lame 8250 emulation, it only really supports the
   parts that are used by SCAMP/os */
struct uart8250 {
    int dataready : 1;
    int txempty : 1;
    int dlab : 1; /* "divisor latch access bit"? */
    int is_console : 1;
    int infd;
    int outfd;
    uint16_t base_address;
    uint16_t clockdiv;
    uint8_t rxbuf;
    uint8_t txbuf;
    uint64_t last_rx;
    /* TODO: [bug] we should drop characters if trying to output them faster
       than the baud rate allows */
};

int test, debug, stacktrace, cyclecount, show_help, test_fail, freq=20000000, watch=-1, zero, memorylog;
int halt;
uint64_t steps;
struct termios orig_termios;

uint8_t DI, DO, AI, MI, MO, II, IOH, IOL, JMP, PO, PP, XI, EO, YI, RT;
uint8_t EX, NX, EY, NY, F, NO;

uint16_t rom[256];
uint16_t ucode[2048];
uint16_t ram[65536];
uint16_t bus;

uint16_t X, Y, PC, instr, uinstr, addr;
uint8_t JZ, JLT, JGT;
uint8_t T, Z, LT;

uint16_t diskptr = 0;
uint8_t *disk;
uint16_t blknum = 0;
uint16_t blkidx = 0;

#ifdef PROFILING
uint64_t pc_cycles[65536];
uint16_t last_instr[65536];
uint64_t opcode_cycles[256];
uint64_t addr_reads[65536];
uint64_t addr_writes[65536];
FILE *profile_fp;
int run_profile = 1;
uint64_t prof_cycles;

uint64_t segmented_cycles[256];
int segment = 0;
#endif

#ifdef EMSCRIPTEN
int ready;

#define UART_BUFSZ 1024
char uart_outbuf[UART_BUFSZ];
char uart_inbuf[UART_BUFSZ];
char *uart_outp;
#endif

struct uart8250 console;

#ifndef EMSCRIPTEN
struct uart8250 serialport;
#endif

void randomise_ram(void) {
    int i;

    srand(time(NULL));

    for (i = 0; i < 65536; i++)
        ram[i] = rand();
}

void load_hex(uint16_t *buf, int maxlen, char *name) {
    FILE *fp;
    int i = 0;

    if (!(fp = fopen(name, "r"))) {
        fprintf(stderr, "can't read %s: %s\n", name, strerror(errno));
        exit(1);
    }

    for (i = 0; i < maxlen; i++)
        if (fscanf(fp, "%04hx", buf+i) != 1)
            break;

    fclose(fp);
}

void load_ucode(char *name) {
    load_hex(ucode, 2048, name);
}

void load_bootrom(char *name) {
    load_hex(rom, 256, name);
}

void load_ram(uint16_t addr, char *file) {
    load_hex(ram+addr, 65536-addr, file);
}

void load_disk(char *file) {
    int fd = open(file, O_RDWR, 0);
    if (fd < 0) {
        fprintf(stderr, "can't open %s: %s\n", file, strerror(errno));
        exit(1);
    }

    disk = mmap(NULL, 65536 * 512, PROT_READ|PROT_WRITE, MAP_SHARED, fd, 0);
    if (disk == MAP_FAILED) {
        fprintf(stderr, "can't mmap %s: %s\n", file, strerror(errno));
        exit(1);
    }
    close(fd);
}

#ifdef PROFILING
void open_profile(char *file) {
    if (!(profile_fp = fopen(file, "w"))) {
        fprintf(stderr, "can't write %s: %s\n", file, strerror(errno));
        exit(1);
    }
}
#endif

#ifdef PROFILING
void write_profile(int argc, char **argv, uint64_t elapsed_us) {
    int i;

    if (!profile_fp) return;

    fprintf(profile_fp, "scamp-profile\n");
    fprintf(profile_fp, "endtime: %ld\n", time(0));
    fprintf(profile_fp, "cmdline: %s", argv[0]);
    for (i = 1; i < argc; i++)
        fprintf(profile_fp, " %s", argv[i]);
    fprintf(profile_fp, "\n");
    fprintf(profile_fp, "cycles: %lu\n", prof_cycles);
    fprintf(profile_fp, "elapsed_us: %lu\n", elapsed_us);
    fprintf(profile_fp, "pc_cycles:\n");
    for (i = 0; i < 65536; i++)
        fprintf(profile_fp, "%lu\n", pc_cycles[i]);
    fprintf(profile_fp, "last_instr:\n");
    for (i = 0; i < 65536; i++)
        fprintf(profile_fp, "%d\n", last_instr[i]);
    fprintf(profile_fp, "opcode_cycles:\n");
    for (i = 0; i < 256; i++)
        fprintf(profile_fp, "%lu\n", opcode_cycles[i]);
    fprintf(profile_fp, "addr_reads:\n");
    for (i = 0; i < 65536; i++)
        fprintf(profile_fp, "%lu\n", addr_reads[i]);
    fprintf(profile_fp, "addr_writes:\n");
    for (i = 0; i < 65536; i++)
        fprintf(profile_fp, "%lu\n", addr_writes[i]);
    fclose(profile_fp);
}
#endif

/* compute ALU operation */
uint16_t alu(uint16_t argx, uint16_t argy) {
    uint16_t val;

    if (!EX) argx = 0;
    if (!EY) argy = 0;

    if (NX) argx = ~argx;
    if (NY) argy = ~argy;

    if (F) val = argx + argy;
    else   val = argx & argy;

    if (NO) val = ~val;

    return val;
}

#ifndef EMSCRIPTEN
int opentty(char *name) {
    int fd = open(name, O_RDWR);
    if (fd == -1) {
        fprintf(stderr, "open %s: %s\n", name, strerror(errno));
        exit(1);
    }
    return fd;
}
#endif

/* return 1 if data available to read, 0 if not, -1 if poll error */
int uart_ready(struct uart8250 *uart) {
    struct pollfd pfd;
    float chars_per_sec = 11520.0 / uart->clockdiv; /* 1/10 of baud rate */
    uint64_t steps_per_char = freq / chars_per_sec;

    /* we can't have received any more chars yet if the baud rate would't allow it */
    if (steps - uart->last_rx < steps_per_char) return 0;

    pfd.fd = uart->infd;
    pfd.events = POLLIN;

    return poll(&pfd, 1, 0);
}

#ifdef EMSCRIPTEN
void uart_poll(struct uart8250 *uart) {
    uart->dataready = *uart_inbuf ? 1 : 0;
    uart->txempty = 1;
}
#else
/* read into rx buffer, and maybe set halt flag on ctrl-\ */
void uart_poll(struct uart8250 *uart) {
    uint8_t ch;

    if (!uart_ready(uart)) return;

    if (read(uart->infd, &ch, 1) != 1) {
        halt = 1;
        return;
    }
    if (uart->is_console && ch == 28) halt = 1; /* halt on ctrl-\ */

    /* note: we deliberately drop characters if the rxbuf hasn't been
       consumed yet; this emulates real 8250 behaviour; we could consider
       setting bit 1 ("Overrun Error") of the line status register (reg 5)
       if we are setting rxbuf while dataready is already 1 */
    uart->last_rx = steps;
    uart->rxbuf = ch;
    uart->dataready = 1;
}
#endif

#ifdef EMSCRIPTEN
/* return next char from input buffer */
uint8_t uart_getchar(struct uart8250 *uart) {
    uint8_t ch = 0;
    char *p;
    if (*uart_inbuf) {
        ch = *uart_inbuf;
        p = uart_inbuf;

        // move all remaining bytes 1 step toward the front
        // XXX: O(n) but n should be small (usually n=1)
        while (*(p+1)) {
            *p = *(p+1);
            p++;
        }
        *p = 0;
    }
    return ch;
}
#else
/* return next char from input buffer */
uint8_t uart_getchar(struct uart8250 *uart) {
    uart_poll(uart);
    uart->dataready = 0;
    return uart->rxbuf;
}
#endif

uint8_t uart_in(struct uart8250 *uart, int addr) {
    switch (addr) {
        case 0:
            if (uart->dlab) return uart->clockdiv >> 8; /* divisor latch lsb */
            else            return uart_getchar(uart); /* rxbuf */
        case 1:
            if (uart->dlab) return uart->clockdiv & 0xff; /* divisor latch msb */
            else            return 0; /* interrupt enable register */
        case 2: /* interrupt ident register */
            /* TODO */
            return 0;
        case 3: /* line control register */
            /* TODO */
            return 0;
        case 4: /* modem control register */
            /* TODO */
            return 0;
        case 5: /* line status register */
            /* TODO: [nice] there are potentially more bits that might be useful */
            uart_poll(uart);
            return uart->dataready | ((uart->txempty&1) << 5) | ((uart->txempty&1) << 6);
        case 6: /* modem status register */
            /* TODO */
            return 0;
        case 7: /* scratch register */
            /* TODO */
            return 0;
        default:
            return -1;
    }
}

#ifdef EMSCRIPTEN
void uart_putchar(struct uart8250 *uart, int ch) {
    *(uart_outp++) = ch;
    if (uart_outp == uart_outbuf + UART_BUFSZ - 1) uart_outp--;
    *uart_outp = 0;
}
#else
void uart_putchar(struct uart8250 *uart, int ch) {
    write(uart->outfd, &ch, 1);
}
#endif

void uart_out(struct uart8250 *uart, int addr, uint8_t val) {
    /* TODO: [nice] implement more of this, in particular we should really keep
             track of the configured baud rate and drop characters if we try to
             output too fast */
    if (addr == 3) {
        uart->dlab = !!(val & 0x80);
    }
    if (addr == 0 && uart->dlab) {
        uart->clockdiv = (uart->clockdiv & 0xff00) | val;
    }
    if (addr == 1 && uart->dlab) {
        uart->clockdiv = (uart->clockdiv & 0x00ff) | (val << 8);
    }
    if (addr == 0 && !uart->dlab) {
        uart->txbuf = val;
        uart->txempty = 0;

        /* XXX: when we are tracking baud rate, the following can move: */
        uart_putchar(uart, uart->txbuf);
        uart->txempty = 1;
    }
}

/* input a word from addr */
uint16_t in(uint16_t addr) {
    uint16_t r = 0;
    if (addr == 1) {
        r = disk[diskptr++];
    }
    if (addr == 5) {
        if (disk)
            r = disk[512*blknum + blkidx];
        blkidx = (blkidx+1)%512;
    }
    if (addr == 264) { /* Data Register */
        if (disk)
            r = (disk[512*blknum + blkidx] << 8) | (disk[512*blknum + blkidx + 1]);
        blkidx = (blkidx+2)%512;
    }
    if (addr == 271) { /* Status Register */
        r = 0x58; /* RDY | DSC | DRQ */
    }
    if (addr >= console.base_address && addr < console.base_address + 8) {
        r = uart_in(&console, addr-console.base_address);
    }
#ifndef EMSCRIPTEN
    if (addr >= serialport.base_address && addr < serialport.base_address + 8) {
        r = uart_in(&serialport, addr-serialport.base_address);
    }
#endif
    return r;
}

/* output a word to addr */
int expect_output = 0;
void out(uint16_t val, uint16_t addr) {
    if (test && addr == 0) {
        if (val != expect_output) {
            printf("Out %d: got %d\n", expect_output, val);
            test_fail = 1;
        }
        expect_output++;
    }
    if (addr == 3) {
        halt = 1;
    }
    if (addr == 4) {
        blknum = val;
        blkidx = 0;
    }
    if (addr == 5) {
        if (disk)
            disk[512*blknum + blkidx] = val;
        blkidx = (blkidx+1)%512;
    }
    if (addr == 264) { /* Data Register */
        if (disk) {
            disk[512*blknum + blkidx] = val >> 8;
            disk[512*blknum + blkidx + 1] = val & 0xff;
        }
        blkidx = (blkidx+2)%512;
    }
    if (addr == 267) { /* Sector Number Register */
        blknum = (blknum & 0xff00) | (val & 0x00ff);
        blkidx = 0;
    }
    if (addr == 268) { /* Cylinder Low Register */
        blknum = (blknum & 0x00ff) | ((val & 0x00ff) << 8);
        blkidx = 0;
    }
    if (addr >= console.base_address && addr < console.base_address + 8) {
        uart_out(&console, addr-console.base_address, val);
    }
#ifndef EMSCRIPTEN
    if (addr >= serialport.base_address && addr < serialport.base_address + 8) {
        uart_out(&serialport, addr-serialport.base_address, val);
    }
#endif

#ifdef PROFILING
    if (addr == 1 && run_profile) halt = 1;
    if (addr == 2) {
        /* targeted profiling: reset profiling counters to remove all the stuff we don't want */
        memset(pc_cycles, 0, sizeof(pc_cycles));
        memset(last_instr, 0, sizeof(last_instr));
        memset(opcode_cycles, 0, sizeof(opcode_cycles));
        memset(addr_reads, 0, sizeof(addr_reads));
        memset(addr_writes, 0, sizeof(addr_writes));
        memset(segmented_cycles, 0, sizeof(segmented_cycles));
        prof_cycles = 0;

        run_profile = 1;
    }
    if (addr == 6) run_profile = 0;
    if (addr == 7) run_profile = 1;
    if (addr == 10) segment = val;
#endif
}

/* negative edge of clock: update control lines and outputs to bus */
void negedge(void) {
    uint16_t uPC;
    uint8_t opcode;
    uint8_t bus_in, bus_out;

    do {
        /* look up uinstr */
        opcode = (instr >> 8) & 0xff;
        uPC = (opcode << 3) | T;
        uinstr = ucode[uPC];

        /* decode uinstr */
        EO = (!(uinstr >> 15)) & 0x1;
        EX = (uinstr >> 14) & 1;
        NX = (uinstr >> 13) & 1;
        EY = (uinstr >> 12) & 1;
        NY = (uinstr >> 11) & 1;
         F = (uinstr >> 10) & 1;
        NO = (uinstr >>  9) & 1;
        bus_out = (uinstr >> 12) & 0x7;
        PP = !EO && ((uinstr >> 10) & 0x1);
        bus_in = (uinstr >> 5) & 0x7;
        JZ = (uinstr >> 4) & 0x1;
        JGT = (uinstr >> 3) & 0x1;
        JLT = (uinstr >> 2) & 0x1;
        RT = (uinstr >> 1) & 1;
        DI = uinstr & 1;

        /* increment t-state */
        if (RT) T = 0;
        else    T = (T+1) % 8;
    } while (RT); /* loop until !RT because RT resets T-state immediately */

#ifdef PROFILING
    if (run_profile) {
        prof_cycles++;
        pc_cycles[PC]++;
        last_instr[PC] = instr;
        opcode_cycles[opcode]++;
        segmented_cycles[segment]++;
    }
#endif

    if (T == 1 && debug)
        fprintf(stderr, "[trace] PC=%04x\n", PC);

    if (T == 3 && stacktrace) {
        if (opcode == 0xb7)
            fprintf(stderr, "[stack] PC=%04x: push x: %04x\n", PC, X);
        if (opcode == 0xb8)
            fprintf(stderr, "[stack] PC=%04x: push i8l: %02x\n", PC, instr&0xff);
        if (opcode == 0xb9)
            fprintf(stderr, "[stack] PC=%04x: push i8h: %02x\n", PC, 0xff00|(instr&0xff));
        if (opcode == 0xba)
            fprintf(stderr, "[stack] PC=%04x: pop x: %04x\n", PC, ram[ram[0xffff]+1]);
    }

    /* calculate JMP */
    JMP = (JZ&Z) | (JLT&LT) | (JGT&!Z&!LT);

    /* decode bus_in */
    AI = (bus_in == 1);
    II = (bus_in == 2);
    MI = (bus_in == 3);
    XI = (bus_in == 4);
    YI = (bus_in == 5);
    /* spare: .. = (bus_in == 7); */

    /* decode bus_out */
    PO = (!EO && bus_out == 0);
    IOH = (!EO && bus_out == 1);
    IOL = (!EO && bus_out == 2);
    MO = (!EO && bus_out == 3);
    /* spare: .. = (!EO && bus_out == 4); */
    /* spare: .. = (!EO && bus_out == 5); */
    DO = (!EO && bus_out == 6);
    /* spare: .. = (!EO && bus_out == 7); */

    /* decide who is outputting to bus */
    if (EO)  bus = alu(X, Y), Z = (bus == 0), LT = !!(bus & 0x8000);
    if (PO)  bus = PC;
    if (IOH) bus = 0xff00 | (instr&0xff);
    if (IOL) bus = instr&0xff;
    if (MO) {
        bus = (addr < 256 ? rom[addr] : ram[addr]);
#ifdef PROFILING
        if (run_profile) addr_reads[addr]++;
#endif
    }
    if (DO)  bus = in(addr);
}

/* positive edge of clock: update register contents */
void posedge(void) {
    if (AI)  addr = bus;
    if (II)  instr = bus;
    if (MI) {
        if (watch == addr)
            fprintf(stderr, "[watch] PC=%04x: M[%04x] was %04x, now %04x\n", PC, addr, ram[addr], bus);
        ram[addr] = bus;
#ifdef PROFILING
        if (run_profile) addr_writes[addr]++;
#endif
        if (stacktrace && addr == 0xffff)
            fprintf(stderr, "[stack] PC=%04x: sp=%04x: stack = %04x %04x %04x %04x %04x...\n", PC, ram[0xffff], ram[ram[0xffff]+1], ram[ram[0xffff]+2], ram[ram[0xffff]+3], ram[ram[0xffff]+4], ram[ram[0xffff]+5]);
    }
    if (XI)  X = bus;
    if (YI)  Y = bus;
    if (DI)  out(bus, addr);
    if (PP)  PC++;
    if (JMP) PC = bus;

    /* debug output */
    if (debug) {
        printf("PC = %04x\n", PC);
        printf("instr = %04x\n", instr);
        printf("T = %d\n", T);
        printf("uinstr = %04x\n", uinstr);
        printf("bus = %04x\n", bus);
        printf("addr = %04x\n", addr);
        printf("X = %04x\n", X);
        printf("Y = %04x\n", Y);
        printf("Z = %d, LT = %d\n", Z, LT);
        if (EO)
            printf(" EO%s%s%s%s%s%s", (EX?" EX":""), (NX?" NX":""), (EY?" EY":""), (NY?" NY":""), (F?" F":""), (NO?" NO":""));
        if (PO) printf(" PO");
        if (IOH) printf(" IOH");
        if (IOL) printf(" IOL");
        if (MO) printf(" MO");
        if (DO) printf(" DO");
        if (RT) printf(" RT");
        if (PP) printf(" P+");
        if (AI) printf(" AI");
        if (II) printf(" II");
        if (MI) printf(" MI");
        if (XI) printf(" XI");
        if (YI) printf(" YI");
        if (DI) printf(" DI");
        if (JGT) printf(" JGT");
        if (JLT) printf(" JLT");
        printf("\n\n");
    }
}

void help(void) {
    printf("usage: scamp [options]\n"
"\n"
"Options:\n"
"  -c,--cycles        Print number of cycles taken\n"
"  -d,--debug         Print debug output after each clock cycle\n"
"  -f,--freq HZ       Aim to emulate a clock of the given frequency (default: 20000000)\n"
"  -i,--image FILE    Load disk image from given hex file\n"
#ifdef PROFILING
"  -m,--memorylog     Log the contents of memory to mem/frame.%%04d periodically\n"
"  -p,--profile FILE  Write profiling data to FILE\n"
#endif
"  -r,--run FILE      Load the given hex file into RAM at 0x100 and run it instead of the boot ROM\n"
"  -S,--serial FILE   Use FILE (e.g. /dev/pts/...) for the secondary serial port\n"
"  -s,--stack         Trace the stack\n"
"  -t,--test          Check whether the test ROM passes the tests\n"
"  -w,--watch ADDR    Watch for changes to the given address and print them on stderr\n"
"  -z,--zero          Initialise memory to zeroes instead of random\n"
"  -h,--help          Show this help text\n"
"\n"
"This emulator loads the microcode from ../ucode.hex and boot ROM from ../bootrom.hex.\n"
"If --test, boot ROM is replaced with a test ROM from ../testrom.hex.\n"
"\n"
"By James Stanley <james@incoherency.co.uk>\n");
    exit(1);
}

void sighandler(int sig) {
    (void)sig; /* suppress warning: unused parameter ‘sig’ [-Wunused-parameter] */
    halt = 1;
}

void unrawmode(void) {
    tcsetattr(STDIN_FILENO, TCSAFLUSH, &orig_termios);
}
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
int main(int argc, char **argv) {
    int jmp0x100 = 0;
    struct timeval starttime, curtime;
    uint64_t elapsed_us, target_us;

    console.is_console = 1;
    console.base_address = 136;
    console.infd = 0; /* stdin */
    console.outfd = 1; /* stdout */
    console.txempty = 1;

#ifndef EMSCRIPTEN
    serialport.is_console = 0;
    serialport.base_address = 144;
    serialport.infd = -1;
    serialport.outfd = -1;
    serialport.txempty = 1;
#endif

#ifdef EMSCRIPTEN
    load_disk("os.disk");
    load_ucode("ucode.hex");
    load_bootrom("bootrom.hex");

    ready = 1;
#else
    setbuf(stdout, NULL);

    /* parse options */
    while (1) {
        static struct option opts[] = {
            {"cycles",  no_argument, &cyclecount,1},
            {"debug",   no_argument, &debug,     1},
            {"freq",    required_argument, 0, 'f'},
            {"image",   required_argument, 0, 'i'},
#ifdef PROFILING
            {"memorylog",no_argument,      0, 1},
            {"profile", required_argument, 0, 'p'},
#endif
            {"run",     required_argument, 0, 'r'},
            {"serial",  required_argument, 0, 'S'},
            {"stack",   no_argument, &stacktrace,1},
            {"test",    no_argument, &test,   1},
            {"watch",   required_argument, 0, 'w'},
            {"zero",    no_argument,   &zero, 1},
            {"help",    no_argument, &show_help, 1},
            {0, 0, 0, 0},
        };

        int optidx = 0;
        int c = getopt_long(argc, argv, "cdf:i:hp:r:stw:", opts, &optidx);

        if (c == -1) break;
        if (c == 'c') cyclecount = 1;
        if (c == 'd') debug = 1;
        if (c == 'f') freq = atoi(optarg);
        if (c == 'i') load_disk(optarg);
#ifdef PROFILING
        if (c == 'm') memorylog = 1;
        if (c == 'p') open_profile(optarg);
#endif
        if (c == 'r') {
            load_ram(0x100, optarg);
            jmp0x100 = 1;
        }
        if (c == 'S') serialport.infd = serialport.outfd = opentty(optarg);
        if (c == 's') stacktrace = 1;
        if (c == 't') test = 1;
        if (c == 'w') watch = atoi(optarg);
        if (c == 'z') zero = 1;

        if (c == 'h') show_help = 1;
    }

    if (show_help) help();

    /* load ROMs */
    load_ucode("../ucode.hex");
    if (!jmp0x100) {
        if (test) load_bootrom("../testrom.hex");
        else      load_bootrom("../bootrom.hex");
    } else {
        PC = 0x100;
    }

    if (!zero) randomise_ram();

    signal(SIGINT, sighandler);
    rawmode();
    gettimeofday(&starttime, NULL);

#ifdef PROFILING
    int frame = 0;
#endif

    /* run the clock */
    while (!halt) {
        if ((steps & 0xffff) == 0) /* console_poll() is slow, only call it very occasionally */
            uart_poll(&console);

        negedge();
        posedge();

        steps++;
        if (test && steps > 3000)
            halt = 1;

        gettimeofday(&curtime, NULL);
        elapsed_us = ((curtime.tv_sec * 1000000) + curtime.tv_usec) - ((starttime.tv_sec * 1000000) + starttime.tv_usec);

        if (freq) {
            target_us = (steps * 1000000ull) / freq;
            if (elapsed_us < target_us)
                usleep(target_us - elapsed_us);
        }

#ifdef PROFILING
        if (memorylog && steps % 200 == 0) dumpmem(frame++);
#endif
    }

    if (cyclecount)
        fprintf(stderr, "[cycles] Halted after %lu cycles.\r\n", steps);

#ifdef PROFILING
    if (profile_fp)
        write_profile(argc, argv, elapsed_us);

    int i;
    uint64_t totalcycles = 0;
    int numsegments = 0;
    for (i = 0; i < 256; i++) {
        if (segmented_cycles[i] > 0) {
            fprintf(stderr, "[cycles] segment %d: %lu\r\n", i, segmented_cycles[i]);
            totalcycles += segmented_cycles[i];
            numsegments++;
        }
    }
    if (numsegments > 1) {
        fprintf(stderr, "[cycles] total: %lu\r\n", totalcycles);
    }
#endif

#endif /* EMSCRIPTEN */
    return test_fail;
}

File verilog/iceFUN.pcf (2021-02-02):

# For iceFUN board

set_io --warn-no-port led1 	C10
set_io --warn-no-port led2 	A10
set_io --warn-no-port led3 	D7
set_io --warn-no-port led4 	D6
set_io --warn-no-port led5 	A7
set_io --warn-no-port led6 	C7
set_io --warn-no-port led7 	A4
set_io --warn-no-port led8 	C4
set_io --warn-no-port lcol1	A12
set_io --warn-no-port lcol2 	D10
set_io --warn-no-port lcol3 	A6
set_io --warn-no-port lcol4 	C5
set_io --warn-no-port clk  	P7
set_io --warn-no-port key1 A5
set_io --warn-no-port key2 A11
set_io --warn-no-port key3 C6
set_io --warn-no-port key4 C11

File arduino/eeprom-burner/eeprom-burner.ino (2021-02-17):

/* jes's eeprom burner
 *  
 *  TODO: add a way to bulk read/write data, so that it doesn't take so long
 */

#define BUFSZ 32

const int addr_pin[10] = {10, 9, 8, 7, 6, 5, 4, 3, 0, 1};
const int data_pin[8] = {11, 12, 13, A5, A4, A3, A2, A1};
const int we_pin = 2;
const int oe_pin = A0;

void setup() {
  Serial.end();
  for (int b = 0; b < 10; b++)
    pinMode(addr_pin[b], OUTPUT);
  pinMode(we_pin, OUTPUT);
  pinMode(oe_pin, OUTPUT);
  digitalWrite(we_pin, HIGH);
  digitalWrite(oe_pin, HIGH);
  
  begin_serial();
}

void loop() {
  static char buf[BUFSZ];
  static int p;
  
  while (Serial.available() > 0) {
    char c = Serial.read();
    if (c == '\r' || c== '\n' || p == BUFSZ-1) {
      buf[p++] = 0;
      serialCommand(buf);
      p = 0;
    } else {
      buf[p++] = c;
    }
  }
}

void begin_serial() {
  delay(1);
  Serial.begin(115200);
}

void end_serial() {
  digitalWrite(we_pin, HIGH);
  Serial.end();
  delay(1);
}

void set_addr(int addr) {
  for (int b = 0; b < 10; b++)
    digitalWrite(addr_pin[b], !!(addr & (1<<b)));
}

void write_data(int addr, int data) {
  end_serial();
  digitalWrite(we_pin, HIGH);
  digitalWrite(oe_pin, HIGH);
  set_addr(addr);
  for (int b = 0; b < 8; b++)
    pinMode(data_pin[b], OUTPUT);
  for (int b = 0; b < 8; b++)
    digitalWrite(data_pin[b], !!(data & (1<<b)));
  delay(1);;
  digitalWrite(we_pin, LOW);
  delayMicroseconds(1); // datasheet: "max write pulse width" is 1000 ns
  digitalWrite(we_pin, HIGH);
  delay(1);
  begin_serial();
}

int read_data(int addr) {
  end_serial();
  set_addr(addr);
  digitalWrite(oe_pin, LOW);
  digitalWrite(we_pin, HIGH);
  delay(1);
  int data = 0;
  for (int b = 0; b < 8; b++)
    pinMode(data_pin[b], INPUT);
  delay(1);
  for (int b = 0; b < 8; b++)
    if (digitalRead(data_pin[b]))
      data |= (1<<b);
  digitalWrite(oe_pin, HIGH);
  begin_serial();
  return data;
}

void serialCommand(char *buf) {
  char **params = split(buf);

  if (strcmp(params[0], "help") == 0) {
    Serial.print(
      "eeprom-burner commands:\r\n"
      "   help           - show help\r\n"
      "   read ADDR      - read from ADDR\r\n"
      "   write ADDR VAL - write VAL to ADDR\r\n"
      "\r\n"
      "values and addresses should be in decimal\r\n"
    );
      
  } else if (strcmp(params[0], "read") == 0) {
    if (!params[1]) {
      Serial.println("error: usage: read ADDR");
      return;
    }
    int addr = atoi(params[1]);
    Serial.println(read_data(addr));
  } else if (strcmp(params[0], "write") == 0) {
    if (!params[1] || !params[2]) {
      Serial.println("error: usage: write ADDR VAL");
      return;
    }
    int addr = atoi(params[1]);
    int val = atoi(params[2]);
    write_data(addr, val);
    Serial.println("ok");
  }
}

// replace each space in buf with a \0, and return a (static!) nul-terminated array of pointers to the string parts
char **split(char *buf) {
  static char *parts[16];
  int n = 0;
  
  char *p = buf;
  while (*p && n < 15) {
    parts[n++] = p;
    while (*p && *p != ' ')
      p++;
    if (*p == ' ')
      *(p++) = 0;
  }
  parts[n++] = 0;
  
  return parts;
}

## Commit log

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2021-02-20 Add front panel bracket CAD
    [bracket.FCStd, bracket.stl]
2021-02-21 Print globals in the order they appear; perl slangc output is now bytewise identical to slangc.sl output
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2021-02-22 Make backplane card suitable as a prototyping card
    [backplane-B_Cu.gbr, backplane-B_Mask.gbr, backplane-B_SilkS.gbr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]
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2021-02-23 Don't print a nul character for the empty string
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2021-02-23 Add memory-panel, test-holes
    [memory-panel.FCStd, memory-panel.stl, test-holes.FCStd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]
2021-02-23 Emulate a more plausible storage device (writable; 512 byte blocks)
2021-02-24 Add memory panel engraving, generate g-code
    [memory-panel.FCStd]
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2021-02-28 Fix printf usage
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2021-03-04 Add card rail CAD
    [card-rail.FCStd, card-rail.stl]
2021-03-04 Update card rail
    [card-rail.FCStd, card-rail.stl]
2021-03-05 close(fd) - it won't affect the mmap
    [scamp.c]
2021-03-05 system(): only switch to kernel stack once
    would previously switch for both system() and exec(), meaning errors
    from exec() would not return to the correct place.
2021-03-05 Offset mounting hole in card-rail
    [card-rail.FCStd]
2021-03-06 Improve error handling a bit
    [card-rail.FCStd, card-rail.stl]
2021-03-07 Add horizontal-brace
    [horizontal-brace.FCStd, horizontal-brace.stl]
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2021-03-09 Add instruction-panel
    [instruction-panel.FCStd]
2021-03-11 Update instruction-panel
    [instruction-panel.FCStd]
2021-03-12 asm: output raw binary (can now assemble & run programs within the emulator)
2021-03-13 Put die errors on stderr
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2021-03-13 Make asm assemble much bigger programs (still not enough to assemble itself)
2021-03-16 Add ALU panel
    [alu-panel.FCStd]
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2021-03-18 Document PCB errata
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2021-03-18 Poll the console on every syscall, to allow ^C to interrupt programs that aren't blocked on input
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2021-03-25 More efficient free() by short-circuiting 2/3 of the magnitude comparisons
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2021-03-28 asm: string interning (still not enough to assemble itself)
2021-03-28 Put strbuf.sl in filesystem, rename die() to fatal() in kilo
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2021-03-28 blkfindfree(): cache the current block of the free block index
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2021-04-02 kilo: bail early on input if ESC with no escaped character
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2021-04-03 Document bootrom print bug
2021-04-04 Add serial card PCB files
    [serial-B_Cu.gbr, serial-B_Mask.gbr, serial-B_SilkS.gbr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]
2021-04-08 Add start of serial panel
    [serial-panel.FCStd]
2021-04-08 Add start of serial port connector
    [serial-connector.FCStd]
2021-04-08 Add 4 copies of serial port
    [serial-connector.FCStd, serial-panel.FCStd]
2021-04-08 Increase clearance in connector holes
    [serial-connector.FCStd, serial-panel.FCStd]
2021-04-12 Update serial-panel
    [serial-panel.FCStd]
2021-04-12 Fix serial device base address
    [scamp.c]
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2021-04-17 bootrom: print data from disk to serial port
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2021-04-21 bootrom: stop printing disk contents; put full-size error messages back
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2021-06-05 Add start of storage card PCB
    [cfcard.sch, storage.kicad_pcb, storage.sch]
2021-06-06 Finish storage card
    [cfcard.sch, storage.kicad_pcb, storage.sch]
2021-06-16 Add start of storage panel
    [cf-spacer.FCStd, cf-spacer.stl, serial-connector.stl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]
2021-06-16 It's working in real hardware
    [cf-spacer.FCStd, storage-panel.FCStd, storage-panel.stl]
2021-06-17 kilo: stop key mappings from colliding with flow control
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2021-06-18 kilo: faster waitreadbyte()
    This is still not quite fast enough to consume arrow keys at 115200 baud.
    I think for a 1 MHz clock frequency, we need to spend fewer than 86 cycles
    per byte in order to not miss any. Currently waitreadbyte() looks like it
    takes about 52 cycles in the worst case, but there is overhead in readkey().
    It should be doable if the critical path of escape sequence handling is all
    moved to assembly language.
2021-06-18 Add SER_DISABLE flag to stop kernel from interfering with UART
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2021-06-20 Fix cf-spacer size
    [cf-spacer.FCStd, cf-spacer.stl]
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2021-06-23 Update storage-panel
    [storage-panel.FCStd]
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2021-07-22 Add case CAD
    [case.FCStd]
2021-07-26 Update case
    [case.FCStd]
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2021-08-10 fs tool: fix add_dirent() in the case of directories that take up >2 blocks
    Previously, when adding the third and subsequent block, the "next" pointer
    in the first block would be updated, rather than in the last block.
2021-08-11 Document plan for faster mul()
    [case.FCStd]
2021-08-12 kilo: delete entire line if line is empty and ^K
    [case.FCStd]
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2021-08-17 hamurabi: fix typo
    [case.FCStd]
2021-08-18 Add 24lc256 eeprom burning stuff
    [eeprom-burner-24lc256.ino]
2021-08-21 Add 74HCT245 bus transceivers to storage card
    [cfcard.sch, storage.kicad_pcb, storage.sch]
2021-08-23 eeprom-burner-24lc256: specify pull-up instead of pull-down
    [eeprom-burner-24lc256.ino]
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2021-08-23 Replace shl(1,i) with powers_of_2[i]
2021-08-25 stat: fix printing for larger values
2021-08-25 ls: use memoised stat() instead of stat()'ing everything upfront
    This allows us to start giving output (except in the case of '-S') as soon
    as the names are sorted, rather than waiting until after every file has been
    stat()'d
2021-08-28 system(): reset pid if exec() throws an error
2021-08-31 fixed: use global powers_of_2 instead of asm label
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2021-09-12 Add first attempt at card lever CAD
    [card-lever.FCStd, card-lever.stl, rod-holder.stl]
2021-09-14 Update card-lever CAD
    [card-lever.FCStd, card-lever.stl, rod-holder.stl]
2021-09-15 Update card-lever
    [card-lever.FCStd, card-lever.stl, rod-holder.stl]
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2021-09-17 Document reversed wiring of LEDs on serial card
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2021-10-14 emulator: fix cycle count formatting
    [scamp.c]
2021-10-14 emulator: fix serial port input
    [scamp.c]
2021-10-20 asm: reduce memory footprint (executable is down from 28.4 Kwords to 21.5 Kwords)
    We can now build the kernel from inside SCAMP/os, as long as head.s is changed
    to put the start address a bit lower (just because peepopt under SCAMP/os isn't
    good enough at saving us memory yet, so the kernel is larger when built this
    way)
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2021-10-23 kernel: read data from block device directly to user buffer, where possible
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2021-11-26 serial: only enable cooked mode by default for the console, not all devices
2021-11-29 kernel: don't crash when restoring a large program into memory
    The problem was that in the event that you ask read() for more than 254 words,
    and the current pointer is at the start of a block on disk, read() will ask cf_blkread()
    to read directly into the user buffer, rather than memcpy()ing to it.
    The problem is that if the program we're restoring is very large, this can lead to
    cf_blkread() putting 254 words into memory, even when the remaining words in the file
    is lower than that, which overwrites some of the kernel causing a crash.
    In particular, this case is triggered by typing ^Z to spawn a subshell. The kernel
    doesn't know how much memory the running program is using, so it saves i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
2021-12-03 serial: call callback on every character instead of on chunks
    This was already the de facto behaviour anyway, but by making it explicit
    we simplify the callback implementation and might be able to speed up the
    sending side.
2021-12-06 system: simplify error handling
    This was causing crashes before and not working, with "exit_on_catch" apparently
    back to 0 after exec() throws an error which is caught in system(). I didn't track down
    exactly what the problem was, but this way is simpler and better anyway.
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2022-06-24 malloc: allocate space from start of free block rather than end
    The previous behaviour was pathological in the case of repeatedly
    allocating a really large buffer, and then reallocing it down to
    only what is needed, with a handful of tiny allocations in between.
    . = free
    L = part of large allocation
    S = small allocation
    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
2022-06-27 Revert "rude: set return value for non-function-call statements"
    This reverts commit a1a440ccd0cbc6f2ab523a9250f99b07b84c3dda.
    Functions aren't required to leave their return value in x, so calling
    functions written in assembly language might not work, so we'll just
    put it back to how it was.
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2022-10-31 Fix emulator when built with zig cc
    [scamp.c]
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2023-11-17 slangi: let logical or/and short-circuit
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
